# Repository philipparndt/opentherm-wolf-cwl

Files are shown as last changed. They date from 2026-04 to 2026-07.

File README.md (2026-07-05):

# Wolf CWL OpenTherm Decoder

Decoder tool for analyzing OpenTherm protocol communication between a BM remote control and a Wolf CWL ventilation/heat-recovery unit. Built to reverse-engineer the protocol for building a custom ESP32-based controller.

## Usage

```bash
# Default: human-readable deduplicated output
decode <file.sal|file.csv>

# Verbose: raw hex, parity, bit-timing analysis
decode <file> --verbose

# Diff: compare two captures side by side, highlights changes
decode diff <baseline.sal> <changed.sal>
```

Supports Saleae Logic 2 captures (`.sal`) and CSV exports (`.csv`). SAL files are significantly faster to process.

## Findings

### Control Summary

Everything needed to control the Wolf CWL via OpenTherm:

| Function | Method |
|---|---|
| **Ventilation level** | Write-Data to ID 71, value 0-3 |
| **Bypass open** | Set bit 1 in HI byte of ID 70 Read-Data request |
| **Bypass close** | Clear bit 1 in HI byte of ID 70 Read-Data request |
| **Filter reset** | Set bit 4 in HI byte of ID 70 Read-Data request (reset filter timer after replacement) |
| **Read temperatures** | Read-Data ID 80 (supply inlet), ID 82 (exhaust inlet) |
| **Read ventilation %** | Read-Data ID 77 |
| **Read bypass state** | Check `ventilation` bit (bit 1 HI byte) in ID 70 response |
| **Read fault status** | ID 72 (`Fault flags/code V/H`) — the HI-byte `fault` bit in ID 70 is *not* reliable on Wolf CWL, see notes below |
| **Read filter status** | Check **bit 5 of the LO byte** in ID 70 response (Wolf OEM use of a spec-reserved slave-status bit; the response HI byte is only an echo of the master flags) |

### Supported OpenTherm Data IDs

The Wolf CWL (tested with CWL Excellent, BM remote control as master) responds to the following data IDs:

| Data ID | Name | Type | Direction | Description |
|---|---|---|---|---|
| 2 | Master configuration | config/member-id | Write | Master flags=0x00, member-id=18 |
| 70 | Status V/H | flag8 | Read | Bidirectional: master sends control flags, slave returns status |
| 71 | Control setpoint V/H | u8 | Write | Ventilation level (0-3) |
| 72 | Fault flags/code V/H | flag8 | Read | Fault flags + OEM fault code |
| 74 | Config/member-ID V/H | config/member-id | Read | Slave flags=0x07, member-id=0 |
| 77 | Relative ventilation | u8 (%) | Read | Current ventilation percentage |
| 80 | Supply inlet temperature | f8.8 (°C) | Read | Fresh air intake temperature |
| 82 | Exhaust inlet temperature | f8.8 (°C) | Read | Room exhaust temperature |
| 89 | TSP index/value V/H | tsp | Read | Transparent Slave Parameters (see below) |
| 126 | Master product version | version | Write | type=18 version=2 |
| 127 | Slave product version | version | Read | type=0 version=0 (CWL does not respond) |

### Status V/H (ID 70) — Bidirectional Control

The Status V/H exchange carries control flags in **both directions**. This is the key mechanism for bypass control.

**Master → Slave (HI byte of Read-Data request):**

| Bit | Name | Description |
|-----|---|---|
| 0 | ch | Central heating / ventilation enable |
| 1 | **bypass** | **Bypass damper control: 1=open, 0=closed** |
| 2 | cooling | Cooling enable (if cooling register installed) |
| 3 | dhw | DHW enable |
| 4 | filter | Filter timer reset (set briefly after filter replacement) |
| 5 | diag | Diagnostics request |

**Slave → Master (Read-Ack response):**

The **HI byte of the Read-Ack is an echo of the master status flags** from the request — it carries no slave state. (Earlier revisions of this document interpreted it as a slave status byte and described a "permanently latched fault bit"; that was our own always-set ventilation-enable bit coming back.)

The actual slave status is the **LO byte**, laid out as in the OpenTherm V/H spec:

| Bit | Name | Description |
|-----|---|---|
| 0 | fault | Fault indication |
| 1 | ventilation | Ventilation mode active |
| 2 | bypass | Bypass status (1 = open) |
| 3 | bypass auto | Bypass automatic mode |
| 4 | free vent | Free ventilation status |
| 5 | **filter** | **Filter replacement required (1 = service due, 0 = OK).** Reserved in the spec; used by Wolf (Brink Renovent / Viessmann Vitovent OEM siblings) as the filter-check bit. |
| 6 | diag | Diagnostic indication |

Bit 5 was confirmed in `FIL_CLEAN.sal`, which captures the live transition during a filter-reset: LO went from `0x26` → `0x06` (bit 5 cleared) while HI stayed at `0x03` and ID 72 (Fault flags/code) stayed at `0x0000` throughout.

> **Do not derive filter status from ID 72.** An OEM fault code of 6 was once assumed to mean "filter dirty" (FIL2 hypothesis), but a live unit was observed reporting ID 72 = `0x0006` together with LO bit 6 (diagnostic indication) while the filter was clean and the CWL display showed no FIL — code 6 is a diagnostic status code, not the filter message. LO bit 5 is the only reliable filter signal.

The bypass is controlled by setting/clearing **bit 1 of the HI byte** in every Status V/H request; the actual damper state is reported in LO bit 2 (and TSP 54).

### Ventilation Level Control

Ventilation level is controlled via **Data ID 71** (Control setpoint V/H). The mapping is:

| Setpoint value | Mode | Relative ventilation (ID 77) |
|---|---|---|
| 0 | Off | 0% |
| 1 | Reduced | 51% |
| 2 | Normal | 67% |
| 3 | Party | 100% |

The `fault` bit in Status V/H (ID 70) may toggle briefly during mode transitions. This appears to be a transient state, not an actual fault indication.

### TSP Register Map

The BM remote cycles through TSP registers via Data ID 89, reading one index per polling cycle (~11 seconds per cycle). A full TSP scan takes approximately 5-6 minutes (31 indices).

TSP values did **not** change when switching ventilation levels or toggling bypass. Ventilation is controlled via ID 71, bypass via ID 70. TSPs hold configuration and live diagnostic data.

The Wolf CWL is OEM-identical to the **Brink Renovent HR** and **Viessmann Vitovent 300**. The TSP register map from the [Brink Renovent OpenTherm project](https://github.com/raf1000/brink_openhab) applies directly.

Many indices come in even/odd pairs for 16-bit values (even=LO, odd=HI byte).

#### Airflow Configuration (m³/h)

| TSP Index | Brink name | Value | Description |
|---|---|---|---|
| 0, 1 | U1 | 100, 0 | Airflow rate step 1 (Reduced): **100 m³/h** |
| 2, 3 | U2 | 130, 0 | Airflow rate step 2 (Normal): **130 m³/h** |
| 4, 5 | U3 | 195, 0 | Airflow rate step 3 (Party): **195 m³/h** |

#### Bypass & Temperature Settings

| TSP Index | Brink name | Value | Description |
|---|---|---|---|
| 6 | U4 | 20 | Bypass min. outdoor temp (value ÷ 2 = °C → **10 °C**). Bypass only opens when outdoor air ≥ this temperature. |
| 7 | U5 | 44 | Bypass min. indoor temp (value ÷ 2 = °C → **22 °C**). Bypass only opens when indoor air ≥ this temperature. |

#### Configuration Parameters

| TSP Index | Brink name | Value | Description |
|---|---|---|---|
| 11 | I1 | 100 | Fixed imbalance (value shifted by 100, so 100 = **0% imbalance**) |
| 17 | I7 | 1 | Pressure control / fan mode setting |
| 18 | I8 | 1 | Bypass configuration |
| 19 | I9 | 2 | Hysteresis / preheater setting |
| 20 | I10 | 0 | Additional config |
| 23 | I13 | 1 | Filter message setting |
| 24 | I14 | 0 | PCB configuration |
| 48, 49 | P18 | 193, 0 | Device/PCB config flags |

#### Live / Status Values (read-only, change during operation)

| TSP Index | Brink name | Value range | Description |
|---|---|---|---|
| 52, 53 | CurrentVol | 100-130, 0 | Current outlet volume **[m³/h]** |
| 54 | BypassStatus | 1 | Bypass valve position (0=shut, 1=auto, 2=open?) |
| 55 | TempAtmo | 114-118 | Atmospheric temperature (value − 100 = °C, so 114 → **14 °C**) |
| 56 | TempIndoors | 121 | Indoor temperature (value − 100 = °C, so 121 → **21 °C**) |
| 60, 61 | — | 0-130, 0 | Changes within captures — possibly supply/exhaust flow |
| 62, 63 | CurrentOutputVol | 100-113, 0 | Current output volume **[m³/h]** |
| 64, 65 | CPID | 20-215, 0-1 | Input duct pressure **[Pa]** |
| 66, 67 | CPOD | 196-255, 0 | Output duct pressure **[Pa]** |
| 68 | FrostStatus | 0 | Frost protection status (0 = no frost) |

### Data IDs to Probe

The BM remote only polls a subset of the available V/H data IDs. The following IDs are defined in the OpenTherm V/H spec and may be supported by the CWL, but have not been tested yet. Probe these with the ESP32 firmware to discover additional sensors:

| Data ID | Name | Type | Notes |
|---|---|---|---|
| 78 | Relative humidity exhaust | u8 (%) | Humidity sensor (if installed) |
| 79 | CO2 level exhaust | u16 (ppm) | CO2/VOC sensor (if installed) |
| 81 | Supply outlet temperature | f8.8 (°C) | Temperature after heat recovery |
| 83 | Exhaust outlet temperature | f8.8 (°C) | Temperature after heat recovery |
| 84 | Exhaust fan speed | u16 (rpm) | Fan speed diagnostics |
| 85 | Supply fan speed | u16 (rpm) | Fan speed diagnostics |
| 87 | Nominal ventilation value | u8 | Configured nominal airflow |
| 88 | TSP count V/H | u8 | Total number of TSP registers supported |

If the CWL supports a data ID, it will respond with Read-Ack. If not, it will either not respond or send Unknown-DataId.

### Polling Cycle

The BM remote polls the CWL in a fixed cycle of approximately 11 seconds containing:

1. Master configuration (ID 2) — Write-Data
2. Status V/H (ID 70) — Read-Data with master control flags
3. Control setpoint V/H (ID 71) — Write-Data
4. Config/member-ID V/H (ID 74) — Read-Data
5. Relative ventilation (ID 77) — Read-Data
6. Supply inlet temperature (ID 80) — Read-Data
7. Exhaust inlet temperature (ID 82) — Read-Data
8. Master product version (ID 126) — Write-Data
9. Slave product version (ID 127) — Read-Data (no response from CWL)
10. TSP index/value V/H (ID 89) — Read-Data, rotates through different index each cycle
11. Fault flags/code V/H (ID 72) — Read-Data (sometimes included)

## ESP32 Firmware Guide

The firmware serves a web UI with live status and a 24 h history view — supply/exhaust temperatures, indoor/outdoor humidity and enthalpy, bypass state, and ventilation level changes annotated with the reason for each switch:

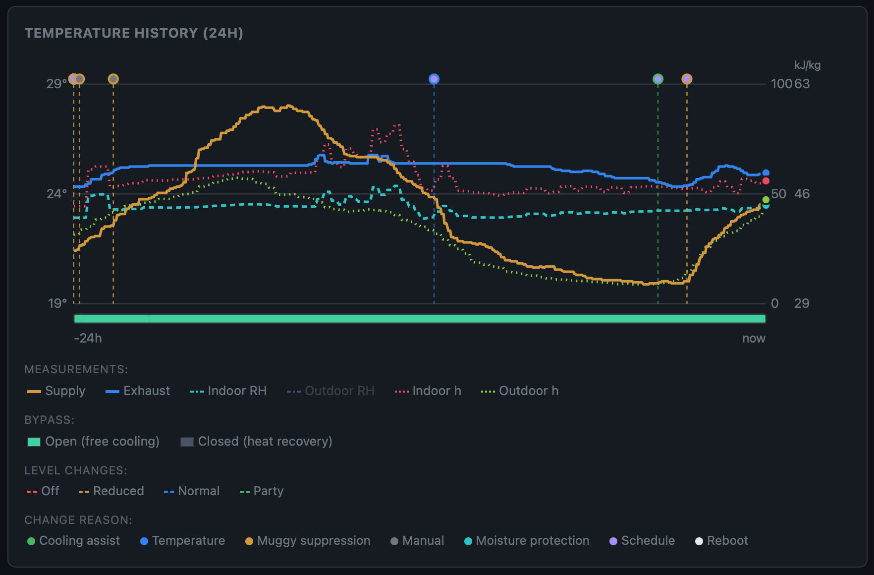
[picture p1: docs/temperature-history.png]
Temperature history (24 h) in the web UI


### Minimal Polling Loop

To replicate the BM's communication, the ESP32 firmware should send these requests in a loop (~1 second between each):

```
1. Write-Data  ID=2   value=0x0012        (master config: member-id=18)
2. Read-Data   ID=70  value=0x0N00        (status: HI byte = control flags, N = bypass bit)
3. Write-Data  ID=71  value=0x000L        (ventilation level: L = 0-3)
4. Read-Data   ID=74  value=0x0000        (read config/member-id)
5. Read-Data   ID=77  value=0x0000        (read relative ventilation %)
6. Read-Data   ID=80  value=0x0000        (read supply inlet temp)
7. Read-Data   ID=82  value=0x0000        (read exhaust inlet temp)
8. Read-Data   ID=89  value=0xII00        (read TSP index II)
```

### Bypass Control

In step 2, set the HI byte of the request value:
- `0x0100` — bypass closed, ventilation enabled (ch=on)
- `0x0300` — bypass open, ventilation enabled (ch=on, bypass=on)

The slave response HI byte confirms the state:
- Bit 0: fault
- Bit 1: ventilation/bypass active

### Ventilation Levels

In step 3, set the LO byte:
- `0x0000` — Off (0%)
- `0x0001` — Reduced (51%)
- `0x0002` — Normal (67%)
- `0x0003` — Party (100%)

## Hardware

### Capture Setup (passive analysis)

- **Saleae Logic 2** analyzer tapping the OpenTherm bus between BM remote and CWL unit
- Analog capture at 1.5625 MHz sample rate
- OpenTherm signal: Manchester encoded at ~1000 baud
- Request (master→slave): ~10.8V peak
- Response (slave→master): ~7.3V peak

### Controller Hardware

- **DIYLess Master OpenTherm Shield** — handles OpenTherm electrical signaling
- **ESP32** (e.g. WeMos D1 mini ESP32) — runs custom firmware
- **[ihormelnyk/opentherm_library](https://github.com/ihormelnyk/opentherm_library)** — Arduino library for OpenTherm master communication

The DIYLess shield acts as the OpenTherm master, replacing the BM remote control. The ESP32 can then:
- Read all sensor values (temperatures, ventilation %, status, faults)
- Set ventilation level by writing to Data ID 71 (values 0-3)
- Control bypass via Status V/H (ID 70) master flags
- Read TSP registers for diagnostics
- Publish data via MQTT to Home Assistant (see [docs/mqtt-topics.md](docs/mqtt-topics.md) for the full topic reference)

### ESPHome Compatibility

The official ESPHome OpenTherm component does **not** support V/H (ventilation/heat-recovery) data IDs 70-91. It only supports boiler/heating control. A custom firmware is required for the Wolf CWL.

## Building

```bash
cd decode
go build -o decode .
```

Requires Go 1.26+.

## Schedules

Weekday schedule:
```
0:00 - 8:00 reduced
8:00 - 13:00 normal
13:00 - 15:00 reduced
15:00 - 18:00 normal
18:00 - 0:00 reduced
```

Weekend schedule:
```
0:00 - 10:00 reduced
10:00 - 13:00 normal
13:00 - 15:00 reduced
15:00 - 18:30 normal
```

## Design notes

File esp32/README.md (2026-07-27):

# Wolf CWL — ESP32 Firmware

Rust firmware for the Olimex ESP32-POE board that drives a Wolf CWL ventilation unit over OpenTherm. Networking is selectable at build time (Ethernet on the Olimex POE port, or WiFi).

## Prerequisites

One-time, outside this Makefile:

1. **Rust + the Xtensa ESP toolchain via [espup](https://github.com/esp-rs/espup).**
   ```bash
   cargo install espup
   espup install
   ```
   `espup install` writes `~/export-esp.sh`, which sets `LIBCLANG_PATH` and prepends the Xtensa cross-compiler to `PATH`.

2. **Source the espup env from your shell rc** so `make` picks it up:
   ```bash
   echo 'source ~/export-esp.sh' >> ~/.zshrc && exec zsh
   ```

3. **Plug in the board** and confirm the OS sees it:
   ```bash
   ls /dev/cu.*
   ```
   Look for `cu.usbserial-*` (CP210x — native on macOS 11+, no extra driver) or `cu.wchusbserial-*` (CH340/CH341 — older boards may need the [WCH driver](https://www.wch.cn/downloads/CH341SER_MAC_ZIP.html)).

## First-time setup

```bash
cd esp32
make setup
cp .env.example .env
$EDITOR .env          # WIFI_SSID, WIFI_PASSWORD, optional PORT
```

`make setup` installs the two Rust binaries the build needs (`ldproxy`, `espflash`) and patches a Python venv quirk that otherwise breaks the ESP-IDF dependency check (see [Troubleshooting](#troubleshooting)).

## Build targets

| Target | Network | OpenTherm |
|---|---|---|
| `make dev` | Ethernet | Simulated |
| `make prod` | Ethernet | Real |
| `make dev-wifi`  | WiFi | Simulated |
| `make prod-wifi` | WiFi | Real |

All four build, flash, and open the serial monitor. WiFi targets require `WIFI_SSID` / `WIFI_PASSWORD` in `esp32/.env` — those credentials are forwarded by `build.rs` and compiled into the firmware as a fallback when NVS has no stored credentials (so a freshly-flashed board joins the network without going through the web setup wizard first).

`make help` lists every target.

## `.env`

Loaded by the Makefile as Makefile syntax (not shell), so:

- No quotes around values.
- Avoid `#` and `$` in passwords — both are Make-special. If you must use them, change the password.
- The file is git-ignored.

| Variable | Used by | Notes |
|---|---|---|
| `WIFI_SSID` | `build.rs` (env!) | Required for `dev-wifi` / `prod-wifi`. |
| `WIFI_PASSWORD` | `build.rs` (env!) | Required for `dev-wifi` / `prod-wifi`. |
| `PORT` | `espflash` flag | Optional. Defaults to `/dev/cu.wchusbserial8310`. Override per board. |

## Feature flags

Defined in `Cargo.toml`. The Makefile targets compose these; you rarely need to set them by hand:

- `wifi` / `ethernet` — pick one network stack.
- `simulate-ot` — fake OpenTherm slave for desk testing.
- `ot-uext` / `ot-ext` — which GPIO pair to use for OpenTherm (UEXT default).
- `display-rotate` — rotate the OLED 180° for upside-down mounting.
- `display-sh1106` / (default `ssd1306`) — pick OLED driver chip.

## Web UI login

The UI and the REST API are protected by a cookie login (default `admin` / `admin`, changeable under **Settings → Web UI**).

On a trusted LAN the prompt is mostly friction, so it can be switched off: **Settings → Web UI → Require login**. With it off, `is_authenticated()` short-circuits and every endpoint — including `/api/config`, `/api/restore` and both OTA uploads — is open to anyone who can reach port 80. The toggle is persisted in NVS (`web_auth`) and takes effect immediately, without a reboot; it defaults to **on**, so a firmware update never silently unlocks a device.

The `make ota*` targets log in first and then send the cookie. That still works with the login disabled — `/api/login` accepts any credentials in that mode — so `OTA_USER` / `OTA_PASS` can be left at their defaults.

## Troubleshooting

### `Error while connecting to device`

`espflash` can't talk to whatever's at `PORT`. Confirm the port name (`ls /dev/cu.*`) and set `PORT=...` in `.env`, or pass `make ... PORT=/dev/cu.foo`. If the port is correct, hold the BOOT button while espflash resets the chip.

### `Failed to open file: partitions.csv`

A 4MB layout with NVS + factory app + a 960KB SPIFFS partition labeled `spiffs` is committed at `esp32/partitions.csv`. The SPIFFS offset/size must stay in sync with `SPIFFS_OFFSET` / `SPIFFS_SIZE` in the Makefile and the `partition_label` passed to `esp_vfs_spiffs_register` in `main.rs`. Don't edit it without updating all three.

### `Failed to run Python dependency check ... Error: 255` during `esp-idf-sys` build

The ESP-IDF Python venv ships with a `ruamel.yaml` whose `.dist-info` directory uses underscores (`ruamel_yaml-*.dist-info`), but Python 3.9's `importlib.metadata.version('ruamel.yaml')` doesn't normalize dotted names → the dep check exits 255 → CMake aborts. `make fix-python-env` symlinks the dotted names; it runs automatically before every `build` target and is also re-runnable on its own. If you see this error after a fresh `.embuild`, run:

```bash
make fix-python-env
```

### `linker 'ldproxy' not found` or `espflash: command not found`

You haven't run `make setup` yet (or `~/.cargo/bin` isn't on `PATH`). Both binaries land in `~/.cargo/bin`, which espup adds automatically — but `make` runs in `/bin/sh` and only sees the inherited `PATH`. Make sure your shell rc sources `~/export-esp.sh` and exports `~/.cargo/bin`.

### Switching between `ethernet` and `wifi` triggers a long rebuild

Expected. Cargo rebuilds `esp-idf-sys` from scratch when feature flags change, which re-runs the CMake dep check (see above). Initial WiFi build is ~10 minutes; subsequent incremental builds are seconds.

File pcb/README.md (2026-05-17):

# Wolf CWL Controller — Shield PCB

Shield board that stacks on top of an [Olimex ESP32-POE](https://www.olimex.com/Products/IoT/ESP32/ESP32-POE/open-source-hardware) via the UEXT connector. Provides the OpenTherm interface, OLED display, and rotary encoder.

## UEXT Connector Pinout (ESP32-POE)

The [UEXT](https://www.olimex.com/Products/Modules/UEXT/) is a 10-pin 2x5 box header (2.54 mm pitch) providing I²C, SPI, and UART:

| UEXT Pin | Signal | ESP32 GPIO | Used For |
|---|---|---|---|
| 1  | 3.3V | — | Power |
| 2  | GND  | — | Ground |
| 3  | TXD  | GPIO 4  | OpenTherm TX (via SB3) |
| 4  | RXD  | GPIO 36 | OpenTherm RX (via SB4) |
| 5  | SCL  | GPIO 16 | OLED Display |
| 6  | SDA  | GPIO 13 | OLED Display |
| 7  | MISO | GPIO 15 | Encoder CLK |
| 8  | MOSI | GPIO 2  | Status LED |
| 9  | SCK  | GPIO 14 | Encoder DT |
| 10 | SS | GPIO 5  | Encoder SW |

## Variants

| Variant | Project | Notes |
|---|---|---|
| `cwl` (default) | `cwl/cwl.kicad_pro` | Main board. Melnyk-topology on-board OpenTherm front-end. Combined OLED footprint accepts either a 0.96″ or 1.3″ SH1106 module. |
| `cwl-diyless` | `cwl-diyless/cwl.kicad_pro` | Off-board OpenTherm interface via a DIYless D1-mini shield. Separate J3 / J3B footprints for the two OLED sizes. |

## Bill of Materials (`cwl`)

| Ref | Part | Value / Mfr P/N | Footprint | Symbol | Mouser # | Qty |
|-----|---|---|---|---|---|-----|
| J1 | UEXT 2×5 IDC socket | HIF3FB-10DA-2.54DSA(69) (Hirose) | `IDC:IDC-Stecker_2x05_P2.54mm_Vertical` | `Connector_Generic:Conn_02x05_Odd_Even` | 798-HIF3FB10DA254D69 | 1 |
| J2 | Screw terminal, 2-pos 5.08 mm | MKDS 1,5/2-5,08 (Phoenix Contact) | `TerminalBlock_Phoenix:TerminalBlock_Phoenix_MKDS-1,5-2-5.08_1x02_P5.08mm_Horizontal` | `Connector:Conn_01x02_Pin` | 651-1729018 | 1 |
| J3 | OLED header (0.96″ + 1.3″ combined) | 4-pin header (use module's own header) | `SSD1306:128x64OLED-MountingHoles-Combined` | `Connector:Conn_01x04_Pin` | — | 1 |
| U1, U2 | Optocoupler, SOIC-4 | LTV-817S-B (Lite-On) | `Package_SO:SOP-4_7.5x4.1mm_P2.54mm` | `Isolator:PC817` | 859-LTV-817S-B | 2 |
| Q1 | PNP BJT, SOT-23 | BC858A or BC858B (Nexperia) | `Package_TO_SOT_SMD:SOT-23` | `Transistor_BJT:BC858` | 771-BC858A,215 | 1 |
| D1–D4 | Switching diode, SOD-323 | 1N4148WS (Vishay) | `Diode_SMD:D_SOD-323` | `Device:D` | 78-1N4148WS-HG3_A-08 | 4 |
| D5 | 4.7 V zener, SOD-123, 500 mW | BZT52C4V7 (Vishay) | `Diode_SMD:D_SOD-123` | `Device:D_Zener` | 78-BZT52C4V7-E3-08 | 1 |
| D6 | 15 V zener, SOD-123, 500 mW | BZT52C15 (Vishay) | `Diode_SMD:D_SOD-123` | `Device:D_Zener` | 78-BZT52C15-E3-08 | 1 |
| D7 | 4.3 V zener, SOD-123, 500 mW | BZT52C4V3 (Vishay) | `Diode_SMD:D_SOD-123` | `Device:D_Zener` | 78-BZT52C4V3-E3-08 | 1 |
| R1, R4 | 330 Ω, 0603, 1 % | RC0603FR-07330RL (Yageo) | `Resistor_SMD:R_0603_1608Metric` | `Device:R` | 603-RC0603FR-07330RL | 2 |
| R2 | 220 Ω, 0603, 1 % | RC0603FR-07220RL (Yageo) | `Resistor_SMD:R_0603_1608Metric` | `Device:R` | 603-RC0603FR-07220RL | 1 |
| R3 | 100 Ω, 0603, 1 % | RC0603FR-07100RL (Yageo) | `Resistor_SMD:R_0603_1608Metric` | `Device:R` | 603-RC0603FR-07100RL | 1 |
| R5 | 1.5 kΩ, 0603, 1 % | RC0603FR-071K5L (Yageo) | `Resistor_SMD:R_0603_1608Metric` | `Device:R` | 603-RC0603FR-071K5L | 1 |
| R6, R7 | 10 kΩ, 0603, 1 % | RC0603FR-0710KL (Yageo) | `Resistor_SMD:R_0603_1608Metric` | `Device:R` | 603-RC0603FR-0710KL | 2 |
| R8 | 1 kΩ, 0603, 1 % | RC0603FR-071KL (Yageo) | `Resistor_SMD:R_0603_1608Metric` | `Device:R` | 603-RC0603FR-071KL | 1 |
| SW1 | Rotary encoder w/ switch | EC12E2424407 (Alps Alpine) | `Rotary_Encoder:RotaryEncoder_Alps_EC12E-Switch_Vertical_H20mm` | `Device:RotaryEncoder_Switch` | — | 1 |
| LED1 | Green LED, 0805 | SML-LXT0805GW-TR (Lumex) | `LED_SMD:LED_0805_2012Metric` | `Device:LED` | 696-SML-LXT0805GW | 1 |
| MH1–MH4 | M3 mounting hole, GND-tied | — | `MountingHole:MountingHole_3.2mm_M3_Pad_Via` | `Mechanical:MountingHole_Pad` | — | 4 |
| SB3, SB4 | UEXT TX/RX → OT routing bridges (etched into board, no part) | — | `Jumper:SolderJumper-2_P1.3mm_Bridged_RoundedPad1.0x1.5mm` | `Jumper:SolderJumper_2_Bridged` | — | — |
| — | 0.96″ SH1106 OLED module, I²C, 4-pin | — | — | — | (Amazon / AliExpress) | 1 (pick one) |
| — | 1.3″ SH1106 OLED module, I²C, 4-pin | — | — | — | (Amazon / AliExpress) | 1 (pick one) |

## Build targets

```
make generate-3d      # regenerate the local STEP models in 3dmodels/
make export-stl-full  # full PCB assembly STL (VARIANT=cwl by default)
make export-stl-print # version with floating IDC socket for 3D printing
make export-stl-board # bare PCB only
make export-stl-parts # components only (no board)
make gerber           # Gerbers + drills (zipped)
make plot-pdf         # front + back assembly PDFs
make ibom             # Interactive HTML BOM (needs InteractiveHtmlBom plugin)
make clean            # remove generated artifacts
```

Set `VARIANT=cwl-diyless` to target the diyless project instead.

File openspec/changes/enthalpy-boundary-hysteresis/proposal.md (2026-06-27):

## Why

The humidity-aware decision (`humidity::enthalpy_level`) splits "ventilate to cool" from "hold
down (muggy)" at **exactly Δh = 0** (`Δh = h_out − h_in`), with no deadband:

```rust
} else if dh > 0.0 {        // Reduced  (MuggySuppression)
} else if dh >= H_PARTY {   // Normal   (CoolingAssist)
```

Every other boundary in the system is guarded — the bypass damper (`EH_BYPASS_HYST`), moisture
protection (`RH_HYSTERESIS`), the Off edge (`H_OFF = +2`) and the Party edge (`H_PARTY = −4`) — but
the Reduced↔Normal crossing at zero is bare. Two consecutive live readings demonstrate the problem:

| | Indoor h | Outdoor h | Δh | Rule shown | Level |
|---|---|---|---|---|---|
| 1 | 63.2 | 63.5 | +0.3 | Muggy suppression | Reduced |
| 2 | 63.2 | 63.3 | ≈0 (rounded) | Cooling assist | Normal |

Between the two, the outdoor air actually got **0.1 °C warmer** (31.0 → 31.1 °C) and barely drier,
yet the decision flipped from "hold down" to "ventilate to cool". The true Δh merely crossed zero by
a hair. Two problems compound:

1. **The boundary is resolved finer than the inputs are accurate.** Δh is acted on at ~0.1 kJ/kg,
   while a typical DHT humidity sensor (±2–5 % RH) carries ~±1–2 kJ/kg of enthalpy uncertainty. The
   controller is reacting to noise. The 15-min dwell rate-limits the *fan*, but the displayed reason
   refreshes every 60 s (`extreme_heat.rs` keeps the level, refreshes the reason), so the user sees
   the rule flicker Muggy↔Cooling even while the fan is held; and if Δh sits on the boundary the fan
   can still hunt every dwell window.
2. **"Cooling assist" oversells near Δh = 0.** Equal enthalpy ≈ equal wet-bulb temperature, so
   pulling in 31 °C air to a 27 °C room does not actually cool — it trades humidity for sensible
   heat. Real cooling only exists once outdoor energy is clearly lower (which is exactly why the
   Party edge already keeps a −4 margin).

And when the mode is *deliberately* holding — because Δh is inside the neutral deadband, or because
the dwell timer hasn't elapsed — the UI gives no reason for the non-switch. The user cannot tell
"holding on purpose" from "stuck / broken".

## What Changes

- Add **state-dependent hysteresis around Δh = 0** to `enthalpy_level`: enter cooling
  (Normal/CoolingAssist) only when `Δh < H_COOL_ON`, release back to hold-down
  (Reduced/MuggySuppression) only when `Δh > H_COOL_OFF`, and **hold the current state** in the
  neutral band between them. `Party` (`Δh < H_PARTY`) and `Off` (`Δh > H_OFF`) bands are unchanged.
- Make `CoolingAssist` mean *actual* cooling: the "ventilate to cool" reason is only claimed once
  cooling has been entered past `H_COOL_ON`, never on a marginal sub-band crossing.
- **Surface the hold reason in the decision explainer:** when the level is not switched because the
  energy delta is inside the neutral deadband, or because the dwell timer has not elapsed, the panel
  states that explicitly (which guard is holding, and — for the dwell — how much longer).
- Clarify the explainer's outdoor/indoor figures so the displayed `T / RH / AH / h` no longer reads
  as one inconsistent air mass (RH is the max-RH sensor; AH/h come from the wettest sensor
  re-expressed at the aggregate temperature — they legitimately come from different sensors).
- **Boot robustness & honest level (from live-device findings):** don't derive an air state from an
  untrustworthy fallback temperature, and don't show the derived enthalpy in the explainer until the
  unit is connected — this removes the boot-transient "indoor h ≈ 37.9" glitch. The ventilation
  display shows the unit's **actual** running level (ID 77), not the commanded one (ID 71), since the
  two can differ. The explainer always shows a state (a "waiting for the unit" notice while
  disconnected) and every reason has a plain-language explanation.

## Capabilities

### Modified Capabilities
<!-- humidity-aware-ventilation and humidity-decision-visualization are defined in the still-active
     `extreme-heat-humidity` change, not yet archived to openspec/specs/. Following that change's
     own precedent (layering onto un-archived extreme-heat-mode), the boundary-stability behaviour
     is expressed as ADDED requirements that refine the existing enthalpy bands, rather than as a
     MODIFIED delta against a baseline spec that does not yet exist. -->

- `humidity-aware-ventilation`: add boundary hysteresis so the Reduced↔Normal (hold-down↔cooling)
  decision no longer toggles on noise around equal energy, and tie the `CoolingAssist` reason to
  having actually entered cooling.
- `humidity-decision-visualization`: explain *why a switch is being withheld* (neutral deadband or
  dwell), and present the aggregated air figures without implying a single consistent air mass.

## Impact

- Firmware: `esp32/src/humidity.rs` (`enthalpy_level` gains a `was_cooling` argument and the
  `H_COOL_ON` / `H_COOL_OFF` constants + the neutral-band hold), `esp32/src/extreme_heat.rs` (pass
  the current cooling state into `decide`/`enthalpy_level`, and expose a "hold reason" — deadband vs
  dwell-remaining — alongside the active reason), `esp32/src/app_state.rs` (carry the hold reason /
  dwell-remaining for the status payload).
- API/Web: `/api/status` gains the hold reason + dwell-remaining; `StatusTab.tsx` decision-explainer
  renders the "holding because …" line and the clarified air-figure labels; `translations.ts`.
- Behaviour: no change to the Off/Party bands, the 15-min dwell, manual stickiness, or the
  temperature-only fallback. Tuning constants only widen the neutral region around Δh = 0.

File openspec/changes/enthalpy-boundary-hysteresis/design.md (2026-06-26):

## Context

`humidity::enthalpy_level` (`esp32/src/humidity.rs`) maps the enthalpy delta `Δh = h_out − h_in`
onto a ventilation level + a cooling flag:

```rust
pub fn enthalpy_level(inp: &HumidityInputs) -> (VentLevel, bool) {
    let dh = inp.outdoor.h - inp.indoor.h;
    if dh > H_OFF { (Off, false) }          // H_OFF  =  2.0
    else if dh > 0.0 { (Reduced, false) }   // <-- bare boundary at exactly 0
    else if dh >= H_PARTY { (Normal, true) }// H_PARTY = -4.0
    else { (Party, true) }
}
```

`extreme_heat::decide` turns the cooling flag into the displayed `Reason` (`CoolingAssist` vs
`MuggySuppression`) and the caller floors the level at `Reduced` (a fully-off CWL leaves stale duct
air). So the *only* boundary that changes the actual fan level between hold-down and active cooling
is the `dh > 0.0` test — and it has no hysteresis and no state memory, unlike every other decision
edge in the codebase (`EH_BYPASS_HYST`, `RH_HYSTERESIS`, and the `±2 / −4` margins on the Off/Party
edges). The dwell (`EH_DWELL_SECS = 15 min`) rate-limits fan *changes* but the reason is refreshed
every eval (60 s), so the displayed rule flickers Muggy↔Cooling on noise, and a Δh parked near zero
still hunts once per dwell window.

Two real readings (indoor h = 63.2 both times; outdoor h 63.5 → 63.3; outdoor T 31.0 → **31.1 °C**)
flipped the decision from MuggySuppression/Reduced to CoolingAssist/Normal even though the outdoor
air got *warmer*. The displayed figures only carry one decimal (0.1 kJ/kg), finer than DHT-class
sensors are accurate (±2–5 % RH ≈ ±1–2 kJ/kg). The control is chasing noise.

## Goals / Non-Goals

**Goals**
- A neutral band around `Δh = 0` within which the Reduced↔Normal (hold-down↔cooling) state is
  *held*, so sensor noise no longer flips the level or the displayed reason.
- `CoolingAssist` is only claimed when cooling has genuinely been entered (Δh clearly negative), not
  on a marginal zero-crossing.
- The explainer states *why a switch is being withheld* — neutral deadband, or dwell not elapsed
  (with remaining time) — so a deliberate hold is distinguishable from a fault.
- The explainer's air figures no longer read as a single inconsistent air mass.

**Non-Goals**
- No change to the Off (`> +2`) or Party (`< −4`) bands, the 15-min dwell, manual stickiness, the
  bypass-damper logic, or the temperature-only fallback.
- No new persisted/NVS state — the cooling state is derived from the current reason, the
  dwell-remaining is computed from the existing `eh_last_change_epoch`.
- No sensor-fusion or accuracy improvements — this is purely about boundary stability and legibility.

## Decisions

### Hysteresis band around Δh = 0

Introduce two constants and a `was_cooling` input, mirroring `protection_level(&inp, was_active)`:

```rust
/// Enter cooling (favour ventilating) only once outdoor air is at least this much
/// lower-energy than indoor (kJ/kg). Above H_COOL_OFF, release back to hold-down.
pub const H_COOL_ON: f32 = -1.0;
pub const H_COOL_OFF: f32 = 0.0;

pub fn enthalpy_level(inp: &HumidityInputs, was_cooling: bool) -> (VentLevel, bool) {
    let dh = inp.outdoor.h - inp.indoor.h;
    if dh > H_OFF { return (VentLevel::Off, false); }
    if dh < H_PARTY { return (VentLevel::Party, true); }
    // Neutral band [H_COOL_ON, H_COOL_OFF]: hold whatever we were doing.
    let cooling = if was_cooling { dh < H_COOL_OFF } else { dh < H_COOL_ON };
    if cooling { (VentLevel::Normal, true) } else { (VentLevel::Reduced, false) }
}
```

- Not cooling → only switch to cooling when `Δh < −1.0`.
- Already cooling → only release when `Δh > 0.0`.
- Between the two it holds, so a Δh wandering across zero by noise changes nothing.

`H_COOL_ON = −1.0` is ~ one sensor-noise unit below zero — small enough that genuine cooling
opportunities are still taken, large enough to clear DHT jitter. Tunable; documented next to the
existing `H_OFF`/`H_PARTY`.

**Why this band and not just rounding Δh:** rounding still flips at the rounded boundary. State-
dependent hysteresis is what the rest of the codebase already uses; this makes the energy decision
consistent with it.

### Deriving `was_cooling` without new state

`extreme_heat::decide` already holds `st.eh_current_reason`. Treat `Reason::CoolingAssist` as the
"currently cooling" state; anything else (MuggySuppression, Dehumidify, TempDelta, Manual) is
not-cooling. No new field, survives the retained-snapshot restore for free (reason is already
restored).

### Hold reason for the explainer

`decide` currently returns `(level, reason)`. Extend the status path so the UI can show *why no
switch happened*. The level is withheld for exactly two reasons, both already computable in
`update()`:

- **Neutral deadband:** `enthalpy_level` returned the same level it’s holding because Δh is inside
  `[H_COOL_ON, H_COOL_OFF]`. Surface a flag like `hold = Deadband` with the current Δh and the band.
- **Dwell:** a *different* level was decided but `now_epoch − eh_last_change_epoch < EH_DWELL_SECS`.
  Surface `hold = Dwell` with `remaining = EH_DWELL_SECS − elapsed` seconds and the level it would
  switch to.

Expose these on `/api/status` (e.g. `holdReason`, `dwellRemainingSecs`, `pendingLevel`) so the
explainer can render "Holding Reduced — outdoor energy within the neutral band (Δh +0.1 kJ/kg)" or
"Holding Reduced — would switch to Normal in 7 min (dwell)". When nothing is held, the fields are
absent/null and the panel shows the active rule as today.

### Air-figure labelling (smaller)

The explainer prints `Outdoor (T / RH / AH / h)` as if one air mass, but `aggregate_side` sets `rh`
to the **max-RH** sensor while `ah`/`h` come from the **wettest** sensor re-expressed at the
aggregate (lowest) temperature — legitimately different sensors, so e.g. 31.1 °C / 24.6 % does not
reconcile with AH 13.5 g/m³ by hand. Relabel/group so this is clear (e.g. show RH as "max RH" and
AH/h as "from wettest sensor @ aggregate T"), or add a one-line note. No logic change.

## Risks / Trade-offs

- **Missed cooling in the −1…0 band.** When Δh is between −1 and 0 and we were not already cooling,
  we now hold Reduced instead of going Normal. That foregoes at most ~1 kJ/kg of marginal cooling
  that is within sensor noise anyway — an acceptable trade for stability. If field data shows it’s
  too conservative, lower `H_COOL_ON` toward −0.5.
- **`was_cooling` from the reason couples decision to display state.** Mitigated: the reason is
  already the single source of truth for the cooling flag and is persisted/restored; no divergence.
- **Tests that call `enthalpy_level(&inp)` must pass the new arg.** Mechanical; covered in tasks.

## Migration / Tuning

Pure firmware + web change; no config or NVS migration. New constants ship with defaults
`H_COOL_ON = −1.0`, `H_COOL_OFF = 0.0`. The boundary near the old `dh > 0.0` behaviour is recovered
by setting both to `0.0`.

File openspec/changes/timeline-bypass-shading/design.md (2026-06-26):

## Context

The temperature timeline already runs independently in the backend: `history.rs`
(`TempHistory`) folds supply/exhaust temperatures and indoor/outdoor humidity into rolling
ring buffers every second, persisted to MQTT under `persist/temp_history` separately from the
extreme-heat snapshot (`persist/extreme_heat`). The web chart (`ExtremeHeatChart.tsx`) is
rendered unconditionally in `StatusTab.tsx` and fetches `/api/history`, which embeds the
extreme-heat level-change events (`eh_events`) as its `events` array.

So the coupling is mostly *naming and framing*: the component, its events overlay, and the
mental model present the timeline as an extreme-heat artifact. Separately, there is **no
record of bypass state over time** — `requested_bypass_open` is a single live boolean set
from three places (extreme-heat in `extreme_heat.rs`, the calendar schedule in `scheduler.rs`,
and manual web/MQTT/encoder paths), with no history.

The bypass toggles only a handful of times per day, so a small transition log is sufficient to
reconstruct its state across the 24 h window — the same shape as the existing `eh_events`
ring buffer.

## Goals / Non-Goals

**Goals:**
- Reframe the chart as a standalone temperature timeline that does not depend on Extreme Heat
  mode; extreme-heat level changes remain an optional overlay.
- Record bypass open/closed transitions across the history window and persist them with the
  history snapshot.
- Render the chart background in two gray tones — base gray for bypass-closed spans, a
  slightly brighter gray for bypass-open spans — aligned to the time axis, behind the curves.

**Non-Goals:**
- No change to *how* the bypass is decided (that is the extreme-heat-bypass-coupling change).
- No new HTTP endpoint and no config/NVS schema change.
- No per-second bypass sampling into a min/max bucket — bypass is a sparse boolean state, so a
  transition log is the right model, not a `Channel`.
- No change to the extreme-heat level-change marker semantics.

## Decisions

### Model bypass history as a transition log, not a history Channel
Add a bounded ring buffer of `{epoch, open}` transitions to `AppStateInner` (e.g.
`bypass_events: VecDeque<BypassEvent>`, capped like `EH_EVENT_CAPACITY`). A transition is
appended only when `requested_bypass_open` actually changes. Rationale: bypass is a piecewise-
constant boolean that changes a few times a day; a transition log is far cheaper than a
1440-slot channel and reconstructs exact band edges, whereas per-bucket booleans would blur
edges and bloat the payload. Alternative considered: a boolean `Channel` per bucket — rejected
(memory + edge precision). Recording happens at a single chokepoint: a small helper that all
three writers (extreme-heat, scheduler, manual/MQTT) funnel `requested_bypass_open` through,
so no writer can change the damper without logging it.

### Reconstruct the left-edge state from the earliest known transition
To paint from the oldest visible column, the frontend needs the bypass state at the window's
left edge. The state in the span *before* the earliest transition in the buffer is the inverse
of that transition's `open` value (a transition flips the state). With the cap sized to cover
24 h of realistic toggling this is exact; if the buffer ever overflows, the worst case is one
mislabeled leading span, which is acceptable for a background tint.

### Expose via the existing `/api/history` payload
`TempHistory::full_json` already takes a pre-serialized `events` string; add a parallel
`bypass` array of `{epoch, open}` built in `webserver.rs` from `bypass_events` (same way
`events` is built from `eh_events`). Keeps one fetch and one render pass. Persist the
transitions inside the retained `persist/temp_history` snapshot (not the extreme-heat one), so
the shading survives reboots together with the curves it annotates.

### Render as background `<rect>` bands behind everything
In the chart, before drawing gridlines/series, emit one `<rect>` per bypass span spanning
`PAD_T..PAD_T+PLOT_H`, x-mapped with the existing `eventX` epoch→x helper, filled with a base
gray (closed) or a slightly brighter gray (open). Two CSS custom properties
(e.g. `--chart-bg`, `--chart-bg-bypass`) keep the tones theme-aware and the difference subtle.
Add a legend swatch + EN/DE strings explaining "bypass open / closed".

### Rename the component, keep extreme-heat markers as an overlay
Rename `ExtremeHeatChart.tsx` → `TimelineChart.tsx` (and the export) and update the import in
`StatusTab.tsx`. The level-change markers and their legend stay, but are now clearly an
overlay on a general-purpose timeline. No behavioural change to the markers.

## Risks / Trade-offs

- **Buffer overflow on a pathological day (many toggles)** → the cap covers far more than the
  realistic few-per-day; on overflow only the oldest leading span tint may be wrong, never the
  curves. Mitigation: size the cap generously and drop oldest first.
- **Subtle two-gray difference may be invisible in some themes** → expose both tones as CSS
  variables per theme and pair the shading with a legend entry so it is discoverable; keep the
  brighter tone clearly distinguishable but not loud (it is context, not a series).
- **Pre-existing retained snapshots lack the bypass list** → treat a missing `bypass` field as
  "no shading data yet"; the chart renders exactly as today until new transitions accrue.

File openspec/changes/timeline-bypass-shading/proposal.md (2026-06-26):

## Why

The temperature-history timeline is framed as part of Extreme Heat mode — the chart
component is `ExtremeHeatChart`, and the only context it overlays is extreme-heat
level-change events — even though the underlying history is sampled continuously and is
useful on its own. At the same time, the **bypass damper** is now a first-class cooling
control (it follows the supply/exhaust signal in Extreme Heat mode), but the timeline gives
no indication of *when the bypass was open*, which is exactly the context needed to read the
temperature curves ("did opening the bypass actually pull the supply temperature down?").

## What Changes

- **Decouple the timeline from Extreme Heat mode** so it is a standalone "temperature
  timeline" feature: rename the `ExtremeHeatChart` component to a neutral name
  (`TimelineChart`), and treat the chart as the home of temperature/humidity history that
  renders regardless of whether Extreme Heat is enabled. Extreme-heat level-change markers
  become one *optional overlay* on the timeline rather than the timeline's reason for being.
- **Shade the chart background by bypass state over time.** The timeline background is drawn
  in two slightly different gray tones: the normal/base gray when the bypass is **closed**
  (heat recovery), and a **slightly brighter** gray for spans where the bypass was **open**
  (free cooling). The shading aligns to the same time axis as the curves.
- Record bypass state across the 24 h history window on-device (a small ring buffer of
  bypass open/closed transitions, mirroring the existing level-change event log) and expose
  it to the web UI via the existing `/api/history` payload so the frontend can paint the
  background bands. Persist it across reboots alongside the history snapshot.

## Capabilities

### New Capabilities
- `temperature-timeline`: the standalone temperature/humidity history chart, independent of
  Extreme Heat mode — always available, with extreme-heat level changes as an optional
  overlay rather than a dependency.
- `bypass-timeline-shading`: a record of bypass open/closed state over the history window and
  its rendering as a two-tone gray chart background aligned to the time axis.

### Modified Capabilities
<!-- No firmware specs live in openspec/specs/ today; behaviour is added, not changed there.
     The existing extreme-heat-visualization spec (in the extreme-heat-mode change) keeps its
     level-change-marker requirements; this change only reframes ownership of the chart. -->

## Impact

- Web frontend (`esp32/web/src/`): rename `ExtremeHeatChart.tsx` → `TimelineChart.tsx` and
  update its import in `StatusTab.tsx`; add background-band rendering keyed on bypass state;
  add a legend entry and translations (EN/DE) for the bypass shading.
- Firmware (`esp32/src/`): a bypass-state transition log in `app_state.rs` (epoch + open
  flag, bounded ring buffer), recorded where `requested_bypass_open` is set (extreme-heat,
  scheduler, manual/MQTT paths); serialized into the `/api/history` JSON in `history.rs` /
  `webserver.rs`; included in the retained `persist/temp_history` MQTT snapshot for reboot
  recovery.
- API: `/api/history` JSON gains a `bypass` field (list of `{epoch, open}` transitions). No
  new endpoint. No config/NVS schema change.

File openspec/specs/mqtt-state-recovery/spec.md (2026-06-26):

## ADDED Requirements

### Requirement: Enthalpy history is persisted in the snapshot

The retained MQTT history snapshot SHALL include a downsampled, epoch-stamped list of the indoor
and outdoor enthalpy history, emitted alongside the existing temperature and humidity point
lists. Points SHALL be emitted only where at least one enthalpy channel has data, and the
snapshot builder SHALL reserve enough buffer capacity for the added list.

#### Scenario: Snapshot includes enthalpy

- **WHEN** the snapshot is built and enthalpy history exists
- **THEN** the snapshot contains an enthalpy point list with epoch-stamped `[min,max]`/`null`
  pairs for the indoor and outdoor channels

#### Scenario: No enthalpy data

- **WHEN** no enthalpy history exists at snapshot time
- **THEN** the enthalpy list is empty and the rest of the snapshot is unchanged

### Requirement: Enthalpy history is restored from the snapshot

Recovery SHALL re-bin the enthalpy points onto the live 5-minute grid by their epochs (as it
does for humidity), forward-fill gaps into continuous curves, and bound each section's parse so
enthalpy points are not mistaken for humidity, temperature, or bypass entries. A snapshot
produced by firmware that predates enthalpy (no enthalpy list) SHALL restore successfully with
the temperature and humidity history intact and no enthalpy data.

#### Scenario: Enthalpy round-trips through a snapshot

- **WHEN** a snapshot containing enthalpy points is restored against a valid clock
- **THEN** the indoor and outdoor enthalpy history is reconstructed on the 5-minute grid and
  forward-filled into continuous curves

#### Scenario: Backward-compatible restore

- **WHEN** a snapshot without an enthalpy list is restored
- **THEN** temperature and humidity history restore as before and no enthalpy data is added,
  with no parse error

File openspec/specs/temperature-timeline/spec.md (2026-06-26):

## ADDED Requirements

### Requirement: Enthalpy history is recorded

The system SHALL record indoor and outdoor specific enthalpy (kJ/kg) into the history at
5-minute resolution, reusing the already-computed enthalpy value from the humidity decision
inputs. Enthalpy SHALL be folded only when a fresh value is available for that side, and SHALL
share the humidity bucket cadence so its columns align with the humidity history.

#### Scenario: Enthalpy folded when fresh inputs exist

- **WHEN** at least one fresh sensor exists on a side so an enthalpy value is computed
- **THEN** that side's enthalpy is folded into the current 5-minute history bucket

#### Scenario: No fresh inputs on a side

- **WHEN** a side has no fresh sensor and no enthalpy value can be computed
- **THEN** nothing is folded for that side and its enthalpy history simply has no data for that
  bucket

#### Scenario: Buckets advance on the humidity cadence

- **WHEN** a 5-minute humidity bucket boundary is crossed
- **THEN** the indoor and outdoor enthalpy buckets advance together with the humidity buckets

### Requirement: Enthalpy is exposed to the web timeline

The `/api/history` payload SHALL include the indoor and outdoor enthalpy series alongside the
existing temperature and humidity series, using the same compact `[min,max]` / `null` bucket
encoding and the humidity slot count and bucket interval.

#### Scenario: Enthalpy present in history payload

- **WHEN** the web client fetches the history endpoint and enthalpy data exists
- **THEN** the payload contains the indoor and outdoor enthalpy arrays in `[min,max]`/`null` form

#### Scenario: Enthalpy absent

- **WHEN** no enthalpy data has been recorded yet
- **THEN** the enthalpy arrays are present but contain only `null` buckets, and the rest of the
  payload is unchanged

### Requirement: Timeline renders enthalpy curves

The timeline SHALL render the indoor and outdoor enthalpy history as curves on their own
auto-scaled value axis (kJ/kg), visually distinct from the temperature and humidity curves, with
a current-point marker at the most recent populated bucket of each enthalpy curve as with the
other series.

#### Scenario: Enthalpy curves drawn when data exists

- **WHEN** the timeline has indoor or outdoor enthalpy history
- **THEN** the enthalpy curves are drawn on their own kJ/kg axis, distinct from temperature and
  humidity, each with a current-point marker at its latest bucket

#### Scenario: No enthalpy data

- **WHEN** there is no enthalpy history
- **THEN** no enthalpy curve, axis, or marker is drawn and the rest of the timeline renders
  unchanged

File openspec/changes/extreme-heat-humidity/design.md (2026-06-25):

## Context

Extreme-heat mode (`extreme_heat.rs`) decides a ventilation level once a minute from the
supply-vs-exhaust **temperature** delta (ID 80 vs ID 82), with a 15-minute dwell and a
change-event log (`eh_events`) that the web graph renders as markers. The CWL unit has no usable
humidity sensor, but the home already has MQTT humidity sensors (zigbee2mqtt, DHT) that publish
JSON like `{"humidity":54.88,"temperature":27.01,…}`. `mqtt.rs` already runs the MQTT client,
subscribes to topics, and dispatches received messages; `history.rs` keeps RAM-only 1440-bucket
(1-min) channels now persisted via retained MQTT. We want the decision to use **energy
(enthalpy)** and **moisture**, not just temperature, and we want the resulting (more complex)
behaviour to be **clearly visualized**.

## Goals / Non-Goals

**Goals:**
- Ingest 1–n indoor + 1 outdoor humidity/temperature sensors over MQTT, with freshness.
- Judge ventilation by enthalpy when humidity is known; add a moisture-protection override.
- Gracefully fall back to today's temperature-only rule when data is missing/stale.
- Make the decision legible: combined temp/humidity chart, reason-annotated markers, a live
  "why now" explainer, and per-sensor status.

**Non-Goals:**
- No year-round standalone dehumidification mode (this lives inside extreme-heat mode for now).
- No new physical sensors on the CWL; humidity comes only from MQTT.
- No control of anything but the existing ventilation level (no separate damper logic).
- Sensor JSON field names are fixed to `humidity` / `temperature` (both example sensors use them).

## Decisions

### Psychrometrics (`psychro.rs`)
Compute from temperature `T` (°C), relative humidity `RH` (%), and ambient pressure `p_atm` (kPa):
- Saturation vapour pressure (Magnus): `p_sat = 0.61094·exp(17.625·T/(T+243.04))` kPa.
- Vapour pressure `p_v = RH/100 · p_sat`.
- **Absolute humidity** `AH = 2.1674 · p_v·1000 / (T+273.15)` g/m³ — the moisture metric for
  protection (does ventilating actually remove water?). Independent of `p_atm`.
- Humidity ratio `W = 0.622·p_v/(p_atm − p_v)`; **specific enthalpy** `h = 1.006·T + W·(2501 +
  1.86·T)` kJ/kg — the energy metric for cooling (humid air = higher `h`). `W` (and thus `h`)
  **depend on `p_atm`**, which matters at altitude: the example indoor sensor reports 960.9 hPa, not
  sea-level 1013 — ignoring it would bias the humidity ratio by ~5 %.
- `enthalpy(t, rh, p_atm)` takes pressure explicitly; `p_atm` comes from the tracked ambient
  pressure (below). Pure functions, unit-tested against known points.

### Sensor ingestion & storage
- Config gains `humidity_inside_topics: Vec<String>` and `humidity_outside_topic: String`,
  persisted to NVS as JSON (same pattern as schedules — low churn).
- `mqtt.rs` subscribes to each configured topic; on a matching `Received`, parse `humidity`
  (required) and `temperature` / `pressure` (optional) and store a `HumiditySample { humidity,
  temperature, pressure, updated_ms }` in `app_state` (a small map keyed by topic for indoor, one
  slot for outdoor).
- **Ambient pressure:** a single `ambient_pressure_kpa` is updated from any sensor that reports
  `pressure` (most recent wins; indoor and outdoor barometric pressure are locally near-identical),
  falling back to 101.3 kPa if none ever has. `enthalpy()` is always called with it.
- Topic changes take effect by re-subscribing on the next MQTT tick (idempotent subscribe to any
  newly-configured topic); no reboot required.
- **Freshness:** `SENSOR_STALE_SECS = 1800` (30 min). A sample older than that is ignored as live
  data (battery sensors report slowly; 30 min tolerates a missed cycle).

### Aggregation
- Indoor moisture/energy use the **worst-case** sensor: indoor `AH` = max over fresh indoor
  sensors, indoor `h` = the enthalpy of the sensor giving that max (conservative — drives
  protection when *any* room is humid). Each sensor's own `T`+`RH` pair is used (coherent); if a
  sensor lacks temperature, the exhaust-inlet temp (ID 82) is substituted for its `T`.
- Outdoor uses the single outdoor sensor's `T`+`RH`; its `T` may be cross-checked against the
  supply-inlet temp (ID 80) but the sensor pair is used for `AH`/`h`.

### Two independent toggles
Config gains `humidity_protection_enabled` alongside the existing `extreme_heat_enabled`; both are
NVS-persisted booleans with web toggles. **Moisture protection is independent** — it runs year-round
whenever `humidity_protection_enabled`, even with extreme-heat mode off. The enthalpy cooling logic
runs only under `extreme_heat_enabled`. Either feature evaluating uses the same per-minute tick,
15-min dwell, sensor freshness, and `eh_events` log.

### Decision precedence (humidity fresh) — evaluated each minute, 15-min dwell unchanged
1. **Moisture protection** (highest priority, gated by `humidity_protection_enabled`): if
   `RH_in_max ≥ RH_PROTECT (65%)` **and** `AH_out < AH_in − AH_MARGIN (0.5 g/m³)` → ventilate.
   Level = Party if also lower-energy (`h_out < h_in`) **or** `RH_in_max ≥ RH_PROTECT_HIGH (75%)`,
   else Normal (avoid importing a lot of hot air just to dehumidify). Reason = `Dehumidify`.
   `RH_in` is the **maximum** humidity across fresh indoor sensors (worst-case room).
2. **Energy (enthalpy) bands** (gated by `extreme_heat_enabled`) on `Δh = h_out − h_in`,
   generalizing the temperature bands: `Δh > +2 → Off`, `0 < Δh ≤ +2 → Reduced`,
   `−4 ≤ Δh < 0 → Normal`, `Δh < −4 → Party` (kJ/kg). Reason = `CoolingAssist` when this raises the
   level vs. what temperature alone would, `MuggySuppression` when high outdoor energy holds it down,
   else `CoolingAssist`.
3. **Temperature fallback** (extreme-heat only): humidity stale/missing → existing
   supply-vs-exhaust temperature bands. Reason = `TempDelta`.
Manual user changes keep their existing sticky behaviour (reason = `Manual`). Thresholds ship as
named constants (tunable later), consistent with the temperature-mode constants.

### Standalone moisture protection is a surgical override
When protection acts on its own (extreme-heat off), it must NOT take over the level the way
extreme-heat does. It only **raises** ventilation: while a protection condition holds it forces
`requested_vent_level ≥ protection level` and prevents the scheduler from lowering below it (an
upward analogue of timed-off). When the condition clears — with a small RH hysteresis (on at
`RH_PROTECT`, off below `RH_PROTECT − 5%`) plus the dwell — it releases, and the normal schedule /
manual level resumes. When both features are on, extreme-heat owns the level and protection is just
its top-priority rule (step 1 above), so there is no conflict.

### Reason model
A `Reason` enum (`TempDelta | CoolingAssist | Dehumidify | MuggySuppression | Manual`) is stored
as the current decision reason and attached to each `EhEvent` (the event log gains a `reason`
field). Exposed via `/api/status` and the history events so the UI can annotate and explain.

### History channels for humidity (RAM budget)
Humidity changes slowly, so it does **not** need 1-minute resolution. To visualize humidity over
time cheaply, add **two coarser channels** (indoor, outdoor) at ~5-min resolution. This requires
making `Channel` length-agnostic (it already uses a boxed slice; methods switch from the global
`HISTORY_SLOTS` to `self.slots.len()`), so temperature channels stay at 1440 while humidity
channels use ~288 slots.
- Cost: 2 × 288 × 12 B ≈ **7 KB** (vs ~35 KB if we matched 1-min). Current free heap ≈ 96 KB →
  comfortable. Humidity is added to the retained MQTT snapshot and `/api/history` (timestamped
  points already make this resolution-independent).

### Visualization (web)
- **Combined chart:** existing supply/exhaust temperature lines on the left axis; indoor/outdoor
  humidity lines on a **right axis** (0–100%), drawn from the coarser humidity series. Distinct
  colours + a legend naming each series and its axis.
- **Reason-annotated markers:** each change marker is coloured/iconed by reason (temp / cooling /
  dehumidify / muggy) and labelled with the level, with a hover/legend mapping.
- **Decision-explainer panel** (the key piece for legibility): shows current `T_in/T_out`,
  `RH_in/RH_out`, derived `AH_in/AH_out`, `h_in/h_out`, the active rule, and a plain-language
  sentence ("Outdoor air is drier and lower-energy → ventilating to cool and dehumidify → Party").
  In fallback it states "using temperature only (humidity stale/missing)".
- **Sensor status:** list each configured sensor with last value + fresh/stale badge.

## Risks / Trade-offs

- **Bad/again-humid outdoor air** → protection only fires when `AH_out < AH_in`, so we never import
  moisture; muggy outdoor air suppresses cooling via enthalpy. Mitigated by design.
- **Sensor offline (dead battery)** → freshness window + fallback to temperature-only; explainer
  shows the fallback so it's visible, not silent.
- **Conflicting goals (dry vs. heat)** → protection caps at Normal when outdoor is higher-energy,
  only going Party when it also cools; avoids importing lots of hot air just to dehumidify.
- **RAM** → humidity history kept coarse (~7 KB); if heap ever tightens, fall back to even fewer
  humidity slots. Temperature resolution unchanged.
- **Psychrometric accuracy** → Magnus/standard-pressure approximations are well within sensor
  accuracy; pressure used if the sensor provides it.
- **Chart clutter** → dual axis with up to 4 series; mitigated by clear colours, a legend, and
  keeping humidity series coarse/smooth.

## Migration Plan

Additive and config-gated: with no sensors configured, extreme-heat mode is byte-for-byte today's
temperature behaviour. Ships in a normal firmware + web OTA. Sensor config is entered in the web UI
afterwards; humidity logic activates once a fresh outdoor + at least one indoor reading exist.

## Resolved Decisions

- **Moisture protection is independent** of extreme-heat mode (own toggle, year-round). ✓
- **Indoor aggregation is max-humidity** (worst-case room). ✓
- **Sensor JSON field names are fixed** (`humidity` / `temperature` / `pressure`) — not configurable
  for now. ✓
- **Thresholds ship as named constants** (not web-configurable in v1). The live explainer panel
  surfaces the actual AH/enthalpy/RH values against the thresholds, so they can be observed and a
  constant re-flashed if needed. If one is later promoted to the web UI, it is the **indoor RH
  protection %** (the only human-intuitive knob).

## Open Questions

- None blocking. Future: optionally expose the indoor RH protection % in the web UI once real-world
  use indicates a need.

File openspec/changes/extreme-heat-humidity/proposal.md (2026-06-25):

## Why

Extreme-heat mode currently decides purely on the supply-vs-exhaust **temperature**
difference. But air carries energy as *enthalpy*, not just temperature: humid air holds far
more energy than dry air at the same temperature, so on a muggy day pulling in "cooler" but
wet outside air can actually add energy and make the house feel worse. Two real goals aren't
served today: (1) **don't import latent heat** — judge ventilation by total energy, not just
temperature; and (2) **protect the house from getting too humid** — ventilate to expel indoor
moisture when the outside air is genuinely drier. Both require humidity data, which the CWL
unit doesn't measure but which cheap MQTT sensors (zigbee2mqtt, DHT, etc.) already publish.

And because the decision rules are becoming complex (temperature delta, enthalpy, moisture
protection, sensor freshness), the behaviour must be **clearly visualized** so it's obvious
why the mode chose a given level at any moment.

## What Changes

- Ingest **humidity + temperature (+ optional pressure) from MQTT sensors**: 1–n **indoor**
  sensors and 1 **outdoor** sensor, configured by topic. Parse the `humidity` / `temperature` /
  `pressure` fields from each sensor's JSON payload, store the latest reading per sensor with a
  freshness timestamp. Pressure (when any sensor reports it) is used for accurate enthalpy at the
  local altitude; sensors without it still work.
- Make extreme-heat mode **humidity-aware**: when fresh humidity data is available, judge
  ventilation by **enthalpy** (total air energy) instead of bare temperature, so ventilating assists
  cooling on an energy basis.
- Add **moisture protection** as its **own independently-enableable feature** (separate toggle,
  works year-round regardless of extreme-heat mode): when indoor air is too humid *and* outdoor air
  is drier in absolute terms, turn the CWL on to dehumidify — regardless of the temperature delta —
  and release control once humidity is back in range. Indoor humidity is aggregated as the
  **maximum** across indoor sensors (worst-case room). When both features are on, protection takes
  precedence within the decision.
- Fall back to the existing **temperature-only** behaviour when humidity data is missing or stale,
  so the mode never gets worse than today.
- Add a **decision visualization** to the web UI: a combined temperature + humidity chart over
  the 24 h window, change markers annotated with the **reason** each level change happened
  (temperature / cooling-assist / dehumidify / muggy-suppression), and a live "why" panel showing
  the current inputs (temps, humidities, absolute humidity, enthalpy) and which rule is driving
  the current level. Plus per-sensor online/stale status.
- Configure all of the above from the web UI (sensor topics) and expose current values + the
  active decision reason over `/api/status`.

## Capabilities

### New Capabilities
- `humidity-sensors`: subscribe to configurable MQTT humidity/temperature sensor topics (indoor
  list + outdoor), parse and store the latest per-sensor reading with freshness, and persist the
  topic configuration.
- `humidity-aware-ventilation`: extend extreme-heat mode to decide on enthalpy + absolute humidity
  — enthalpy-based cooling, a moisture-protection override, and graceful fallback to the
  temperature-only rule when sensor data is unavailable or stale. Each decision records a reason.
- `humidity-decision-visualization`: web visualization that makes the (now multi-factor) decision
  legible — combined temperature/humidity history chart, reason-annotated change markers, a live
  decision-explainer panel, and per-sensor status.

### Modified Capabilities
<!-- extreme-heat-mode's spec is not yet archived in openspec/specs/, so the humidity behaviour
     is expressed as new capabilities layered on it rather than as a delta spec. -->

## Impact

- Firmware: `mqtt.rs` (subscribe to sensor topics, parse readings), `app_state.rs` (sensor store
  + freshness, current decision reason), `extreme_heat.rs` (humidity-aware decision + reasons),
  new `psychro.rs` (absolute humidity / enthalpy from T + RH), `config.rs` / `config_manager.rs`
  (sensor topic config, NVS-persisted), `history.rs` (humidity history channels), `webserver.rs`
  (status fields, sensor config endpoints), and `main.rs` wiring.
- Web (`esp32/web/src/`): config UI for sensor topics, the combined chart, the decision-explainer
  panel, and sensor status.
- RAM: adding humidity history channels increases the in-RAM history footprint (see design for the
  budget and mitigation).

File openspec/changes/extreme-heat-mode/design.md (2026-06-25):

## Context

The firmware controls a Wolf CWL heat-recovery ventilation unit over OpenTherm and exposes
a Preact web UI plus an OLED display. Relevant existing pieces:

- `cwl_data.rs`: `VentLevel { Off=0, Reduced=1, Normal=2, Party=3 }`; temperature fields
  `supply_inlet_temp` (ID 80) and `exhaust_inlet_temp` (ID 82), decoded as f8.8.
- `app_state.rs`: `AppStateInner` behind `Arc<Mutex<…>>`; `requested_vent_level: u8` is the
  single setpoint that `ot_master.rs` writes to the unit (ID 71). Also holds `config`,
  `temp_history`, and the timed-off / schedule-override flags.
- `scheduler.rs`: evaluates time-based rules once every 60 s and writes `requested_vent_level`.
  Uses NTP epoch seconds (`esp_idf_svc::sys::time()`), guarded by `epoch > 1_700_000_000`.
- `history.rs` (`TempHistory`): 128 rolling buckets (~11.25 min each ≈ 24 h), channels
  `outdoor` (= supply inlet), `indoor` (= exhaust inlet), `delta`. Sampled ~1 Hz from main loop.
- `webserver.rs`: HTTP server with `/api/status` (JSON) and config/schedule endpoints. There is
  **no** history endpoint today; history is only drawn on the OLED.
- Web frontend (`esp32/web/src/`): Preact + TypeScript, built by Vite into `esp32/data/`,
  served from SPIFFS. No charting library is currently used; `/api/status` is polled every 5 s.

The feature adds an automatic control mode on top of this and surfaces it in the web UI.

## Goals / Non-Goals

**Goals:**
- Automatically pick the ventilation level from `delta = supply_inlet − exhaust_inlet` using the
  thresholds in the spec, with a 15-minute minimum dwell between mode-driven changes.
- Make the mode opt-in and persistent, and keep it fully inert when disabled.
- Visualize supply vs exhaust temperatures in the web UI with markers at each mode-driven change.

**Non-Goals:**
- No new humidity/CO₂/forecast inputs — decisions use only the two inlet temperatures.
- No change to how levels are physically written to the unit (`ot_master.rs` / ID 71 unchanged).
- No hysteresis band beyond the explicit thresholds; toggling is controlled by the dwell timer.
- No persistence of the temperature history or event log across reboots (in-RAM, like today's history).

## Decisions

### Where the control loop lives
New module `extreme_heat.rs` exposing a small state machine, evaluated from the main loop (or
the scheduler tick) once per minute — the same cadence as `scheduler.rs`, which is far finer
than a 15-minute dwell. Rationale: keeps the policy isolated and unit-testable, mirrors the
existing `scheduler.rs` pattern, and avoids bloating `ot_master.rs` (which owns transport).
Alternative considered: folding the logic into `scheduler.rs` — rejected to keep the
temperature policy separate from the time-of-day policy.

### Level mapping (banding)
Compute `delta = supply − exhaust` and map to a `VentLevel`:
`delta > 0.5 → Off`, `0 < delta ≤ 0.5 → Reduced`, `−1.0 ≤ delta < 0 → Normal`, `delta < −1.0 → Party`.
The boundary at `delta = 0` resolves to Normal (supply not strictly greater than exhaust).
Keeping the thresholds as named constants makes future tuning trivial.

### Dwell timer
Store `last_change_epoch: i64` and `current_level: u8` in app state. A new selection is applied
only when `now_epoch − last_change_epoch ≥ 900` **and** the selected level differs from the
current one; applying a change resets `last_change_epoch`. Use NTP epoch seconds (same source and
`> 1_700_000_000` validity guard as `scheduler.rs`) so the timer is robust across the ~49-day
millisecond counter wrap. If epoch is not yet valid, make no change.

### Precedence with manual / timed-off
- Timed-off wins: while `timed_off_active`, the mode does not raise the level.
- Manual change: when the user sets a level (UI/encoder/MQTT) while the mode is enabled, treat it
  as the current decision — adopt that level as `current_level` and reset `last_change_epoch`, so
  the mode waits a full 15 minutes before overriding. This makes manual nudges sticky and avoids
  a fight. Alternative considered: manual change disables the mode — rejected as surprising.
- Extreme Heat mode and time-of-day schedules are mutually exclusive in effect: while the mode is
  enabled it owns `requested_vent_level`; schedule evaluation is suppressed for this period.

### Config
Add `extreme_heat_enabled: bool` to `AppConfig` (NVS-persisted alongside existing settings).
Thresholds and the 15-minute dwell ship as constants (not user-configurable in v1) to keep the
UI simple; they are easy to promote to config later.

### Visualization data path
- New endpoint `GET /api/history` returns the `TempHistory` supply and exhaust channels as JSON:
  per-bucket `{min,max}` arrays ordered oldest→newest, plus `bucketMs` and `newestBucketEpoch`
  (or an age offset) so the frontend can place buckets on a time axis.
- New endpoint `GET /api/heat-events` (or an `events` array folded into `/api/history`) returns a
  bounded ring buffer of `{ epoch, level }` records appended whenever the mode changes the level.
  Capacity sized to cover the ~24 h window (e.g. 32–64 events); oldest dropped when full.
- Reuse the existing `temp_history` sampling — no new sampling path. The event ring buffer lives in
  `app_state.rs` and is appended from `extreme_heat.rs` at the moment a change is applied.

### Web rendering
A new Preact component renders an inline **SVG** line chart (supply and exhaust series, distinct
colours via the existing CSS accent variables, labelled temperature axis), with vertical marker
lines/dots at each event time annotated with the selected level name. SVG over canvas: crisp on
HiDPI, trivially styleable with existing CSS vars, no extra dependency, and the dataset is small
(≤128 buckets). The component fetches `/api/history` (+ events) on the existing poll cadence and
re-renders on new data. A toggle for the mode is added to the status UI and posts to `/api/config`.

## Risks / Trade-offs

- **Sensor noise near a threshold** → the 15-minute dwell already damps this; thresholds are
  named constants so they can be widened if real-world data shows flapping at boundaries.
- **NTP not yet synced after boot** → epoch invalid; the mode makes no change until time is valid
  (same guard the scheduler already relies on). Acceptable: the unit holds its current level.
- **Manual-change precedence may surprise users** ("I set Party but 15 min later it dropped") →
  documented behaviour; the dwell makes it predictable, and disabling the mode restores full manual
  control.
- **History/events are RAM-only** → lost on reboot, so the graph starts empty after a restart. Matches
  today's OLED history behaviour; persisting is out of scope for v1.
- **Bundle size** → SVG chart is hand-rolled (no charting lib) to keep `app.js` small.

## Open Questions

- Should the schedule still be allowed to *lower* the level (e.g. night quiet) while Extreme Heat
  mode is enabled, or is the mode strictly exclusive? (Design assumes exclusive while enabled.)
- Are the thresholds (0.5 °C / 1.0 °C) and the 15-minute dwell final, or should they be exposed as
  config tunables in this change rather than a follow-up?
- Should change events also be emitted to MQTT for external logging/automation?

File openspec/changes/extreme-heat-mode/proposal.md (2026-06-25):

## Why

During extreme heat the heat-recovery ventilation can make a home *hotter*: when the
incoming fresh (supply) air is warmer than the indoor (exhaust) air, running the fans
pumps heat into the house. Today the user has to manually drop the level on hot
afternoons and raise it again when the outside air cools below the inside, which is
tedious and easy to forget. An automatic "extreme heat" mode that follows the
supply-vs-exhaust temperature difference removes this manual babysitting and keeps the
house as cool as the ventilation physically allows.

## What Changes

- Add an opt-in **Extreme Heat mode** that automatically chooses the ventilation level
  from the difference between supply inlet air (OpenTherm ID 80) and exhaust inlet air
  (OpenTherm ID 82):
  - supply > exhaust + 0.5 °C → **Off**
  - supply > exhaust          → **Reduced** (low)
  - supply < exhaust          → **Normal**
  - supply < exhaust − 1.0 °C → **Party**
- A chosen level is held for a **minimum dwell of 15 minutes** before a new decision can
  change it, so readings near a threshold do not cause rapid toggling.
- The mode is enabled/disabled from the web UI (and persisted in config). While enabled
  it drives `requested_vent_level`; while disabled behaviour is unchanged. It coexists
  with timed-off and manual override per the rules in design.
- **Visualize the mode in the web UI**: a graph showing supply and exhaust air
  temperatures over the rolling history window, with **markers at the points where the
  mode changed the ventilation level** (annotated with the new level).
- Expose the temperature history (already sampled for the OLED) over a new HTTP endpoint
  so the web graph can render it, plus a short log of extreme-heat level-change events.

## Capabilities

### New Capabilities
- `extreme-heat-mode`: automatic ventilation-level control driven by the supply-vs-exhaust
  air temperature difference, including the 15-minute decision dwell, enable/disable +
  persistence, and interaction with manual override / timed-off.
- `extreme-heat-visualization`: web-UI graph of supply and exhaust temperatures with
  change markers, plus the HTTP endpoint(s) that expose temperature history and
  level-change events to the frontend.

### Modified Capabilities
<!-- No existing OpenSpec specs in openspec/specs/; behaviour is added, not changed. -->

## Impact

- Firmware (`esp32/src/`): new control logic (new module, e.g. `extreme_heat.rs`),
  additional fields in `app_state.rs` (enable flag, last decision + timestamp, change-event
  ring buffer), wiring in `main.rs`, and new routes in `webserver.rs`.
- Config (`AppConfig`, NVS-persisted): new `extreme_heat_enabled` setting and any tunables.
- Web frontend (`esp32/web/src/`): new graph component (Preact, client-side rendered),
  API client additions in `api.ts`, and a status/section to toggle the mode.
- `/api/status` JSON gains extreme-heat state; new history/events endpoint(s) added.

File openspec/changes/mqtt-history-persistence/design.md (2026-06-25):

## Context

Two datasets live only in RAM and reset on every reboot/OTA:

- **Temperature history** (`history.rs` `TempHistory`): 3 channels (`outdoor`=supply inlet,
  `indoor`=exhaust inlet, `delta`), each 128 buckets of `{min,max}`, rolling ~11.25 min/bucket.
- **Extreme-heat activation** (`app_state.rs`): `config.extreme_heat_enabled`, `eh_current_level`,
  `eh_last_change_epoch`, and `eh_events: VecDeque<EhEvent{epoch,level}>` (the graph markers).

`mqtt.rs` already runs on its own thread, publishes most state as **retained** (`pub_retained`,
QoS AtMostOnce, retain=true), subscribes to `{base}/set/*` command topics, and dispatches
received messages through `handle_event` → `handle_command`. The broker's retained store is a
durable, flash-free place to keep the RAM-only data and read it back on boot.

NVS already persists the low-churn bits (`extreme_heat_enabled`, timed-off, schedule override,
level, bypass); those are out of scope here — we only need MQTT for the high-churn RAM-only data.

## Goals / Non-Goals

**Goals:**
- Publish temperature history and extreme-heat activation as retained MQTT messages.
- On boot (MQTT enabled), restore both into RAM from the retained snapshots.
- Zero new flash/NVS writes; unchanged behaviour when MQTT is disabled.

**Non-Goals:**
- No change to what is sampled or how the graph renders.
- No MQTT authority over the `extreme_heat_enabled` flag — NVS stays authoritative for it.
- No attempt to back-fill the exact wall-clock gap between the last publish and reboot; recovered
  buckets are restored in order with "newest = now" (an approximation, same as the live model).
- No persistence of timed-off / schedule state via MQTT (already NVS-backed, low churn).

## Decisions

### Topics and payloads
Two dedicated retained topics under a `persist/` prefix so they're clearly separate from the
live/observability topics and the command topics:

- `{base}/persist/temp_history` — JSON: `{ "bucketMs", "nowEpoch", "supply":[[min,max]|null,…128],
  "exhaust":[…], "delta":[…] }`, oldest→newest. This mirrors the existing `/api/history` shape, so
  the serializer can be shared.
- `{base}/persist/extreme_heat` — JSON: `{ "enabled", "currentLevel", "lastChangeEpoch",
  "events":[{"epoch","level"},…] }`.

Both published with retain=true. Payloads are a few KB; well within MQTT limits.

### Publish cadence
- History: publish on **bucket rollover** (the moment `TempHistory::sample` returns `true`, ~every
  11 min). The snapshot includes the in-progress head bucket, so at most the current partial bucket
  is at risk between a rollover and a reboot — acceptable. Also publish once shortly after a
  successful recovery/first connect so a fresh broker gets an initial snapshot.
- Extreme-heat: publish whenever the mode applies a level change (a new `EhEvent`) or the enabled
  flag changes. These are rare, so cost is negligible.

This is event-driven off existing signals; no new timers churning the broker.

### Recovery path — defer parsing to the main loop
The MQTT receive callback runs on EspMqttClient's event thread with a limited stack; parsing a
multi-KB JSON there is risky. So the callback does **no parsing**: on a message to a `persist/`
topic it copies the raw bytes into a new `app_state` buffer and returns. The main loop drains the
buffer, parses with `serde_json`, and applies:

- `pending_history_json: Option<Vec<u8>>` → parsed into `TempHistory` via a new
  `TempHistory::restore_from_snapshot(...)` that rebuilds each `Channel`'s `slots`/`head`
  (oldest→newest, head at newest).
- `pending_extreme_heat_json: Option<Vec<u8>>` → restores `eh_events`, `eh_current_level`,
  `eh_last_change_epoch` (NOT `enabled` — see below).

### One-shot recovery / no feedback loop
The device subscribes to both `persist/` topics at `setup_subscriptions`. Because it also publishes
to them, the broker echoes its own messages back. Guard with per-topic flags
(`history_recovered`, `extreme_heat_recovered`): the **first** retained payload received per topic
after boot is queued for apply; once applied, later messages on that topic are dropped in the
callback. This prevents re-applying echoes and prevents a stale snapshot from clobbering fresher
live RAM data. If no retained message exists, the flag simply never trips and the data builds from
live samples — no error.

### Source of truth for the enabled flag
`extreme_heat_enabled` is recovered from **NVS** as today. The retained snapshot carries `enabled`
for observability only; recovery restores just the RAM-only decision history and dwell state. This
avoids an NVS-vs-MQTT conflict and keeps a single authority for the toggle.

### Restore vs. live-sample ordering
Recovery is applied in the main loop as soon as the pending buffer appears (typically within a
second or two of MQTT connecting). The history sampler tolerates being pre-populated: restored
buckets sit in the channel and the next `sample()` continues into the head bucket. If a live sample
lands before recovery, the one-shot guard still lets the snapshot restore the older buckets; the
newest (head) may merge — acceptable, no corruption.

## Risks / Trade-offs

- **Echo storm / re-apply** → mitigated by the one-shot per-topic recovery flags.
- **Callback-thread stack exhaustion parsing JSON** → mitigated by deferring parse to the main loop.
- **Snapshot/now misalignment after a long downtime** → recovered buckets are placed newest=now, so
  a long outage shows the old curve shifted to "now". Acceptable for a 24 h trend view; documented.
- **Broker without retained support / wiped retained store** → recovery silently no-ops; history
  rebuilds from live samples (same as today).
- **Partial head bucket lost on reboot** → at most ~11 min of the in-progress bucket; acceptable.
- **MQTT payload size** → full history JSON is a few KB; fine, but keep it compact (arrays of
  `[min,max]`, `null` for empty) rather than verbose objects.

## Migration Plan

Additive: new topics and code paths only. No NVS/partition changes, no breaking changes. Rolls out
with a normal firmware OTA. On first boot after the update the broker has no `persist/` retained
messages yet, so the device starts as before and begins publishing; subsequent reboots recover.

## Open Questions

- Should history also be published on a slow periodic timer (e.g. every few minutes) to capture the
  in-progress bucket, or is rollover-only sufficient? (Design assumes rollover-only.)
- Should the `persist/` topics be cleared (empty retained publish) on factory reset so a reused
  broker doesn't restore stale data onto a fresh device?
- Is a single combined `persist/state` topic preferable to two topics, to make recovery atomic?

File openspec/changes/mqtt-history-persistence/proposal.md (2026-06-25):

## Why

The 24 h temperature history and the extreme-heat mode's decision timeline live only in
RAM, so every reboot or OTA wipes them — the graph comes back blank for ~11 minutes and the
change markers are lost. Writing this churning data to flash would wear the NVS partition,
which we explicitly want to avoid. When MQTT is enabled we already have a durable store: the
broker holds **retained** messages. By publishing this state retained and reading it back on
boot, the device can recover everything into RAM with zero extra flash writes.

## What Changes

- When MQTT is enabled, publish the **temperature history** (supply / exhaust / delta buckets)
  as a **retained** message, refreshed whenever a bucket rolls over.
- When MQTT is enabled, publish the **extreme-heat mode activation state** — enabled flag,
  current decided level, dwell timestamp, and the level-change event log (the graph markers) —
  as a **retained** message, refreshed whenever the mode changes the level or its enabled state.
- On boot (MQTT enabled), **subscribe to these retained topics and restore the data into RAM**
  before/while normal sampling resumes, so the graph and markers survive reboots.
- Recovery is **one-shot per topic**: the device applies the first retained snapshot it receives
  after boot and ignores its own later echoes, so there is no feedback loop and live data is
  never clobbered by a stale snapshot.
- **No new flash/NVS writes** are introduced for this data — persistence is MQTT-only. When MQTT
  is disabled the behaviour is unchanged (history/markers remain RAM-only and reset on reboot).

## Capabilities

### New Capabilities
- `mqtt-state-recovery`: publishing the RAM-only temperature history and extreme-heat
  mode-activation state as retained MQTT messages, and recovering them into RAM on boot,
  without writing to flash.

### Modified Capabilities
<!-- The extreme-heat history/markers gain MQTT-backed durability, but their existing
     spec-level behaviour (what is sampled, how the graph renders) does not change, so no
     delta spec is required. -->

## Impact

- Firmware `mqtt.rs`: new retained publishes (history snapshot, extreme-heat snapshot), new
  subscriptions to the persist topics, and receive-side handling that hands raw payloads to the
  main loop for parsing.
- `app_state.rs`: small "pending recovery" buffers + recovery-done flags so the MQTT callback
  thread does no heavy parsing.
- `history.rs`: a serialize/restore path for the bucket channels.
- `main.rs`: apply pending recovery buffers into `temp_history` / extreme-heat state once at boot.
- No changes to `config_manager.rs` / NVS; no new flash writes.

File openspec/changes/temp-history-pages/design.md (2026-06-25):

## Context

`AppStateInner.cwl_data` already holds live temperatures, refreshed once per second by `OtMaster` on its own thread (see `src/ot_master.rs`). The OLED renderer in `src/display.rs` is dirty-flag driven: any thread that mutates display-visible state flips `DisplayDirty`, and `Display::update()` re-renders only when the flag is set. The render path runs `match page { … }` against a `Page` enum and an indexed dots strip.

There is no existing time-series store anywhere in the firmware — MQTT publishing is fire-and-forget. NVS is reserved for config + schedules; using it for sensor history would burn the flash for no panel benefit.

The display is 128×64 px, 1 bpp, with a fixed ~12 px header and a 5-px-tall dots row at y=59, leaving roughly y=14..56 (~42 px) for content per page.

## Goals / Non-Goals

**Goals:**
- Show the last 24 h of three temperature signals (outdoor / indoor / delta) on three new pages.
- Surface the 24 h min and max for each signal.
- Render a chart that fits the existing page layout without scrolling or controls.
- Zero flash wear: history is in RAM and reset on reboot.

**Non-Goals:**
- Persisting history across reboots (NVS wear, NTP/timezone complications — not worth it for a glance feature).
- Scrolling / zooming the chart, or selecting time ranges.
- Publishing the history over MQTT / HTTP (subscribers can already build this externally).
- Backfilling history from MQTT or anywhere else after reboot.
- Changing the live `TempIn` (Intake) page — it stays as-is.

## Data Model

```rust
// src/history.rs
pub const HISTORY_SLOTS: usize = 128;            // chart-width-aligned
pub const BUCKET_MS: u32      = 24 * 60 * 60 * 1000 / HISTORY_SLOTS as u32; // 675_000 ms (~11.25 min)
pub const SAMPLE_INTERVAL_MS: u32 = 1_000;       // main-loop folds once per second

#[derive(Debug, Clone, Copy)]
pub struct Bucket {
    pub min: f32,
    pub max: f32,
}

#[derive(Debug)]
pub struct Channel {
    pub slots: [Option<Bucket>; HISTORY_SLOTS], // None until first sample lands
    pub head: usize,                            // next slot to write
}

#[derive(Debug)]
pub struct TempHistory {
    pub outdoor: Channel,
    pub indoor:  Channel,
    pub delta:   Channel,                       // None whenever supports_id81 = false
    bucket_start_ms: u32,                       // when slot `head` started
    last_sample_ms:  u32,
}
```

`Channel::slots` is a fixed array (not a `Vec`) so the structure has a known footprint: 128 × 2 × 4 B per channel = 1 KB; three channels = 3 KB; plus `Option` discriminants ≈ 3.5 KB total. This fits the existing firmware budget comfortably.

`head` is the index of the *current* slot being aggregated. After `BUCKET_MS` of wall-clock time it advances (modulo `HISTORY_SLOTS`) and the new slot starts as `None`. The chart treats `None` as "no data drawn", which gives the cold-start ramp and rolling-window discard for free.

## Decisions

### 1. RAM-only, no NVS persistence

**Choice:** History lives in `AppStateInner` and dies with the process.

**Rationale:** The user signed off on this in the proposal questions. The flash wear of writing 3 channels × 128 slots multiple times per hour is unjustified for a feature that is "look at the panel". A fresh boot showing an empty chart that fills in over the next 24 h is acceptable.

### 2. Bucketing happens on the main loop, not on the OT thread

**Choice:** `state.temp_history.sample(now_ms, &state.cwl_data)` is called once per main-loop iteration from `src/main.rs`, throttled to once per second.

**Rationale:** Keeps `ot_master.rs` focused on protocol. The main loop already locks `state` for the encoder / network / persist checks, so adding one more borrow there is free. Sampling at 1 Hz oversamples relative to the OT polling rate (also ~1 Hz) — duplicates inside a bucket are folded into min/max, so there is no bias.

**Alternative considered:** Sample from the OT thread right after temperatures update. Rejected — would couple the new module to the OT path and require a separate dirty flag to wake the display.

### 3. Bucket aggregation: min/max only, no average

**Choice:** Each `Bucket` stores `(min, max)` over its window. No mean / count / sum.

**Rationale:** The chart draws a vertical bar per column from `min` to `max`, which doubles as the visual mean for narrow ranges. Adding mean would inflate per-bucket size by 50% and the renderer has no use for it (a single-pixel "mean line" on top of the bar is illegible on 1-bpp). Page-level "24 h min" and "24 h max" are scans over `slots[*].min` and `slots[*].max` respectively — O(128) on each redraw, negligible.

### 4. Delta channel definition: `supply_outlet − supply_inlet`

**Choice:** "Heat-recovery gain" = `cwl_data.supply_outlet_temp - cwl_data.supply_inlet_temp`, sampled only when `cwl_data.supports_id81` is true.

**Rationale:** This is the temperature the heat exchanger adds to the incoming fresh air — the most useful single number for "is the HRV doing its job". Indoor / outdoor delta would be informative but is dominated by the home's thermostat behaviour, not the unit's. While ID 81 is unsupported the page shows the empty-history hint, falling back gracefully on Wolf controllers that don't expose the outlet sensor.

**Alternative considered:** `exhaust_inlet − supply_inlet` (room-vs-outside Δ). Cleaner data (always available) but it's a property of the building, not the ventilation system. The proposal mentions "temperature gain", which the user phrased in heat-recovery terms.

### 5. Page placement

**Choice:** Insert the three new pages after `Page::TempIn` and before `Page::Status`. New `Page` enum:

```
Home, Bypass, TempIn, OutdoorHistory, IndoorHistory, DeltaHistory, Status, System, Settings
```

`PAGE_COUNT = 9`. The dots indicator already renders `PAGE_COUNT` dots evenly spaced — increasing the constant is the only change needed there. With 9 dots at 7 px pitch the row spans 56 px and remains centred (`(128 - 8·7)/2 = 36`).

**Rationale:** Group temperature-related pages together; the existing live `Intake` page acts as a natural "0 h" prelude to the history views.

### 6. Chart rendering

**Choice:** One vertical line per slot. Layout:

```
y=0..11   Header band (page title, drawn by draw_header)
y=12..23  Min / Max numeric strip ("Min 14.2 C   Max 21.7 C")
y=24..56  Chart area (33 px tall)
y=59..63  Dots indicator (existing)
```

For each slot `i` (0..127) that holds `Some(Bucket{min, max})`:
- Compute `y_top    = scale_y(max)` and `y_bottom = scale_y(min)`.
- Draw `Line::new(Point::new(i, y_top), Point::new(i, y_bottom))` with `BinaryColor::On`.
- If `min == max` (single sample bucket) draw a single pixel at `(i, y_top)`.

`scale_y` maps the channel-wide [min, max] into `y=24..56` inclusive, with a guard: if the range is < 0.5 °C wide, expand to ±0.25 °C around the midpoint to avoid a flat-line column collapsing to one row.

The newest slot (head − 1) renders at column 127 (rightmost) and older slots step left, wrapping at column 0 to (head modulo 128). I.e. the chart reads left-to-right as "24 h ago → now".

**Empty-state:** If every slot is `None` (just booted), draw the i18n `history_empty` string centred in the chart area instead of an empty box. The numeric Min / Max strip then renders `--` placeholders.

### 7. Dev-mode preload (added during implementation)

**Choice:** Under `feature = "simulate-ot"`, `TempHistory::new()` pre-fills all 128 slots of each channel with a synthetic 24 h summer-day cycle so the chart pages have something interesting on boot in dev mode.

**Pattern:**
- Outdoor: `20 + 8·cos(2π·(hour − 14)/24)` — peaks 28 °C at 14:00, dips to 12 °C at 02:00.
- Indoor: `22 + 0.5·sin(2π·(hour − 14)/24 + π/4)` — mild evening peak around 22.5 °C.
- Delta: `(indoor − outdoor) · 0.85` — models heat-exchanger gain (high at night when outdoor is cold, mildly negative mid-afternoon).
- Each slot is stored with `min = value − 0.3` and `max = value + 0.3` so the chart shows a visible band rather than a single pixel line.

Anchored at "now" = 14:00 so column 127 sits at the temperature peak; the chart reads left-to-right as "yesterday peak → night → today peak". The first real simulated sample (from `ot_master::simulate`) lands on the head slot and folds into the existing min/max, broadening it slightly — acceptable.

**Rationale:** Without this, the dev-mode chart shows `Collecting...` for the first 11 minutes of every boot — useless for visually iterating on the page layout. Compiled out entirely in release builds.

### 8. Dirty-flag integration

**Choice:** `TempHistory::sample()` returns a `bool` indicating "slot rolled" — i.e. the bucket index just advanced. Main loop ORs that into `display_dirty`.

**Rationale:** The chart only visibly changes when a slot rolls (~once every 11 min) or when the user navigates to a history page. Marking dirty every second would defeat the existing render-throttling. The min/max numeric strip lags by up to one bucket boundary, which is acceptable for a 24 h view.

When the user navigates to a history page, `next_page()` / `prev_page()` already calls `mark_dirty()`, so the first render after navigation happens immediately.

## Risks / Trade-offs

- **Cold-start blank chart:** For the first ~11 min after boot the chart shows only one column (current bucket). The empty-state hint covers the pre-first-sample window; partial fills are simply sparse. Acceptable — the alternative (synthesising fake history) is misleading.
- **No NTP dependency in bucketing:** `bucket_start_ms` uses `esp_timer_get_time()` (monotonic). That means buckets don't line up with wall-clock hours — "the last bucket is the most-recent ~11 min", not "10:00–10:11". The chart is a relative-time view; no time axis labels are drawn. Acceptable.
- **Delta page on unsupported hardware:** Wolf controllers that don't expose ID 81 leave the delta channel permanently empty. The page renders the empty-history hint, the same as during cold start. Documented in the proposal.
- **Memory:** ~3.5 KB on the heap (inside `AppStateInner`). Current main-loop stack already accommodates several KB of `AppStateInner`; adding 3.5 KB stays well under the ESP32 default task stack of 16 KB.
- **Float storage on a no-FPU temp range:** Temperatures are already `f32` in `cwl_data`. Storing as `f32` here keeps types consistent; an i16 fixed-point (0.1 °C resolution) would halve memory but adds conversion noise at every draw. Not worth optimising until profiling shows it.

## Open Questions

_None._ Sensor selection, persistence model, and sample resolution were confirmed during proposal Q&A.

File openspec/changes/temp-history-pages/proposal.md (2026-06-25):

## Why

The OLED display currently shows only instantaneous temperatures (the `Intake` page reports the live supply- and exhaust-inlet readings). There is no way to see how outdoor / indoor air or heat-recovery gain has trended over time — a typical question after a cold night ("did the bypass open too early?", "how cold did it get?") cannot be answered from the panel. MQTT subscribers can graph this externally, but the device itself goes blind the moment you walk up to it.

A small in-RAM ring buffer is enough to give a 24 h glance directly on the panel without any flash wear, NTP dependency, or schema migration.

## What Changes

- New in-memory temperature history module (`src/history.rs`) — three ring buffers, 128 buckets of ~11.25 min each (24 h total), for outdoor / indoor / delta. Each bucket stores aggregated min and max. RAM-only; reset on reboot.
- Sampler integrated into the main loop: once per second the latest `cwl_data` temperatures are folded into the current bucket; when the bucket window elapses, head advances.
- Three new display pages:
  - `OutdoorHistory` — `supply_inlet_temp` 24 h trend.
  - `IndoorHistory` — `exhaust_inlet_temp` 24 h trend.
  - `DeltaHistory` — `supply_outlet_temp − supply_inlet_temp` (heat-recovery gain) 24 h trend; falls back to a "—" placeholder until ID 81 is observed as supported.
- Each page shows the header (page title + units), the 24 h min and max in the top band, and a 128-px-wide auto-scaled chart showing the per-bucket [min, max] range as a vertical bar per column.
- `PAGE_COUNT` grows from 6 to 9. New pages sit after `TempIn` and before `Status` so they are grouped with the live temperature view.
- i18n strings added in `i18n.rs` (EN + DE) for the three new headers, "Min", "Max", and the empty-history hint.

## Capabilities

### New Capabilities

- 24 h on-device temperature history with min/max + chart for outdoor air, indoor air, and heat-recovery gain.

### Modified Capabilities

- Display page navigation now cycles through 9 pages instead of 6.

## Impact

- **`src/history.rs`** (new): ring buffer, bucket aggregation, sampler API.
- **`src/cwl_data.rs`**: no changes (history is a separate concern; it reads from `CwlData` via the sampler).
- **`src/app_state.rs`**: add `temp_history: history::TempHistory` field; constructor wires it up.
- **`src/main.rs`**: declare `mod history;` and call `state.temp_history.sample(...)` once per second in the main loop; mark display dirty when a new bucket boundary is crossed so the chart redraws.
- **`src/display.rs`**: extend `Page` enum with `OutdoorHistory`, `IndoorHistory`, `DeltaHistory`; raise `PAGE_COUNT` to 9; add `draw_outdoor_history`, `draw_indoor_history`, `draw_delta_history` and a shared `draw_temp_chart` helper; route in `render_content`.
- **`src/i18n.rs`**: new fields `outdoor_24h`, `indoor_24h`, `delta_24h`, `min_label`, `max_label`, `history_empty` on `Strings`, populated for `EN` and `DE`.
- **No flash, NVS, MQTT, or web-API changes.**

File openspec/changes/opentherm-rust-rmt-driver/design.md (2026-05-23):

## Context

Current driver call chain:
```
ot_master.rs
  → opentherm_ffi.rs  (Rust safe wrapper)
    → opentherm_ffi.cpp  (C linkage glue)
      → OpenTherm.cpp  (protocol + noInterrupts() TX)
        → Arduino.h shim  (ESP-IDF ↔ Arduino ABI)
```

`OpenTherm.cpp::sendRequestAync()` calls `noInterrupts()` before the first bit and `interrupts()` after the last bit — a critical section that spans the full 34-bit frame (~34 ms). The WiFi driver depends on level-2 hardware interrupts during this window; losing them for 34 ms causes TCP retransmits that manifest as lag during OTA upload.

The new module collapses this to a single Rust file with no C dependency:
```
ot_master.rs
  → opentherm.rs  (RMT driver, pure Rust)
    → esp-idf-sys / esp-idf-hal  (already a dependency)
```

## Goals / Non-Goals

**Goals:**
- Eliminate the 34 ms interrupt-disable window during TX.
- Keep `ot_master.rs` API-compatible (same types, same method signatures).
- Remove all C++ build machinery.
- Retain `simulate-ot` for local development.

**Non-Goals:**
- Slave mode (the device is always master).
- Changing any polling logic in `ot_master.rs`.
- Supporting ESP32-S2/S3/C3 — the existing firmware targets ESP32 only.

## OpenTherm Protocol Recap

**Frame format** (34 bits, MSB first):
```
[31] parity (odd over bits 30-0)
[30:28] message type (3 bits)
[27:24] spare (4 bits, always 0)
[23:16] data ID (8 bits)
[15:0]  data value (16 bits)
```

**Bit encoding** (Manchester-like, 1 ms per bit, 500 µs per half-bit):
```
bit 1: wire LOW 500 µs → HIGH 500 µs
bit 0: wire HIGH 500 µs → LOW 500 µs
idle:  wire HIGH
```

**Frame structure:** start bit (always 1) + 32 data bits MSB-first + stop bit (always 1).  
**Round-trip timing:** TX ~34 ms, slave response within ~20–100 ms, master timeout 1 s.

## RMT Peripheral Overview

The ESP32 RMT (Remote Control) peripheral encodes/decodes arbitrary pulse sequences using a dedicated hardware FIFO. It runs from the APB clock (80 MHz), programmable divider → arbitrary tick duration. TX sends a pre-loaded buffer of `(duration, level)` pairs; RX captures edges with hardware-timestamped `(duration, level)` pairs. Neither TX nor RX requires interrupt disabling.

**Clock configuration:**  
`RMT_CLK_SRC_APB` (80 MHz) ÷ 80 = 1 µs/tick. Duration values are therefore directly in µs.

**RMT symbol** (`rmt_symbol_word_t`): two half-symbols packed into one u32:
```
[31:16] second half: duration1 (15 bits) + level1 (1 bit)
[15:0]  first half:  duration0 (15 bits) + level0 (1 bit)
```

## Decisions

### 1. Use `esp-idf-sys` raw bindings for RMT, not `esp-idf-hal`

**Choice:** Call `rmt_new_tx_channel`, `rmt_new_rx_channel`, `rmt_transmit`, `rmt_receive` etc. via `esp_idf_sys::*` bindings directly.

**Rationale:** `esp-idf-hal`'s RMT wrapper is still evolving and its safe API surface changes between minor versions. The raw C API is stable, well-documented, and already available through `esp-idf-sys` which is pulled in by `esp-idf-svc`. Using it keeps the dependency footprint unchanged and makes the implementation straightforward to follow against the ESP-IDF docs.

### 2. Blocking `send_request` using a FreeRTOS event group (or semaphore)

**Choice:** `send_request` is synchronous (matches current behaviour). Internally:
1. Load TX buffer and call `rmt_transmit()` (non-blocking in RMT driver, completes via DMA).
2. Call `rmt_receive()` to arm RX capture with 1100 ms timeout.
3. Block on `rmt_rx_done_callback` via a FreeRTOS semaphore/event group.
4. Decode captured symbols in place.

**Rationale:** `ot_master.rs` already runs on its own thread; blocking there is fine and keeps the interface identical to the current C++ driver. A FreeRTOS semaphore gives the thread back to the scheduler while waiting instead of busy-spinning.

**Alternative considered:** Non-blocking with a completion callback. Rejected — would require `ot_master.rs` restructuring.

### 3. RMT TX encoding

Each bit is encoded as one `rmt_symbol_word_t`:
```
bit 1: { duration0: 500, level0: 0, duration1: 500, level1: 1 }  // LOW 500µs → HIGH 500µs
bit 0: { duration0: 500, level0: 1, duration1: 500, level1: 0 }  // HIGH 500µs → LOW 500µs
```
Frame = 34 symbols (start + 32 data + stop), followed by the RMT end-of-transmission marker `{ 0, 0, 0, 0 }`.

TX idle level configured to HIGH (passive bus state).

### 4. RMT RX decoding via half-bit expansion

**Choice:** Expand captured RMT symbols into a flat half-bit list, then decode pairs.

**Algorithm:**
1. For each captured symbol `(d0, l0, d1, l1)` (filtering zero-duration end markers):
   - Push `l0` once if `d0 ≤ 750 µs`, twice if `d0 > 750 µs`.
   - Push `l1` once if `d1 ≤ 750 µs`, twice if `d1 > 750 µs`.
2. Require exactly 68 half-bits (34 bits × 2).
3. Decode pairs:
   - `(LOW, HIGH)` → bit 1
   - `(HIGH, LOW)` → bit 0
   - any other pair → `ResponseStatus::Invalid`
4. Skip pair 0 (start) and pair 33 (stop). Reconstruct 32-bit frame from pairs 1–32.
5. Verify odd parity over all 32 bits. Fail → `ResponseStatus::Invalid`.

**Why this works:** When two consecutive same-level half-bits merge into a ~1000 µs pulse, expanding it as two copies of the same level naturally feeds one into the tail of the current bit-pair and one into the head of the next, without needing explicit boundary tracking. The correctness proof holds for all 34 valid OpenTherm bit combinations.

### 5. RMT RX filter and minimum pulse width

Configure `rmt_receive_config_t`:
- `signal_range_min_ns`: 1000 ns (1 µs) — filters sub-µs glitches.
- `signal_range_max_ns`: 1_500_000 ns (1500 µs) — caps merge window; pulses longer than 1500 µs indicate bus fault.

### 6. Recovery delay

After each exchange (success, invalid, or timeout), `send_request` blocks for 100 ms before returning. This matches the C++ `DELAY` state and prevents back-to-back requests from violating the OpenTherm inter-message gap.

### 7. Module structure

```
src/opentherm.rs
  pub enum MessageType        // ReadData, WriteData, ReadAck, WriteAck, ...
  pub enum ResponseStatus     // None, Success, Invalid, Timeout
  pub struct OpenTherm        // the driver
    pub fn new(in_pin, out_pin) -> Result<Self, EspError>
    pub fn send_request(&self, request: u32) -> u32
    pub fn last_status(&self) -> ResponseStatus
    pub fn build_request(msg_type, data_id, data) -> u32   // pure
    pub fn get_message_type(frame: u32) -> MessageType     // pure
  // private:
  fn encode_frame(frame: u32) -> [rmt_symbol_word_t; 35]  // 34 + end marker
  fn decode_symbols(items: &[rmt_symbol_word_t]) -> Result<u32, ()>
  fn odd_parity(frame: u32) -> bool
```

Under `#[cfg(feature = "simulate-ot")]` the struct body is replaced with mock counters (mirrors the current `opentherm_ffi.rs` simulate path in `ot_master.rs`).

## Risks / Trade-offs

- **RMT RX jitter:** The hardware timestamping is accurate to ~1 µs. With a 750 µs threshold and ±50 µs real-world tolerance the half-bit expansion is reliable. A noisy bus could produce pulses near the threshold; the `signal_range_min_ns` filter mitigates transient spikes.
- **RMT channel availability:** ESP32 has 8 RMT channels (4 TX, 4 RX in v5 driver). One TX and one RX channel are consumed. Other peripherals (IR, LED strip) on the same board compete for these; this project uses no other RMT consumers.
- **`esp-idf-sys` raw binding breakage:** If ESP-IDF is upgraded past a major version the raw RMT API may change (it did between v4 and v5). The risk is accepted — the firmware is pinned to a specific ESP-IDF version via `.embuild`.

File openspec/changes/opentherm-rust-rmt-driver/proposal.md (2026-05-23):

## Why

The current OpenTherm driver is a C++ component (`components/opentherm/`) bridged to Rust via an FFI layer. It disables interrupts for the entire 34-bit frame transmission — at 500 µs per half-bit that is ~34 ms of global interrupt disable per request. During OTA firmware flashing the ESP32 WiFi/TCP stack relies on frequent interrupt service; the 34 ms blackout causes packet drops, retransmits, and perceived UI lag. Additionally, the C++ component adds build complexity: a hand-rolled cross-compiler invocation in `build.rs`, an Arduino.h shim, and ~30 ESP-IDF include paths wired up manually.

## What Changes

- New pure-Rust OpenTherm driver in `src/opentherm.rs` using the ESP32 RMT peripheral for both TX and RX. RMT handles precise µs-level timing in hardware; no interrupt disabling is required.
- `src/opentherm_ffi.rs` deleted. `ot_master.rs` updated to import from `src/opentherm.rs`; the public API is kept identical so no logic changes are needed.
- `components/opentherm/` directory deleted (C++ source, Arduino.h shim, FFI wrappers).
- `build.rs` simplified: `compile_opentherm()` and all its cross-compiler discovery logic removed. `cc` build-dependency removed from `Cargo.toml`.
- `simulate-ot` feature retained and still works via `#[cfg(feature = "simulate-ot")]` gating inside the new module.

## Capabilities

### New Capabilities

_None_ — protocol behaviour is identical to the current driver.

### Modified Capabilities

_None_ — the same OpenTherm master role, same data IDs, same 1 s timeout, same 100 ms recovery delay.

## Impact

- **`src/opentherm.rs`** (new): RMT-based driver — frame encode/decode, TX, RX, parity, status.
- **`src/opentherm_ffi.rs`** (deleted): replaced by the new module.
- **`src/ot_master.rs`**: one-line import change (`opentherm_ffi` → `opentherm`).
- **`src/main.rs`**: same one-line import change if it re-exports the type.
- **`components/opentherm/`** (deleted): entire C++ component tree.
- **`build.rs`**: `compile_opentherm()` function and its dependencies removed; WiFi credential forwarding untouched.
- **`Cargo.toml`**: `cc = "1"` build-dependency removed.

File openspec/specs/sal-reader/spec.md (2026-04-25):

## ADDED Requirements

### Requirement: Read Saleae .sal capture files
The system SHALL accept `.sal` files as input and extract analog voltage samples from them. A `.sal` file is a ZIP archive containing `analog-0.bin` (packed `float32` little-endian samples) and `meta.json` (capture metadata).

#### Scenario: Decode from .sal file
- **WHEN** user provides a valid `.sal` file path
- **THEN** the system SHALL extract `analog-0.bin` and `meta.json` from the ZIP, parse the binary float32 samples, reconstruct timestamps using the sample rate from `meta.json`, and produce voltage samples identical in structure to CSV-loaded samples

#### Scenario: Missing analog data in .sal
- **WHEN** user provides a `.sal` file that does not contain `analog-0.bin`
- **THEN** the system SHALL exit with an error message indicating no analog data was found

#### Scenario: Invalid or corrupt .sal file
- **WHEN** user provides a file with `.sal` extension that is not a valid ZIP archive
- **THEN** the system SHALL exit with an error message indicating the file could not be read

### Requirement: Extract sample rate from meta.json
The system SHALL read the analog sample rate from `meta.json` at the path `data.legacySettings.sampleRate.analog` and use it to compute sample timestamps as `index / sampleRate`.

#### Scenario: Sample rate extraction
- **WHEN** a `.sal` file is opened
- **THEN** the system SHALL read the sample rate from `meta.json` and use it to generate accurate time values for each sample

#### Scenario: Missing sample rate in meta.json
- **WHEN** `meta.json` does not contain a valid sample rate at the expected path
- **THEN** the system SHALL exit with an error message indicating the sample rate could not be determined

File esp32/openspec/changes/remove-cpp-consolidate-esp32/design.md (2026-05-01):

## Context

Current repo structure:
```
opentherm-wolf-cwl/
├── esp32/          ← C++ PlatformIO project (legacy, unused)
│   ├── src/        ← C++ source
│   ├── web/        ← Preact SPA (actively used by Rust build)
│   ├── data/       ← web build output (SPIFFS content)
│   └── ...
├── esp32-rust/     ← Rust firmware (active project)
│   ├── src/
│   ├── Makefile    ← references ../esp32/web for web build
│   └── ...
├── openspec/       ← root openspec (references esp32-rust/)
└── ...
```

The Rust Makefile currently uses `WEB_SRC := ../esp32/web` and `WEB_OUT := ../esp32/data` to build the web UI and create the SPIFFS image.

## Goals / Non-Goals

**Goals:**
- Remove the legacy C++ project entirely
- Move web source into the Rust project directory
- Rename `esp32-rust` → `esp32` for a clean structure
- Preserve git history via `git mv` where possible
- Update all internal path references

**Non-Goals:**
- Changing any Rust source code or web UI code
- Modifying build logic beyond path adjustments
- Restructuring the web project internally

## Decisions

### 1. Operation order: move web first, delete C++, then rename

**Choice**: 
1. `git mv esp32/web esp32-rust/web` — move web into Rust project
2. `git rm -r esp32/` — remove the C++ project  
3. `git mv esp32-rust esp32` — rename to final location

**Rationale**: Moving web first preserves its git history cleanly. Deleting C++ after extraction ensures nothing is lost. The final rename gives us the clean `esp32/` directory.

### 2. Web build output stays at `./data` relative to the project

**Choice**: Update Makefile to `WEB_SRC := web` and `WEB_OUT := data`. The SPIFFS image is built from `data/` which will be at `esp32/data/`.

**Rationale**: Keeps the web build self-contained within the project. No more cross-directory references.

### 3. Root openspec directory handling

**Choice**: The root `openspec/` directory stays at the repo root (it's repo-level configuration). The `esp32-rust/openspec/` directory moves with the rename to `esp32/openspec/`.

### 4. Handle .gitignore updates

**Choice**: Check root `.gitignore` for any `esp32-rust/` or `esp32/data` paths and update them to reflect the new `esp32/` structure.

## Risks / Trade-offs

- **[Breaking external references]** → Anyone with scripts or CI referencing `esp32-rust/` will need updates. Mitigated by this being a personal project.
- **[Git blame on renamed files]** → `git mv` preserves history, `git log --follow` will track the renames.

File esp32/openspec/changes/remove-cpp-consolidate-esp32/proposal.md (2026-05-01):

## Why

The C++ ESP32 application (`esp32/`) is legacy — all functionality has been reimplemented in the Rust firmware (`esp32-rust/`). The web UI source (`esp32/web/`) is already used exclusively by the Rust build. Keeping the old C++ project causes confusion about which is the active codebase. Consolidating to a single `esp32/` directory simplifies the repo structure.

## What Changes

- Move `esp32/web/` into `esp32-rust/web/` (co-locate web source with the Rust project)
- Delete the entire `esp32/` directory (C++ source, PlatformIO config, scripts, data output)
- Rename `esp32-rust/` to `esp32/`
- Update the Makefile paths (`WEB_SRC`, `WEB_OUT`) to reference `./web` and `./data` (now local)
- Update any other cross-references (gitignore, README, etc.)

## Capabilities

### New Capabilities

### Modified Capabilities

## Impact

- **BREAKING**: The `esp32/` path changes meaning (was C++, becomes Rust)
- `esp32-rust/Makefile` — path updates for web build
- Root `.gitignore` — may reference `esp32/data/` or `esp32-rust/` paths
- `README.md` — references to project structure
- `openspec/` at root — references to `esp32-rust/` if any
- Git history preserved via `git mv`

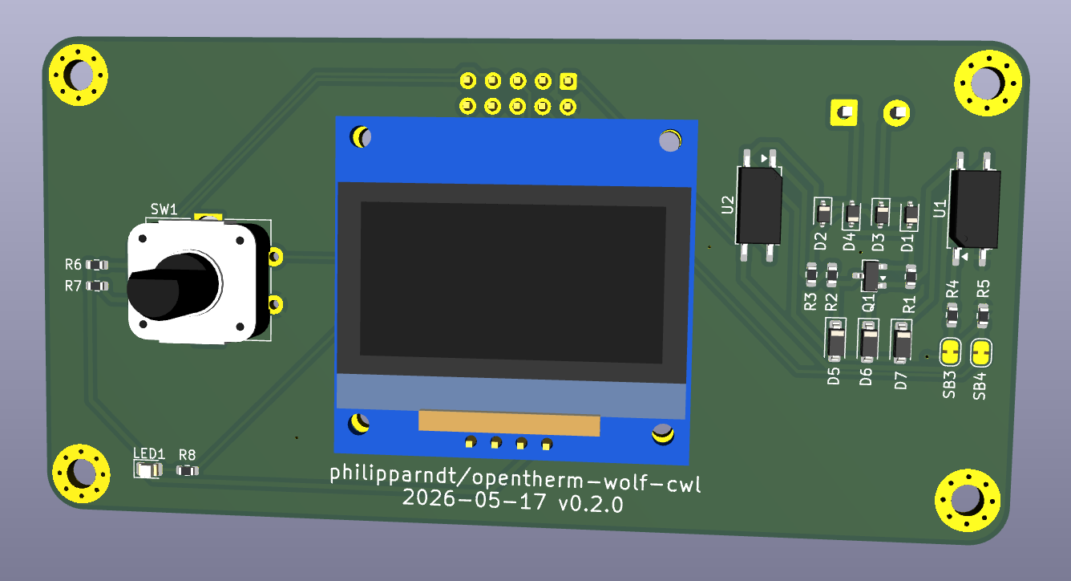
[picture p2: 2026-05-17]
pcb/pcb-front.png

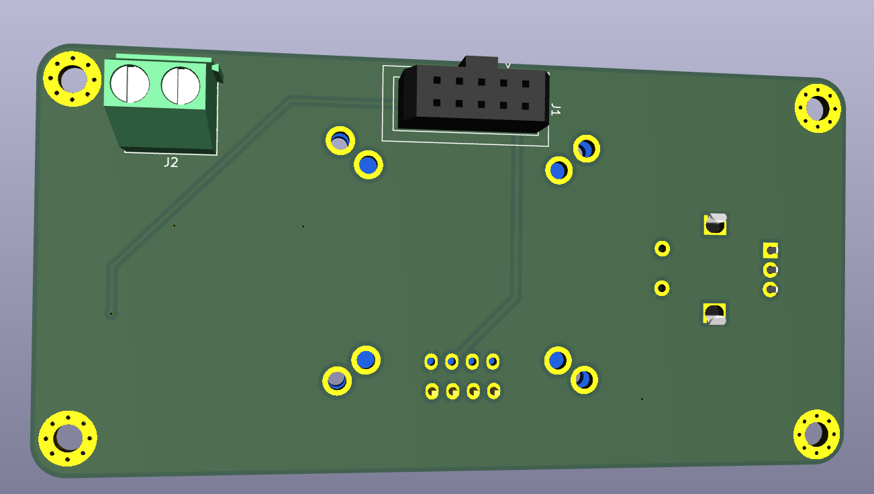
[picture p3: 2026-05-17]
pcb/pcb-back.png

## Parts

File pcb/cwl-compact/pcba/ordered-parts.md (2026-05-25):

# JLCPCB PCBA — Ordered Parts (cwl-compact)

Parts matched via JLCPCB's BOM tool. Copy the LCSC numbers into the schematic's
`LCSC` field on each symbol to pre-populate the BOM for future orders.

| Ref | Value | Footprint | LCSC | Library  | Notes |
|---|---|---|---|---|---|
| R1, R4  | 330Ω  | Resistor_SMD:R_0603_1608Metric | C23138 | Basic | 0603WAF3300T5E, ±1%, ±100ppm/℃ |
| R2 | 220Ω  | Resistor_SMD:R_0603_1608Metric | C22962 | Basic | 0603WAF2200T5E, ±1%, ±100ppm/℃ |
| R3 | 100Ω  | Resistor_SMD:R_0603_1608Metric | C22775 | Basic | 0603WAF1000T5E, ±1%, ±100ppm/℃ |
| R5 | 1.5k  | Resistor_SMD:R_0603_1608Metric | C22843 | Basic | 0603WAF1501T5E, ±1%, ±100ppm/℃ |
| R6, R7  | 10k | Resistor_SMD:R_0603_1608Metric | C25804 | Basic | 0603WAF1002T5E, ±1%, ±100ppm/℃ |
| R8 | 1k | Resistor_SMD:R_0603_1608Metric | C21190 | Basic | 0603WAF1001T5E, ±1%, ±100ppm/℃ |
| LED1 | Green | LED_SMD:LED_0805_2012Metric | C2297  | — | KT-0805G, 2.6–3.1 V, 430 mcd |

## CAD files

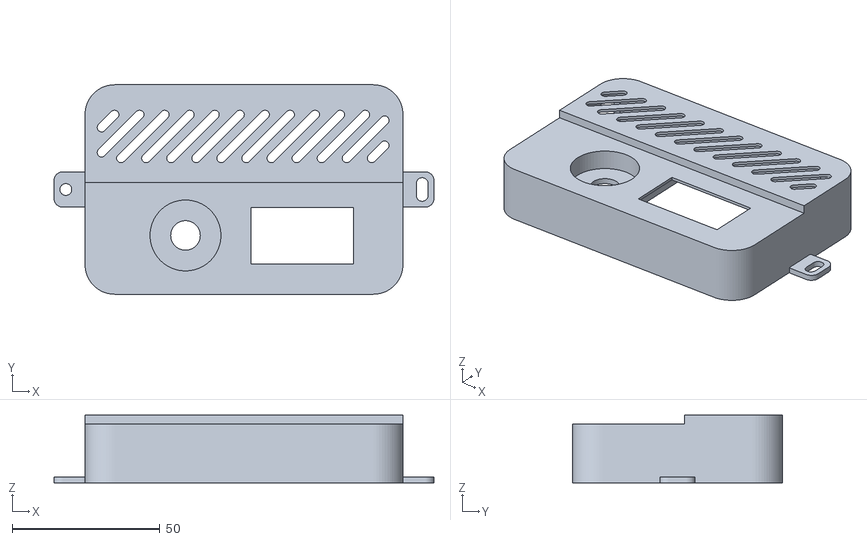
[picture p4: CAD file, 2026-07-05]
case/front.stl
128.6 x 70.9 x 23.0

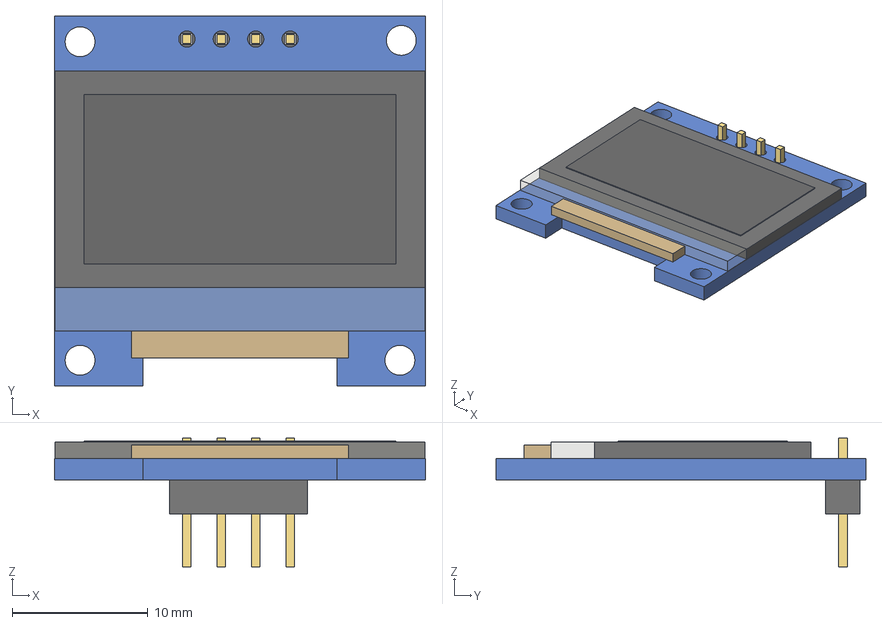
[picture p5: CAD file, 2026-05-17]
pcb/3dmodels/OLED_SH1106_0.96inch.step
27.4 x 27.3 x 9.50 mm
pcb
glass_dark
glass_trans
display
fpc
oled_pins
spacer

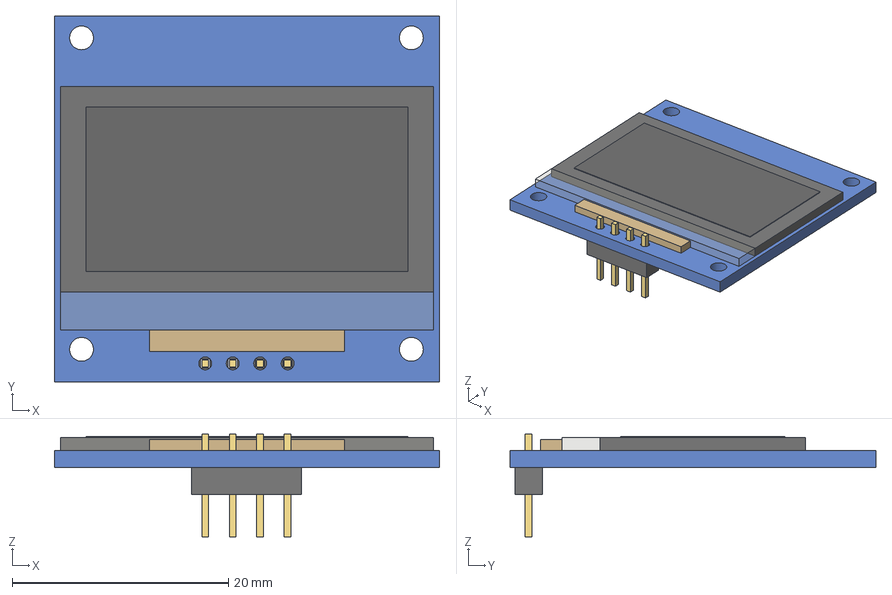
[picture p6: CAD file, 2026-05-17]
pcb/3dmodels/OLED_SH1106_1.3inch.step
35.6 x 33.8 x 9.50 mm
pcb
glass_dark
glass_trans
display
fpc
oled_pins
spacer

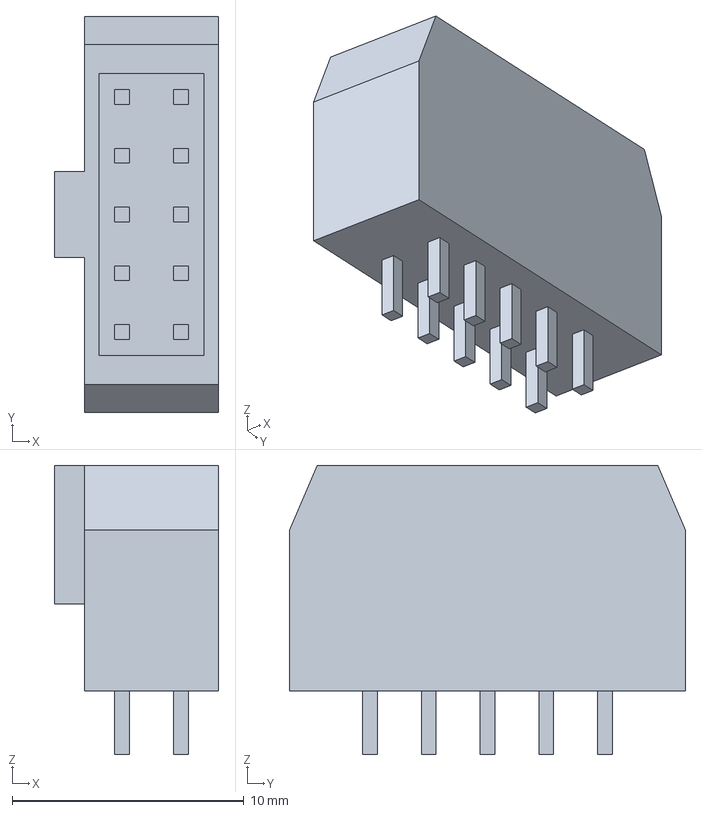
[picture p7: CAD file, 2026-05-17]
pcb/3dmodels/IDC-Socket_2x05_P2.54mm_Vertical_printable.step
7.10 x 17.1 x 12.5 mm

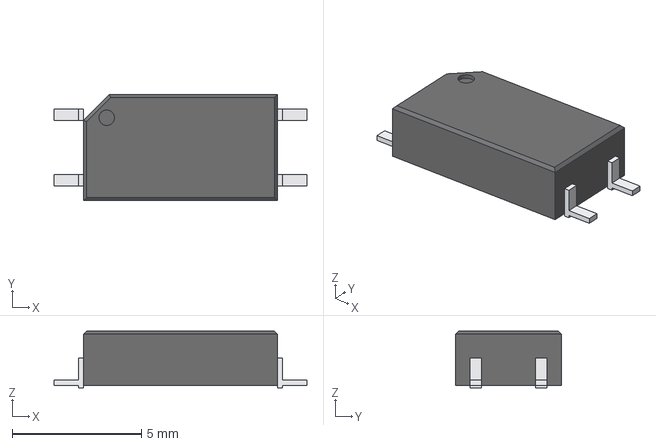
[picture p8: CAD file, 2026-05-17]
pcb/3dmodels/SOP-4_7.5x4.1mm_P2.54mm.step
9.78 x 4.10 x 2.20 mm
leads

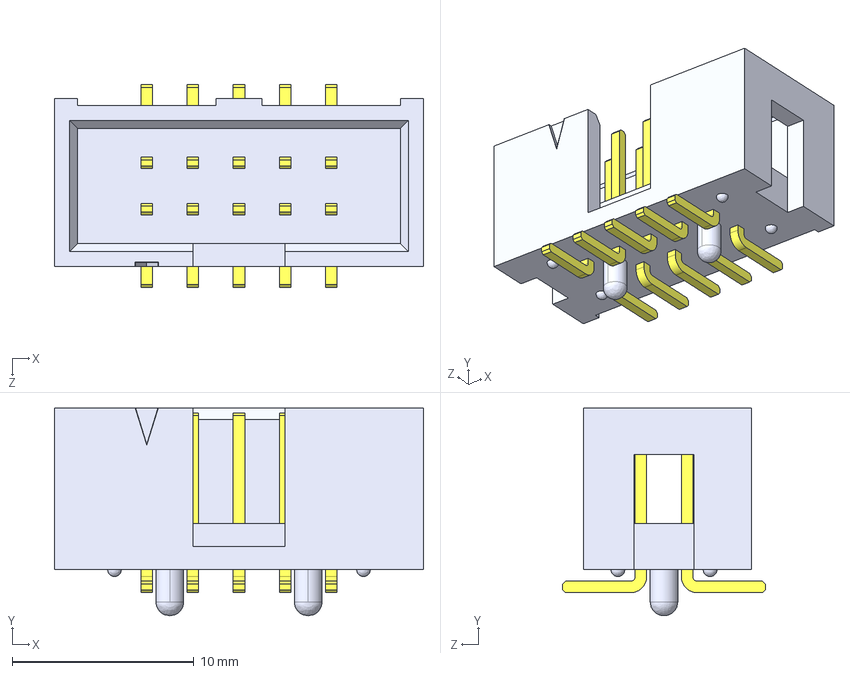
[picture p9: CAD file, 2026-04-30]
pcb/3dmodels/UEXT-SMD.STEP
20.3 x 11.4 x 11.2 mm
User Library-HTST-105-01-F-DV-A__HTST-105-01-DV-A_header
User Library-HTST-105-01-F-DV-A__HTST-First_Position_Indicator
User Library-HTST-105-01-F-DV-A__T-1S6-05-01-DV_

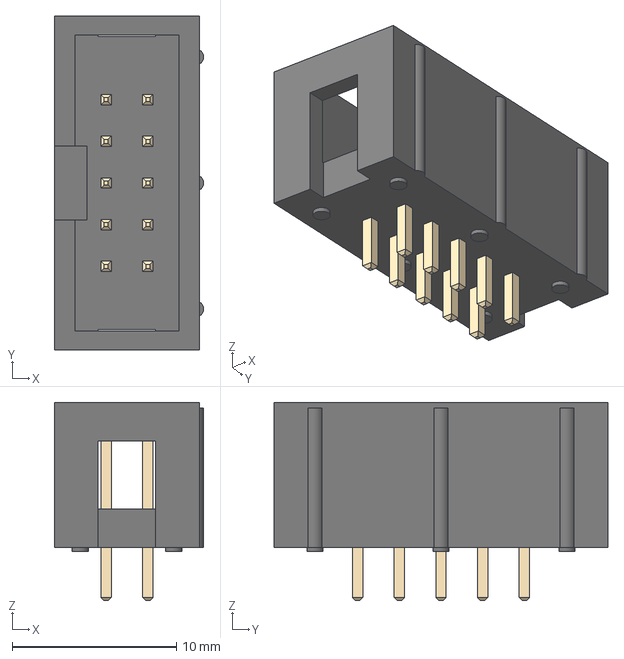
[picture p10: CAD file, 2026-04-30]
pcb/3dmodels/IDC-Header_2x05_P2.54mm_Vertical.step
9.10 x 20.4 x 12.1 mm

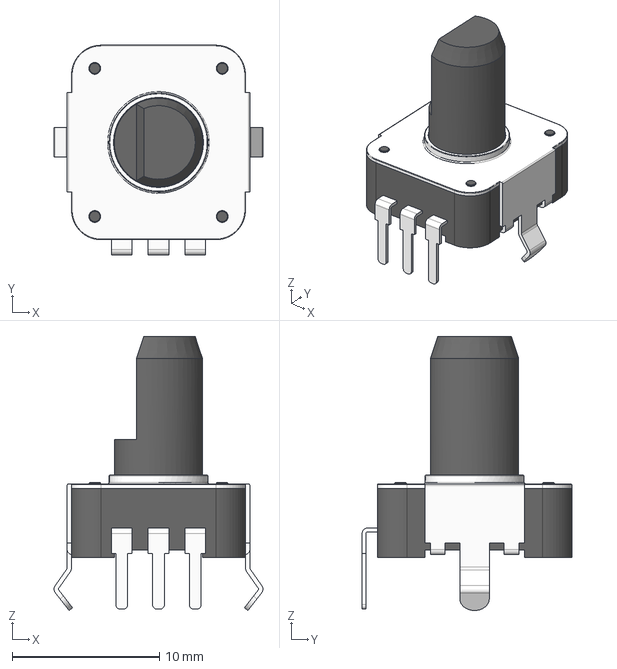
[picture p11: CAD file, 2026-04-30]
pcb/3dmodels/EC12 Encoder 10mm 3pin.step
14.2 x 14.2 x 18.6 mm

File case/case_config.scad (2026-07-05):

// Shared case configuration. Included by front.scad and back.scad so both
// parts stay dimensionally in sync.

offset      = 3;
border      = 2;
case_width  = 110;
case_length = 72;
case_radius = 10;
h           = 20;

standoff_chamfers = true;   // lead-in chamfers on the standoff screw holes
slim              = true;   // pull bottom + left + right walls in to the round standoffs
slim_inset        = 0.9;    // clearance between each round standoff edge and the inner wall

// Mounting-ear thickness (z) per part.
latch_h_front = 2;          // front shell ears
latch_h_back  = 1;          // back plate ears

back_lip_w    = 1.2;        // back plate locating-lip wall thickness

// Round standoff centres (PCB-fixed), as placed by stands().
rstand_o  = 10;
rstand_xL = case_width/2 - 45.6;   // 9.4
rstand_xR = case_width/2 + 46.2;   // 101.2
rstand_y  = 9;

// Case outer boundary. slim brings bottom/left/right in to the standoffs; top fixed.
x0 = slim ? rstand_xL - rstand_o/2 - slim_inset - border : 0;
x1 = slim ? rstand_xR + rstand_o/2 + slim_inset + border : case_width;
y0 = slim ? rstand_y  - rstand_o/2 - slim_inset - border : 0;
y1 = case_length;
cw = x1 - x0;        // outer width
cl = y1 - y0;        // outer length

bottom_z   = -10;    // z of the case floor / wall bottom
stand_sink = 5.5;    // how far a standoff body drops below z = 0

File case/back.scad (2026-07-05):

use <./utils.scad>
use <./front.scad>          // mounting_latch
include <./case_config.scad>

// ============================ Back plate ============================
// Flat plate closing the open back of the case. A small step nests inside the
// front's cavity to locate it, and it carries the same mounting ears as the
// front. Modelled flat-face-down (z=0) for printing.

plate_t       = 1;     // flat plate thickness
step_h        = 3;   // locating lip height (sits inside the front cavity)
fit_clearance = 0.5;   // gap between the lip and the inner cavity wall

module back_plate() {
    inset = border + fit_clearance;   // lip distance from the outer edge
    lip_w = back_lip_w;               // lip wall thickness (a thin locating line)

    // closed flat plate on the case outer footprint
    linear_extrude(height=plate_t)
        rounded_rectangle(width=cw, length=cl, r=case_radius, fn=64);

    difference() {
        // thin locating lip stepping up into the cavity
        translate([0, 0, plate_t])
            linear_extrude(height=step_h)
                difference() {
                    translate([inset, inset])
                        rounded_rectangle(width=cw-2*inset, length=cl-2*inset,
                        r=case_radius-inset, fn=64);
                    translate([inset+lip_w, inset+lip_w])
                        rounded_rectangle(width=cw-2*(inset+lip_w), length=cl-2*(inset+lip_w),
                        r=case_radius-inset-lip_w, fn=64);
                }

        translate([0, 0, plate_t])
            cube([20,20,10]);

        translate([cw-20, 0, plate_t])
            cube([20,20,10]);

        translate([0, cl-20, 0]) {
            translate([0, 0, plate_t])
                cube([20,20,10]);

            translate([cw-20, 0, plate_t])
                cube([20,20,10]);
        }
    }
}

back_plate();

// Mounting ears (same as the front): left round hole, right adjustment slot,
// flush with the flat outer face.
translate([0,  cl/2 - 6, 0])
    mirror([1,0,0])
        mounting_latch(long=false, t=latch_h_back);

translate([cw, cl/2 - 6, 0])
    mounting_latch(long=true, t=latch_h_back);

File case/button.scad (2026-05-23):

// Handle opener for Linea Mini R knobs

// Parameters
diameter = 22;          // Main body diameter
height = 15;            // Extrusion height
grip_count = 12;        // Number of grip cutouts
grip_depth = 1;         // How deep the grip cutouts go
grip_cylinder_d = 8;    // Diameter of the cylinders for rounded cutouts

fillet_radius = 4;      // Top edge fillet radius

engrave_depth = 0.6;    // Depth of engraved text and arrow
arrow_radius = 10;      // Radius of the curved arrow
arrow_width = 2;        // Width of arrow line

inner_radius = 3.05;      // Inner radius for the knob tab cutout
outer_radius = 3.5;       // Outer radius for the knob tab cutout

$fn = 128;

difference() {
    // Main cylinder body
    cylinder(d = diameter, h = height);

    // Grip cutouts around the perimeter
    for (i = [0:grip_count-1]) {
        angle = i * 360 / grip_count;
        rotate([0, 0, angle])
            translate([diameter/2 + grip_cylinder_d/2 - grip_depth, 0, -1])
                cylinder(d = grip_cylinder_d, h = height + 2);
    }

    translate([0,0,height/2-1])
        cylinder(r=inner_radius, h=height-2, center=true);

    translate([0,0,2/2])
        cylinder(r=outer_radius , h=2, center=true);


    // Top edge fillet
    translate([0, 0, height])
        rotate_extrude()
            translate([diameter/2 - fillet_radius, -fillet_radius])
                difference() {
                    square([fillet_radius + 1, fillet_radius]);
                    circle(r = fillet_radius);
                }
}

translate([1.4/2-inner_radius,0,height-8])
cube([1.4, 10, 10], center=true);

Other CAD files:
pcb/3dmodels/IDC-Socket_2x05_P2.54mm_Vertical.step
case/display_front.scad
case/front.scad
case/utils.scad
pcb/oled_1_3.scad

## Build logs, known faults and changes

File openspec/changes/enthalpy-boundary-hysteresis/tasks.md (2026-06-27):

## 1. Decision hysteresis (`esp32/src/humidity.rs`)

- [x] 1.1 Add constants `H_COOL_ON = -1.0` and `H_COOL_OFF = 0.0` next to `H_OFF`/`H_PARTY`, with a doc comment explaining the neutral band around `Δh = 0`
- [x] 1.2 Change `enthalpy_level(inp)` to `enthalpy_level(inp, was_cooling)`: keep Off (`> H_OFF`) and Party (`< H_PARTY`); in between, `cooling = if was_cooling { dh < H_COOL_OFF } else { dh < H_COOL_ON }`; map `cooling` → `(Normal, true)` else `(Reduced, false)`
- [x] 1.3 Unit tests: not-cooling holds Reduced for `Δh ∈ (H_COOL_ON, H_COOL_OFF]`; not-cooling enters Normal below `H_COOL_ON`; cooling holds Normal for `Δh ∈ [H_COOL_ON, H_COOL_OFF)`; cooling releases to Reduced above `H_COOL_OFF`; `< H_PARTY` still Party; `> H_OFF` still Off
- [x] 1.4 Regression test reproducing the live event: indoor h≈63.2, outdoor h 63.5→63.3 while `was_cooling=false` stays Reduced/not-cooling (no flip to cooling)

## 2. Wire cooling state + hold reason (`esp32/src/extreme_heat.rs`)

- [x] 2.1 In `decide`, derive `was_cooling = st.eh_current_reason == Reason::CoolingAssist` and pass it to `enthalpy_level`; `decide` now also returns `Option<dh>`
- [x] 2.2 Compute the hold cause in `update()`: decided level == held level and `deadband_holding(dh, level)` → `HoldReason::Deadband`; a *different* level decided but `now_epoch - eh_last_change_epoch < EH_DWELL_SECS` → `HoldReason::Dwell` (+ `eh_pending_level`); else `None`
- [x] 2.3 Store the hold cause (`eh_hold`) and `eh_pending_level` in `app_state`; clear on `record_change`, manual override, and when extreme-heat doesn't own the level
- [x] 2.4 Update the existing tests/call sites that invoke `enthalpy_level` with one argument

## 3. API (`esp32/src/webserver.rs`, `esp32/src/app_state.rs`)

- [x] 3.1 Add `HoldReason` enum + `eh_hold`/`eh_pending_level` to `app_state`; expose `holdReason` (`"none"|"deadband"|"dwell"`), `pendingLevel`, `dwellRemainingSecs` on `/api/status`. (Δh is derivable in the UI from the existing `indoor/outdoorEnthalpy`, so no separate field.)
- [x] 3.2 `dwellRemainingSecs` is computed live in the status handler from `eh_last_change_epoch`; the hold fields are set at the same per-minute evaluation as the reason

## 4. Web explainer (`esp32/web/src/StatusTab.tsx`, `translations.ts`)

- [x] 4.1 Render a "holding because …" line: deadband → "outdoor & indoor energy within the neutral band (Δh …)"; dwell → "would switch to {level} in {mm:ss} (dwell)"
- [x] 4.2 Hold notice is rendered distinctly from the active-rule line so a held decision doesn't read as an imminent switch
- [x] 4.3 Relabel the outdoor/indoor figures (via `aggregateHint`) so RH (max-RH sensor) and AH/h (wettest sensor @ aggregate T) are not presented as one consistent air mass
- [x] 4.4 Add translation keys (`holdDeadband`, `holdDwell`) in EN + DE
- [x] 4.5 Update `StatusTab.test.tsx` for the hold-reason rendering (deadband Δh, dwell countdown, none)

## 5. Boot robustness & actual-level display (from live-device findings)

- [x] 5.1 `humidity.rs`: `aggregate_side` returns `None` when no fresh sensor temperature exists and the inlet fallback is implausible, instead of fabricating an air state (+ unit test)
- [x] 5.2 `webserver.rs`: gate the derived humidity/enthalpy block on `cwl_data.connected`, so the explainer never shows a boot-transient air state (e.g. the observed indoor h ≈ 37.9)
- [x] 5.3 `cwl_data.rs`: add `VentLevel::from_relative_pct` (ID 77 % → level); reuse it in `ot_master.rs` (initial-level inference) and expose `ventilation.actualLevel` on `/api/status`
- [x] 5.4 `StatusTab.tsx`: highlight the unit's **actual** level (`actualLevel`) at the top, not the commanded one; clear the pending spinner on `actualLevel`
- [x] 5.5 `StatusTab.tsx` + `translations.ts`: show a "waiting for the unit" state when disconnected (instead of "data stale"); add `reasonText` for `schedule`/`reboot` so the explanation is never blank
- [x] 5.6 `StatusTab.test.tsx`: actual-vs-commanded highlight, and the waiting-for-unit note

## 6. Verification

- [ ] 6.1 `cargo +esp build --release` builds clean _(NOT RUN: this environment has no ESP-IDF / Xtensa toolchain — `IDF_PATH` empty, `esp-idf-sys` rejects the host target. Must be built on a device-capable machine.)_
- [x] 6.2 Web `tsc --noEmit` + `vite build` clean; `vitest` 26/26 pass (hold-notice, actual-level, waiting-for-unit). _Rust unit tests are written but cannot run here (same toolchain gap as 6.1); run `cargo test` on the ESP-capable host._
- [ ] 6.3 Manual: drive a Δh slowly across zero and confirm the level/reason hold through the neutral band with the deadband notice; force a pending switch and confirm the dwell countdown; reboot and confirm the explainer shows "waiting for the unit" (no h≈38 transient) and the top shows the actual level _(requires device + broker)_

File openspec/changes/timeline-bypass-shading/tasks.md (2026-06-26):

## 1. Bypass transition log (firmware state)

- [x] 1.1 Add a `BypassEvent { epoch: i64, open: bool }` type and a bounded `bypass_events: VecDeque<BypassEvent>` to `AppStateInner` (cap as a named const, e.g. `BYPASS_EVENT_CAPACITY`, generous for 24 h of toggling)
- [x] 1.2 Add a single chokepoint helper (e.g. `AppStateInner::set_bypass_open(open, epoch)`) that updates `requested_bypass_open` and, only on an actual change, appends a transition (oldest dropped when full); make all writers go through it
- [x] 1.3 Route the three writers through the helper: extreme-heat (`extreme_heat.rs`), the calendar bypass schedule (`scheduler.rs`), and the manual web/MQTT/encoder paths (`webserver.rs` / `mqtt.rs` / `display.rs`)

## 2. Expose & persist the bypass log

- [x] 2.1 Build a `bypass` JSON array of `{epoch, open}` in the `/api/history` handler (`webserver.rs`), mirroring how `events` is built from `eh_events`
- [x] 2.2 Extend `TempHistory::full_json` (or the handler) to include the `bypass` field in the `/api/history` payload
- [x] 2.3 Include the bypass transitions in the retained `persist/temp_history` MQTT snapshot (`snapshot_json`) and restore them in `restore_from_snapshot`; treat a missing field as "no shading data"

## 3. Decouple the chart component (frontend)

- [x] 3.1 Rename `web/src/ExtremeHeatChart.tsx` → `web/src/TimelineChart.tsx` and rename the exported component to `TimelineChart`
- [x] 3.2 Update the import/usage in `StatusTab.tsx`; confirm the chart renders independent of `status.extremeHeat.enabled` and that level-change markers/legend only appear when events exist

## 4. Bypass background shading (frontend)

- [x] 4.1 Add `bypass: { epoch: number; open: boolean }[]` to the `History` type in `api.ts`
- [x] 4.2 Build bypass spans from the transitions over the window: order by epoch, derive the left-edge state as the inverse of the earliest transition's `open`, and clamp span x-coords with the existing `eventX` epoch→x mapping
- [x] 4.3 Render one background `<rect>` per span (y `PAD_T..PAD_T+PLOT_H`), drawn first so it sits behind gridlines/series/markers; fill closed spans with a base gray and open spans with a slightly brighter gray
- [x] 4.4 Add two theme-aware CSS custom properties for the tones (e.g. `--chart-bg`, `--chart-bg-bypass`) in `style.css`
- [x] 4.5 Add a legend entry for the bypass shading and EN/DE strings in `translations.ts`

## 5. Verification

- [x] 5.1 `cargo check` against the esp32 target compiles cleanly; unit-test the transition-log helper (records only on change, drops oldest when full)
- [x] 5.2 `npm run build` (tsc + vite) succeeds and writes the bundle to `esp32/data/`
- [ ] 5.3 Manually verify in simulate-ot mode: toggling the bypass paints a brighter band for open spans aligned to the time axis, the leading span before the first transition is tinted correctly, and the timeline renders with Extreme Heat off _(requires flashing the esp32 / simulator — no xtensa+esp-idf toolchain in this environment)_
- [ ] 5.4 Verify the shading survives a reboot via the retained history snapshot _(requires a device — same toolchain limitation)_

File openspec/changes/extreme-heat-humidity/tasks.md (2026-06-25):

## 1. Psychrometrics

- [x] 1.1 Create `esp32/src/psychro.rs` with pure functions: `saturation_kpa(t)`, `vapor_kpa(t,rh)`, `absolute_humidity(t,rh) -> g/m³`, `enthalpy(t,rh,p_atm_kpa) -> kJ/kg` (pressure-aware)
- [x] 1.2 Unit-test against known psychrometric points (e.g. 27 °C/55 %, 38.7 °C/30.5 %)

## 2. Config & persistence

- [x] 2.1 Add `humidity_inside_topics: Vec<String>`, `humidity_outside_topic: String`, and `humidity_protection_enabled: bool` to `AppConfig` (defaults empty / false)
- [x] 2.2 Persist/load them in `config_manager.rs` as JSON keys (pattern of `save_schedules`); include in backup/restore
- [x] 2.3 Define tunable constants: `SENSOR_STALE_SECS=1800`, `RH_PROTECT=65`, `RH_PROTECT_HIGH=75`, `AH_MARGIN=0.5`, enthalpy bands `H_OFF=2.0`, `H_PARTY=-4.0`

## 3. Sensor ingestion (`mqtt.rs` + `app_state.rs`)

- [x] 3.1 Add a sensor store to `app_state`: indoor map `topic -> HumiditySample{humidity, temperature: Option<f32>, pressure: Option<f32>, updated_ms}`, an outdoor `Option<(String, HumiditySample)>`, and an `ambient_pressure_kpa` (default 101.3)
- [x] 3.2 In `setup_subscriptions` (and a re-subscribe check each tick), subscribe to every configured sensor topic; idempotent so topic edits apply without reboot
- [x] 3.3 In the MQTT receive handler, match configured sensor topics and parse `humidity` (required) + `temperature`/`pressure` (optional), storing the latest sample with a timestamp; update `ambient_pressure_kpa` from any reported pressure; ignore malformed payloads
- [x] 3.4 Add a freshness helper (sample age vs `SENSOR_STALE_SECS`)

## 4. Humidity-aware decision (`extreme_heat.rs`)

- [x] 4.1 Add a `Reason` enum (`TempDelta|CoolingAssist|Dehumidify|MuggySuppression|Manual`) and store current reason in `app_state`; add `reason` to `EhEvent`
- [x] 4.2 Compute fresh indoor aggregate (max `AH`, matching `h`, max `RH`) and outdoor `AH`/`h` from `psychro`, passing `ambient_pressure_kpa` to `enthalpy`; substitute exhaust-inlet temp when a sensor lacks temperature
- [x] 4.3 Implement decision precedence: (1) moisture protection (gated by `humidity_protection_enabled`), (2) enthalpy bands and (3) temperature fallback (both gated by `extreme_heat_enabled`) — preserving the 15-min dwell and manual stickiness
- [x] 4.5 Implement standalone protection as a surgical override: when extreme-heat is off, only raise `requested_vent_level` while a protection condition holds (with RH hysteresis on at `RH_PROTECT`, off below `RH_PROTECT-5`), prevent the scheduler from lowering below it, and release control when it clears; never lower below the schedule/manual level
- [x] 4.4 Tag each applied change with its reason and record it in `eh_events`; set the publish flag so the retained snapshot updates

## 5. History + persistence for humidity

- [x] 5.1 Make `Channel` length-agnostic (use `self.slots.len()` instead of the global `HISTORY_SLOTS`); keep temperature channels at 1440
- [x] 5.2 Add indoor/outdoor humidity channels at ~288 slots (5-min); sample them from the aggregated readings
- [x] 5.3 `/api/history` includes the humidity series + per-event reason; the retained extreme-heat snapshot carries the per-event reason. _(Humidity history is NOT in the retained MQTT snapshot — deferred to keep it within one MQTT buffer / avoid OOM; humidity history rebuilds live after reboot.)_

## 6. API + web visualization

- [x] 6.1 Extend `/api/status` with per-sensor readings (humidity/temperature/pressure) + fresh/stale, the current ambient pressure, the current decision reason, and the derived `AH`/`h` values
- [x] 6.2 Add web config UI (Settings) to edit the indoor topic list + outdoor topic and a separate **Moisture Protection** enable toggle (independent of the extreme-heat toggle), posting to `/api/config`
- [x] 6.3 Combined chart: add indoor/outdoor humidity lines on a right-hand 0–100 % axis alongside the temperature lines, with a legend; degrade gracefully when humidity absent
- [x] 6.4 Annotate change markers with their reason (colour/icon + label)
- [x] 6.5 Add the live decision-explainer panel (current inputs incl. ambient pressure, derived AH/enthalpy, active rule, plain-language sentence, fallback notice)
- [x] 6.6 Add per-sensor status display (last humidity/temperature/pressure + fresh/stale badge)

## 7. Verification

- [x] 7.1 Unit-test the decision precedence: muggy-cooler → no ventilate; warm-drier → ventilate; humid-indoor+drier-outdoor → protect; humid-indoor+humid-outdoor → no protect; stale → temperature fallback; standalone protection (extreme-heat off) raises then releases with hysteresis and never lowers below schedule
- [x] 7.2 Build firmware (`cargo +esp build --release`) and web (`tsc` + `vite`)
- [ ] 7.3 Manual: publish the example sensor payloads (`zigbee2mqtt/og_temp_bad`, `garden/weather/indoor_dht`), confirm readings ingest, the explainer shows the right rule, markers carry reasons, and the chart overlays humidity _(requires a device + broker — flash to verify)_
- [ ] 7.4 Manual: take the outdoor sensor stale and confirm fallback to temperature-only with the explainer noting it _(requires a device)_

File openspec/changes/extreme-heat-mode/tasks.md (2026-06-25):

## 1. Config & state

- [x] 1.1 Add `extreme_heat_enabled: bool` to `AppConfig` with a default of `false`, and load/save it through the existing NVS config path (`/api/config` GET/POST + backup/restore)
- [x] 1.2 Add Extreme Heat fields to `AppStateInner`: `eh_current_level: u8`, `eh_last_change_epoch: i64`, and a bounded change-event ring buffer (e.g. `eh_events: VecDeque<(i64 /*epoch*/, u8 /*level*/)>` capped at ~64)
- [x] 1.3 Define named threshold/dwell constants (`EH_OFF_DELTA = 0.5`, `EH_PARTY_DELTA = -1.0`, `EH_DWELL_SECS = 900`)

## 2. Control logic (`extreme_heat.rs`)

- [x] 2.1 Create `esp32/src/extreme_heat.rs` and register it in `main.rs`
- [x] 2.2 Implement `select_level(supply: f32, exhaust: f32) -> VentLevel` mapping `delta = supply − exhaust` to the bands from the spec (Off / Reduced / Normal / Party)
- [x] 2.3 Implement the update step: skip when disabled, when epoch is invalid (`<= 1_700_000_000`), or when supply/exhaust temps are missing/invalid
- [x] 2.4 Apply the 15-minute dwell: only change `requested_vent_level` when the selected level differs AND `now_epoch − eh_last_change_epoch >= EH_DWELL_SECS`; on change, update `eh_current_level`, reset `eh_last_change_epoch`, and append an event
- [x] 2.5 Respect timed-off (do not raise level while `timed_off_active`)
- [x] 2.6 Handle manual override: when the user changes the level while the mode is enabled, adopt it as `eh_current_level` and reset the dwell timer
- [x] 2.7 Suppress time-of-day schedule effects while the mode is enabled (mutually exclusive ownership of `requested_vent_level`)
- [x] 2.8 Call the update step from the main loop / scheduler tick (~once per minute)

## 3. Backend API

- [x] 3.1 Add `GET /api/history` in `webserver.rs` returning supply & exhaust channels as JSON (per-bucket `{min,max}` oldest→newest, plus `bucketMs` and `newestBucketEpoch`/age)
- [x] 3.2 Add change-event data (`{epoch, level}[]`) — either `GET /api/heat-events` or an `events` array on `/api/history`
- [x] 3.3 Extend `/api/status` with Extreme Heat state (`enabled`, `currentLevel`, `lastChangeEpoch`)

## 4. Web UI

- [x] 4.1 Add API client functions in `web/src/api.ts` for the history + events endpoints and the new status fields
- [x] 4.2 Create a Preact SVG chart component plotting supply and exhaust series over time with a labelled temperature axis and distinct colours (existing CSS accent vars)
- [x] 4.3 Draw vertical markers at each change event, annotated with the selected level name (Off/Reduced/Normal/Party)
- [x] 4.4 Wire the chart into the status view and refresh it on the existing poll cadence (no full reload)
- [x] 4.5 Add an enable/disable toggle for Extreme Heat mode that posts to `/api/config`, reflecting current state

## 5. Verification

- [x] 5.1 Unit-test `select_level` band boundaries (including `delta = 0`, `+0.5`, `−1.0`) and the dwell gating logic
- [ ] 5.2 Manually verify in simulate-ot mode: temps crossing thresholds change the level only after the dwell, and markers appear on the web graph at each change _(requires flashing the esp32 / simulator — no xtensa+esp-idf toolchain in this environment)_
- [ ] 5.3 Verify disabled mode is fully inert (schedules/manual/timed-off unchanged) and that enabled state + config survive reboot _(requires a device — same toolchain limitation)_
- [x] 5.4 Rebuild the web bundle (Vite → `esp32/data/`); the SPIFFS image is packed from `data/` by `make build-fs`/`make flash` at flash time

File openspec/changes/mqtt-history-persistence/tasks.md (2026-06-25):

## 1. State plumbing

- [x] 1.1 Add to `AppStateInner`: `pending_history_json: Option<Vec<u8>>`, `pending_extreme_heat_json: Option<Vec<u8>>` (raw payloads handed from the MQTT callback to the main loop), initialised to `None`
- [x] 1.2 Add a signal the MQTT thread can act on for publishing: e.g. `mqtt_publish_history: bool` set true when a history bucket rolls over, and `mqtt_publish_extreme_heat: bool` set true when extreme-heat changes level / enabled state

## 2. Serialize / restore temperature history (`history.rs`)

- [x] 2.1 Add `TempHistory::snapshot_json(&self, now_epoch: i64) -> String` producing `{bucketMs, nowEpoch, supply, exhaust, delta}` with per-bucket `[min,max]`/`null`, oldest→newest (reuse the `/api/history` shape)
- [x] 2.2 Add `TempHistory::restore_from_snapshot(&mut self, json: &[u8])` that rebuilds each `Channel`'s `slots` + `head` (oldest→newest, head = newest) from a snapshot; ignore malformed input gracefully

## 3. Publish from MQTT (`mqtt.rs`)

- [x] 3.1 In `setup_subscriptions`, subscribe to `{base}/persist/temp_history` and `{base}/persist/extreme_heat`
- [x] 3.2 Add `publish_history_snapshot()` — serialize via `TempHistory::snapshot_json` and `pub_retained` to `persist/temp_history`
- [x] 3.3 Add `publish_extreme_heat_snapshot()` — build `{enabled,currentLevel,lastChangeEpoch,events[]}` JSON and `pub_retained` to `persist/extreme_heat`
- [x] 3.4 In `MqttManager::update`, consume the `mqtt_publish_history` / `mqtt_publish_extreme_heat` flags and call the matching publisher; also publish both once shortly after first connect / recovery

## 4. Trigger publishing from the producers

- [x] 4.1 In `main.rs`, set `mqtt_publish_history = true` when `temp_history.sample()` returns `true` (bucket rollover)
- [x] 4.2 In `extreme_heat.rs`, set `mqtt_publish_extreme_heat = true` when a level change is applied or the enabled state transitions

## 5. Recovery on boot

- [x] 5.1 In `handle_event`/a receive handler, detect messages on the two `persist/` topics; on the FIRST per topic after boot, copy the raw bytes into the matching `pending_*_json` buffer and set a per-topic `*_recovered` guard; drop later messages on those topics
- [x] 5.2 In the main loop, when `pending_history_json` is `Some`, take it and call `TempHistory::restore_from_snapshot`; mark the display dirty so the graph repaints
- [x] 5.3 In the main loop, when `pending_extreme_heat_json` is `Some`, take it and restore `eh_events`, `eh_current_level`, `eh_last_change_epoch` (do NOT override `config.extreme_heat_enabled` — NVS stays authoritative)
- [x] 5.4 Ensure parsing happens only in the main loop (callback does no `serde_json` work)

## 6. Guarantees & guards

- [x] 6.1 Confirm no flash/NVS writes are added on these paths (publishing/recovery touch only RAM + MQTT)
- [x] 6.2 When MQTT is disabled/not connected, ensure none of the new publishing runs and behaviour is unchanged
- [x] 6.3 Handle malformed / empty retained payloads without panicking (graceful no-op, keep current RAM data)

## 7. Verification

- [x] 7.1 Unit-test `snapshot_json` → `restore_from_snapshot` round-trips bucket min/max and ordering (incl. partial/empty channels)
- [x] 7.2 Build firmware (`cargo +esp build --release --features "wifi,simulate-ot,ot-ext"`)
- [ ] 7.3 Manual: with a broker, let history build, reboot, confirm the graph + extreme-heat markers repopulate from retained MQTT and that the broker shows the `persist/*` retained topics _(requires a device + broker — not runnable in this environment)_
- [ ] 7.4 Manual: with MQTT disabled, confirm history still resets on reboot and no `persist/*` topics are published _(requires a device — same limitation)_

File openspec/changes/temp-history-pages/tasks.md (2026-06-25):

## 1. History module — types and storage

- [x] 1.1 Create `src/history.rs` with the constants `HISTORY_SLOTS = 128`, `BUCKET_MS = 675_000`, `SAMPLE_INTERVAL_MS = 1_000`
- [x] 1.2 Define `Bucket { min: f32, max: f32 }` (`Debug, Clone, Copy`)
- [x] 1.3 Define `Channel { slots: [Option<Bucket>; HISTORY_SLOTS], head: usize }` with `Channel::new()` returning all-`None` and `head = 0`
- [x] 1.4 Define `TempHistory { outdoor: Channel, indoor: Channel, delta: Channel, bucket_start_ms: u32, last_sample_ms: u32 }` and `TempHistory::new()`

## 2. History module — sampling

- [x] 2.1 Add `fn fold(channel: &mut Channel, value: f32)` — initialise `slots[head]` to `Some(Bucket { min: value, max: value })` if `None`, otherwise update min/max in place
- [x] 2.2 Add `fn advance(channel: &mut Channel)` — set `slots[head] = None` (clear stale bucket about to be reused) **then** `head = (head + 1) % HISTORY_SLOTS`
- [x] 2.3 Implement `TempHistory::sample(&mut self, now_ms: u32, data: &CwlData) -> bool`:
  - Return `false` early if `now_ms.wrapping_sub(self.last_sample_ms) < SAMPLE_INTERVAL_MS`
  - Set `self.last_sample_ms = now_ms`
  - If `now_ms.wrapping_sub(self.bucket_start_ms) >= BUCKET_MS`: call `advance` on all three channels, set `bucket_start_ms = now_ms`, mark `rolled = true`
  - Always call `fold(outdoor, data.supply_inlet_temp)` and `fold(indoor, data.exhaust_inlet_temp)`
  - Call `fold(delta, data.supply_outlet_temp - data.supply_inlet_temp)` **only if** `data.supports_id81`
  - Return `rolled`
- [x] 2.4 Add `Channel::min_max(&self) -> Option<(f32, f32)>` — fold across populated slots, returning `None` if all `None`

## 3. App-state wiring

- [x] 3.1 In `src/app_state.rs`: import the new module, add `pub temp_history: history::TempHistory` to `AppStateInner`, initialise in `AppStateInner::new` via `TempHistory::new()`
- [x] 3.2 In `src/main.rs`: add `mod history;` next to the other module declarations

## 4. Main-loop integration

- [x] 4.1 In `src/main.rs` main loop body, after the existing `Watchdog` block and before the "Virtual encoder from web UI" block: lock `state`, call `state.temp_history.sample(now_ms, &state.cwl_data)`, capture the returned `rolled` bool, drop the lock
- [x] 4.2 If `rolled` is true, set `display_dirty.store(true, Ordering::Relaxed)` so the chart redraws on slot rollover

## 5. Display — Page enum and routing

- [x] 5.1 In `src/display.rs`: change `pub const PAGE_COUNT: usize = 6;` to `9`
- [x] 5.2 Extend `enum Page` with `OutdoorHistory`, `IndoorHistory`, `DeltaHistory` inserted between `TempIn` and `Status` (preserving discriminant order: Home=0, Bypass=1, TempIn=2, OutdoorHistory=3, IndoorHistory=4, DeltaHistory=5, Status=6, System=7, Settings=8)
- [x] 5.3 Update `Page::from_index` match arms to cover the 9 variants
- [x] 5.4 Add new arms to `render_content`'s `match page` for the three new pages, calling `draw_outdoor_history`, `draw_indoor_history`, `draw_delta_history`

## 6. Display — i18n strings

- [x] 6.1 In `src/i18n.rs` add fields to `Strings`: `outdoor_24h`, `indoor_24h`, `delta_24h`, `min_label`, `max_label`, `history_empty`, `celsius_unit`
- [x] 6.2 Populate `EN`: `"Outdoor 24h"`, `"Indoor 24h"`, `"Gain 24h"`, `"Min"`, `"Max"`, `"Collecting..."`, `"C"`
- [x] 6.3 Populate `DE`: `"Außen 24h"` (escaped), `"Innen 24h"`, `"Gewinn 24h"`, `"Min"`, `"Max"`, `"Sammle..."`, `"C"`

## 7. Display — chart rendering helper

- [x] 7.1 Add a private `fn draw_temp_chart(d, channel: &history::Channel, lang: Strings, empty_hint: &str)` in `src/display.rs`
- [x] 7.2 Inside the helper: call `channel.min_max()`; if `None`, render `empty_hint` centred in the chart area (y=24..56) and `--   --` for the min/max strip at y=12
- [x] 7.3 If `Some((lo, hi))`: render the numeric strip `"Min {lo:.1} C   Max {hi:.1} C"` at y=12 (small font, centred), then compute a stable y-scale:
  - `range = (hi - lo).max(0.5)`
  - `pad = (range - (hi - lo)) / 2.0`
  - effective `[lo - pad, hi + pad]` maps to `y = 56..24`
- [x] 7.4 For each `i in 0..128` of the channel's slots: read `Channel::slot_at_column(i)` (helper that returns `slots[(head + i) % HISTORY_SLOTS]`, so column 0 is oldest and column 127 is newest). If `Some(b)`, draw `Line::new(Point::new(i as i32, scale(b.max)), Point::new(i as i32, scale(b.min))).into_styled(PrimitiveStyle::with_stroke(BinaryColor::On, 1)).draw(d).ok();`
- [x] 7.5 Add `Channel::slot_at_column(&self, col: usize) -> Option<Bucket>` to history module

## 8. Display — per-page draw functions

- [x] 8.1 Add `fn draw_outdoor_history(d, st, lang)`: `draw_header(d, tr(lang).outdoor_24h)`, then `draw_temp_chart(d, &st.temp_history.outdoor, tr(lang), tr(lang).history_empty)`
- [x] 8.2 Add `fn draw_indoor_history` analogously, reading from `st.temp_history.indoor` with header `tr(lang).indoor_24h`
- [x] 8.3 Add `fn draw_delta_history` analogously, reading from `st.temp_history.delta` with header `tr(lang).delta_24h`. No special-case for "ID 81 unsupported" — the channel will simply be empty, so the empty-history hint already covers it

## 9. Verify

- [x] 9.1 `cargo check` passes (no feature flags) — verified with default `wifi,ot-ext,display-sh1106`
- [x] 9.2 `cargo check --features simulate-ot` passes — verified, the dev-mode preload path compiles
- [x] 9.3 Unit tests added in `history.rs` (fold, advance, min_max empty, min_max aggregate, slot_at_column ordering). Tests are compile-checked; they cannot be executed via `cargo test` on host because `esp-idf-sys` rejects non-ESP targets — same limitation as the existing `esp32/src/cwl_data.rs` tests
- [ ] 9.4 Build firmware (`cargo build --release`) and flash to a device; confirm: navigating past the existing `Intake` page reaches three new pages with the expected headers; chart starts empty with `Collecting...`; after running for >12 min the chart begins to populate columns; min/max strip updates on slot rollover *(requires hardware)*
- [ ] 9.5 Confirm no regressions on the existing 6 pages — dots indicator now shows 9 dots, navigation wraps correctly at boundaries, edit-mode pages (Home, Bypass, Settings) still work *(requires hardware)*

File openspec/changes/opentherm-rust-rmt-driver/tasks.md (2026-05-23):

## 1. New Rust driver — pure types and frame helpers

- [x] 1.1 Create `src/opentherm.rs` with `MessageType` and `ResponseStatus` enums (copy from `opentherm_ffi.rs`, keep identical variants and `#[repr(u8)]`)
- [x] 1.2 Add `build_request(msg_type: MessageType, data_id: u8, data: u16) -> u32` — pure function: place data at bits 15-0, data_id at bits 23-16, set bit 28 if WriteData, compute odd parity and set bit 31
- [x] 1.3 Add `get_message_type(frame: u32) -> MessageType` — extract bits 30-28
- [x] 1.4 Add `odd_parity(frame: u32) -> bool` helper (count 1-bits, return true if odd)

## 2. RMT TX — frame encoding

- [x] 2.1 Add `encode_frame(frame: u32) -> [rmt_symbol_word_t; 35]` — 34 symbols (start + 32 data MSB-first + stop) plus one zero end-marker; bit 1 = `{500, LOW, 500, HIGH}`, bit 0 = `{500, HIGH, 500, LOW}`
- [x] 2.2 Initialize RMT TX channel in `OpenTherm::new`: `rmt_new_tx_channel` with `gpio_num = out_pin`, `clk_src = RMT_CLK_SRC_APB`, `resolution_hz = 1_000_000` (1 µs/tick), idle level HIGH, mem_block_symbols ≥ 35
- [x] 2.3 Create `rmt_copy_encoder` for TX (no modulation needed — raw symbols only)
- [x] 2.4 Enable the TX channel with `rmt_enable`

## 3. RMT RX — frame capture

- [x] 3.1 Initialize RMT RX channel in `OpenTherm::new`: `rmt_new_rx_channel` with `gpio_num = in_pin`, `clk_src = RMT_CLK_SRC_APB`, `resolution_hz = 1_000_000`, `signal_range_min_ns = 1_000`, `signal_range_max_ns = 1_500_000`, mem_block_symbols ≥ 128
- [x] 3.2 Register `rmt_rx_event_callbacks` with an `on_recv_done` callback that gives a FreeRTOS semaphore (allocated in `OpenTherm::new`)
- [x] 3.3 Enable the RX channel with `rmt_enable`
- [x] 3.4 Allocate a receive buffer `[rmt_symbol_word_t; 128]` owned by the `OpenTherm` struct

## 4. Half-bit decoder

- [x] 4.1 Add `decode_symbols(items: &[rmt_symbol_word_t]) -> Result<u32, ()>` following the half-bit expansion algorithm from the design:
  - Expand each symbol's two half-slots into the `half_bits` vec, doubling a slot if its duration > 750
  - Return `Err(())` if `half_bits.len() != 68`
  - Decode 34 pairs: `(LOW, HIGH)` → 1, `(HIGH, LOW)` → 0, else `Err(())`
  - Skip pair 0 (start bit) and pair 33 (stop bit)
  - Reconstruct u32 from pairs 1–32
  - Return `Err(())` if `odd_parity(result)` is false (parity bit included)

## 5. Blocking send_request

- [x] 5.1 Implement `send_request(&self, request: u32) -> u32`:
  1. Call `encode_frame(request)` to get TX symbols
  2. Call `rmt_receive` to arm RX (do this BEFORE transmitting so no leading edge is missed)
  3. Call `rmt_transmit` with the encoded symbols
  4. Block on the FreeRTOS semaphore with `xSemaphoreTake(sem, 1100 ms ticks)`
  5. If semaphore times out: set `last_status = ResponseStatus::Timeout`, sleep 100 ms, return 0
  6. Call `decode_symbols` on the receive buffer
  7. On `Err`: set `last_status = ResponseStatus::Invalid`, sleep 100 ms, return 0
  8. On `Ok(frame)`: set `last_status = ResponseStatus::Success`, sleep 100 ms, return frame
- [x] 5.2 Store `last_status` in the struct (use `Cell<ResponseStatus>` or a Mutex since the struct is used from a single thread)
- [x] 5.3 Implement `last_status(&self) -> ResponseStatus` to return the stored value

## 6. Simulate-OT feature

- [x] 6.1 Gate the entire `OpenTherm` struct body (RMT fields) behind `#[cfg(not(feature = "simulate-ot"))]`
- [x] 6.2 Add a `#[cfg(feature = "simulate-ot")]` `OpenTherm` stub that keeps `cargo check --features simulate-ot` clean. (Scope note: moving the full simulation logic into `opentherm.rs` would be a larger refactor — kept the existing `ot_master::simulate()` path as-is; the stub exists only so the import resolves.)

## 7. Wire up the new module

- [x] 7.1 In `src/main.rs` (or wherever `opentherm_ffi` is declared as a module): replace `mod opentherm_ffi;` with `mod opentherm;`
- [x] 7.2 In `src/ot_master.rs`: change `use crate::opentherm_ffi::` imports to `use crate::opentherm::`
- [x] 7.3 Verify that `OpenTherm::new`, `send_request`, `last_status`, `build_request`, `get_message_type` all resolve correctly

## 8. Remove C++ component and build machinery

- [x] 8.1 Delete `src/opentherm_ffi.rs`
- [x] 8.2 Delete `components/opentherm/` directory (OpenTherm.cpp, OpenTherm.h, opentherm_ffi.cpp, opentherm_ffi.h, Arduino.h, FunctionalInterrupt.h, CMakeLists.txt if present)
- [x] 8.3 In `build.rs`: delete the `compile_opentherm()` function and its call site; keep the WiFi credential forwarding section unchanged
- [x] 8.4 In `Cargo.toml`: remove `cc = "1"` from `[build-dependencies]`
- [x] 8.5 In `Cargo.toml` `[package.metadata.esp-idf-sys]`: confirm `extra_components = []` (the C++ component was not listed there anyway, but verify)

## 9. Verify

- [x] 9.1 `cargo check` passes (no feature flags) — confirms the new module compiles and types align
- [x] 9.2 `cargo check --features simulate-ot` passes — confirms simulate path still works
- [ ] 9.3 `cargo build --release` produces a firmware binary without linker errors *(not run — slow xtensa link; verify on real device)*
- [ ] 9.4 Flash firmware and confirm: OTA upload completes without visible lag, OpenTherm polling resumes normally after reboot, sensor data appears on MQTT within 30 s of boot *(requires hardware)*

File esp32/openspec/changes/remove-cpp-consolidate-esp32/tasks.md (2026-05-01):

## 1. Move web source into Rust project

- [x] 1.1 Run `git mv esp32/web esp32-rust/web` to move the web UI source into the Rust project
- [x] 1.2 Move `esp32/data` into `esp32-rust/data` if it contains build output that should be preserved (or create the dir)

## 2. Remove C++ project

- [x] 2.1 Run `git rm -r esp32/` to remove the legacy C++ PlatformIO project entirely

## 3. Rename esp32-rust to esp32

- [x] 3.1 Run `git mv esp32-rust esp32` to rename the Rust project to its final location

## 4. Update internal paths

- [x] 4.1 Update `Makefile` — change `WEB_SRC := ../esp32/web` to `WEB_SRC := web` and `WEB_OUT := ../esp32/data` to `WEB_OUT := data`
- [x] 4.2 Check and update root `.gitignore` for any `esp32-rust/` or `esp32/` path references
- [x] 4.3 Check and update root `README.md` if it references the old directory structure (no changes needed)
- [x] 4.4 Update `vite.config.ts` in web/ if it has output path references (already correct — `../data` relative to `web/`)

## 5. Verify

- [x] 5.1 Confirm the directory structure is correct: `esp32/` contains Cargo.toml, src/, web/, Makefile
- [x] 5.2 Run `cargo check` from the new `esp32/` directory
- [x] 5.3 Run `npm run build` from `esp32/web/` and confirm output goes to `esp32/data/`

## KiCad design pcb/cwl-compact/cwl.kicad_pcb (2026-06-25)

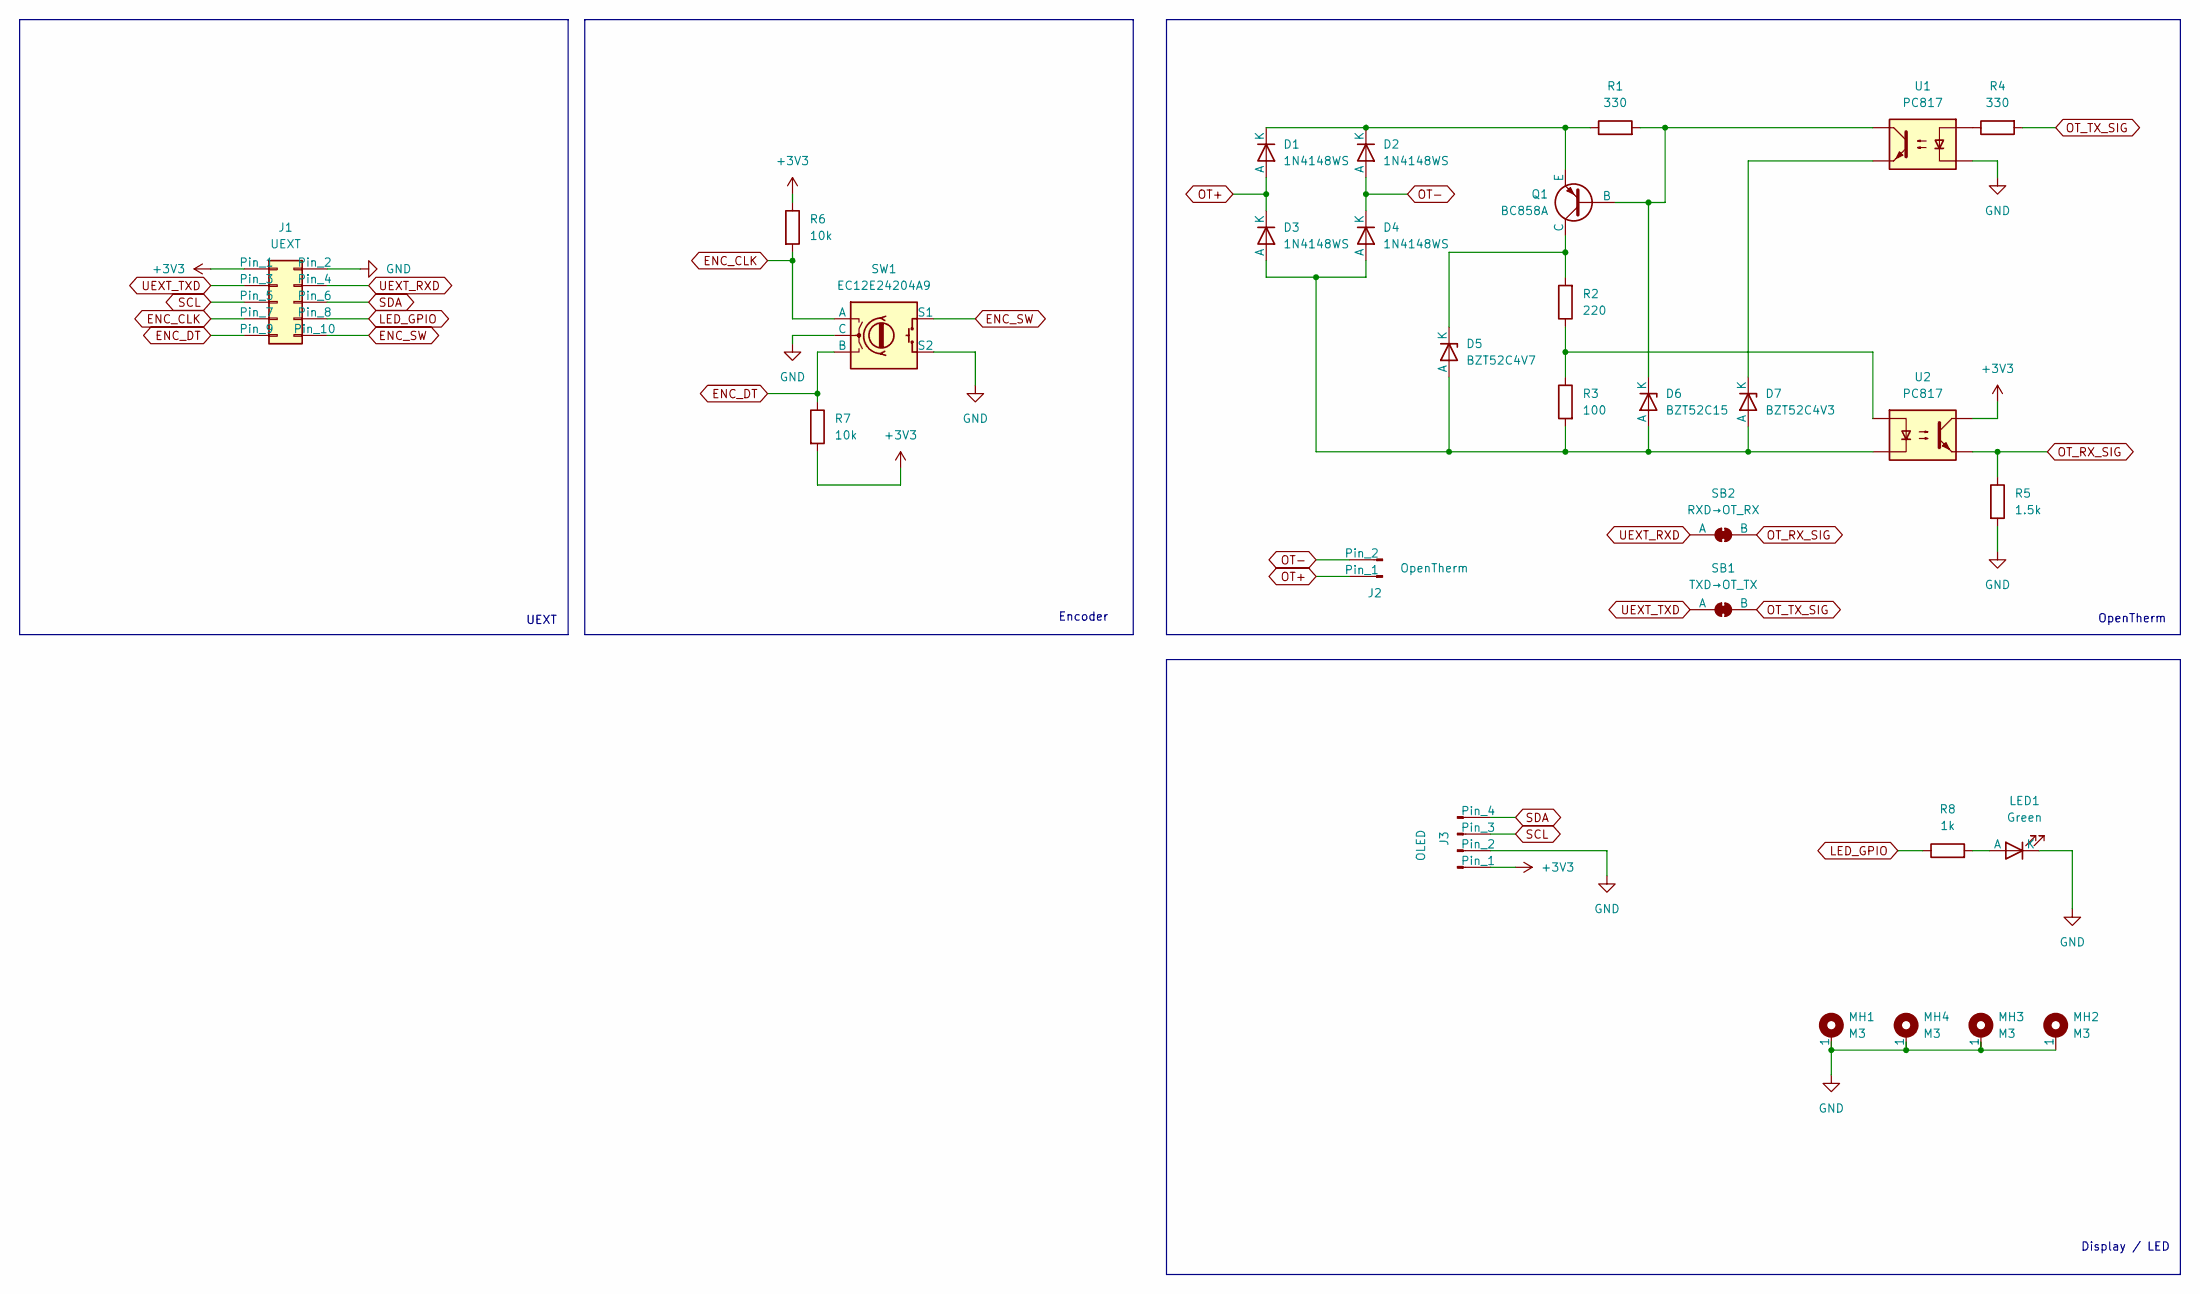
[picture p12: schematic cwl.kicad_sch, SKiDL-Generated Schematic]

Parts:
D1, D2, D3, D4: 1N4148WS; D_SOD-323
D5: BZT52C4V7; D_SOD-123
D6: BZT52C15; D_SOD-123
D7: BZT52C4V3; D_SOD-123
J1: UEXT; IDC-Stecker_2x05_P2.54mm_Vertical; LCSC C358738
J2: OpenTherm; TerminalBlock_Phoenix_MKDS-1,5-2-5.08_1x02_P5.08mm_Horizont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
J3: OLED; 128x64OLED-MountingHoles-Combined
LED1: Green; LED_0805_2012Metric; LCSC C2297
MH1, MH2, MH3, MH4: M3; MountingHole_3.2mm_M3_Pad_Via
Q1: BC858A; SOT-23
R1, R4: 330; R_0603_1608Metric; LCSC C23138
R2: 220; R_0603_1608Metric; LCSC C22962
R3: 100; R_0603_1608Metric; LCSC C22775
R5: 1.5k; R_0603_1608Metric; LCSC C22843
R6, R7: 10k; R_0603_1608Metric; LCSC C25804
R8: 1k; R_0603_1608Metric; LCSC C21190
SB1: TXD→OT_TX; SolderJumper-2_P1.3mm_Bridged_RoundedPad1.0x1.5mm
SB2: RXD→OT_RX; SolderJumper-2_P1.3mm_Bridged_RoundedPad1.0x1.5mm
SW1: EC12E24204A9; RotaryEncoder_Alps_EC12E-Switch_Vertical_H20mm
U1, U2: PC817; SOP-4_7.5x4.1mm_P2.54mm

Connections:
+3V3: J1.1, J3.1, R6.1, R7.2, U2.4
ENC_CLK: J1.7, R6.2, SW1.A
ENC_DT: J1.9, R7.1, SW1.B
ENC_SW: J1.10, SW1.S1
GND: J1.2, J3.2, LED1.1 (K), MH1.1 (1_1), MH2.1 (1_1), MH3.1 (1_1), MH4.1 (1_1), R5.2, SW1.C, SW1.MP, SW1.S2, U1.2
LED_GPIO: J1.8, R8.1
unnamed: D1.1 (K), D2.1 (K), Q1.2 (E), R1.1
unnamed: D3.2 (A), D4.2 (A), D5.2 (A), D6.2 (A), D7.2 (A), R3.2, U2.2
unnamed: D5.1 (K), Q1.3 (C), R2.2
unnamed: D6.1 (K), Q1.1 (B), R1.2, U1.4
unnamed: D7.1 (K), U1.3
unnamed: LED1.2 (A), R8.2
unnamed: R2.1, R3.1, U2.1
unnamed: R4.1, U1.1
OT+: D1.2 (A), D3.1 (K), J2.1
OT-: D2.2 (A), D4.1 (K), J2.2
OT_RX_SIG: R5.1, SB2.2 (B), U2.3
OT_TX_SIG: R4.2, SB1.2 (B)
SCL: J1.5, J3.3
SDA: J1.6, J3.4
UEXT_RXD: J1.4, SB2.1 (A)
UEXT_TXD: J1.3, SB1.1 (A)

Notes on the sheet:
UEXT
OpenTherm
Display / LED
Encoder

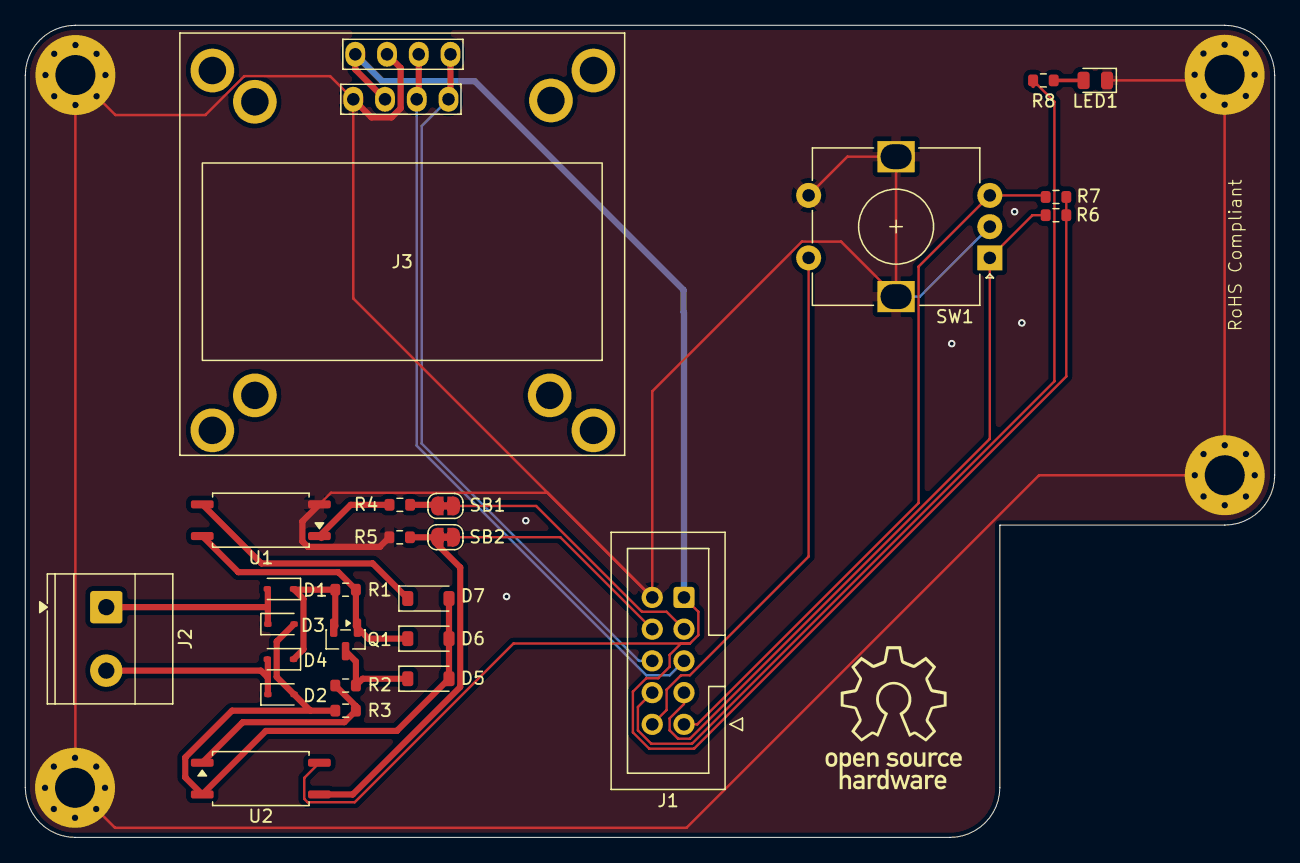
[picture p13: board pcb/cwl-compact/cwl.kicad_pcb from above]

Board: 2 copper layers, 100.0 x 65.0 mm, 29 parts (0 on the bottom side), 22 nets.

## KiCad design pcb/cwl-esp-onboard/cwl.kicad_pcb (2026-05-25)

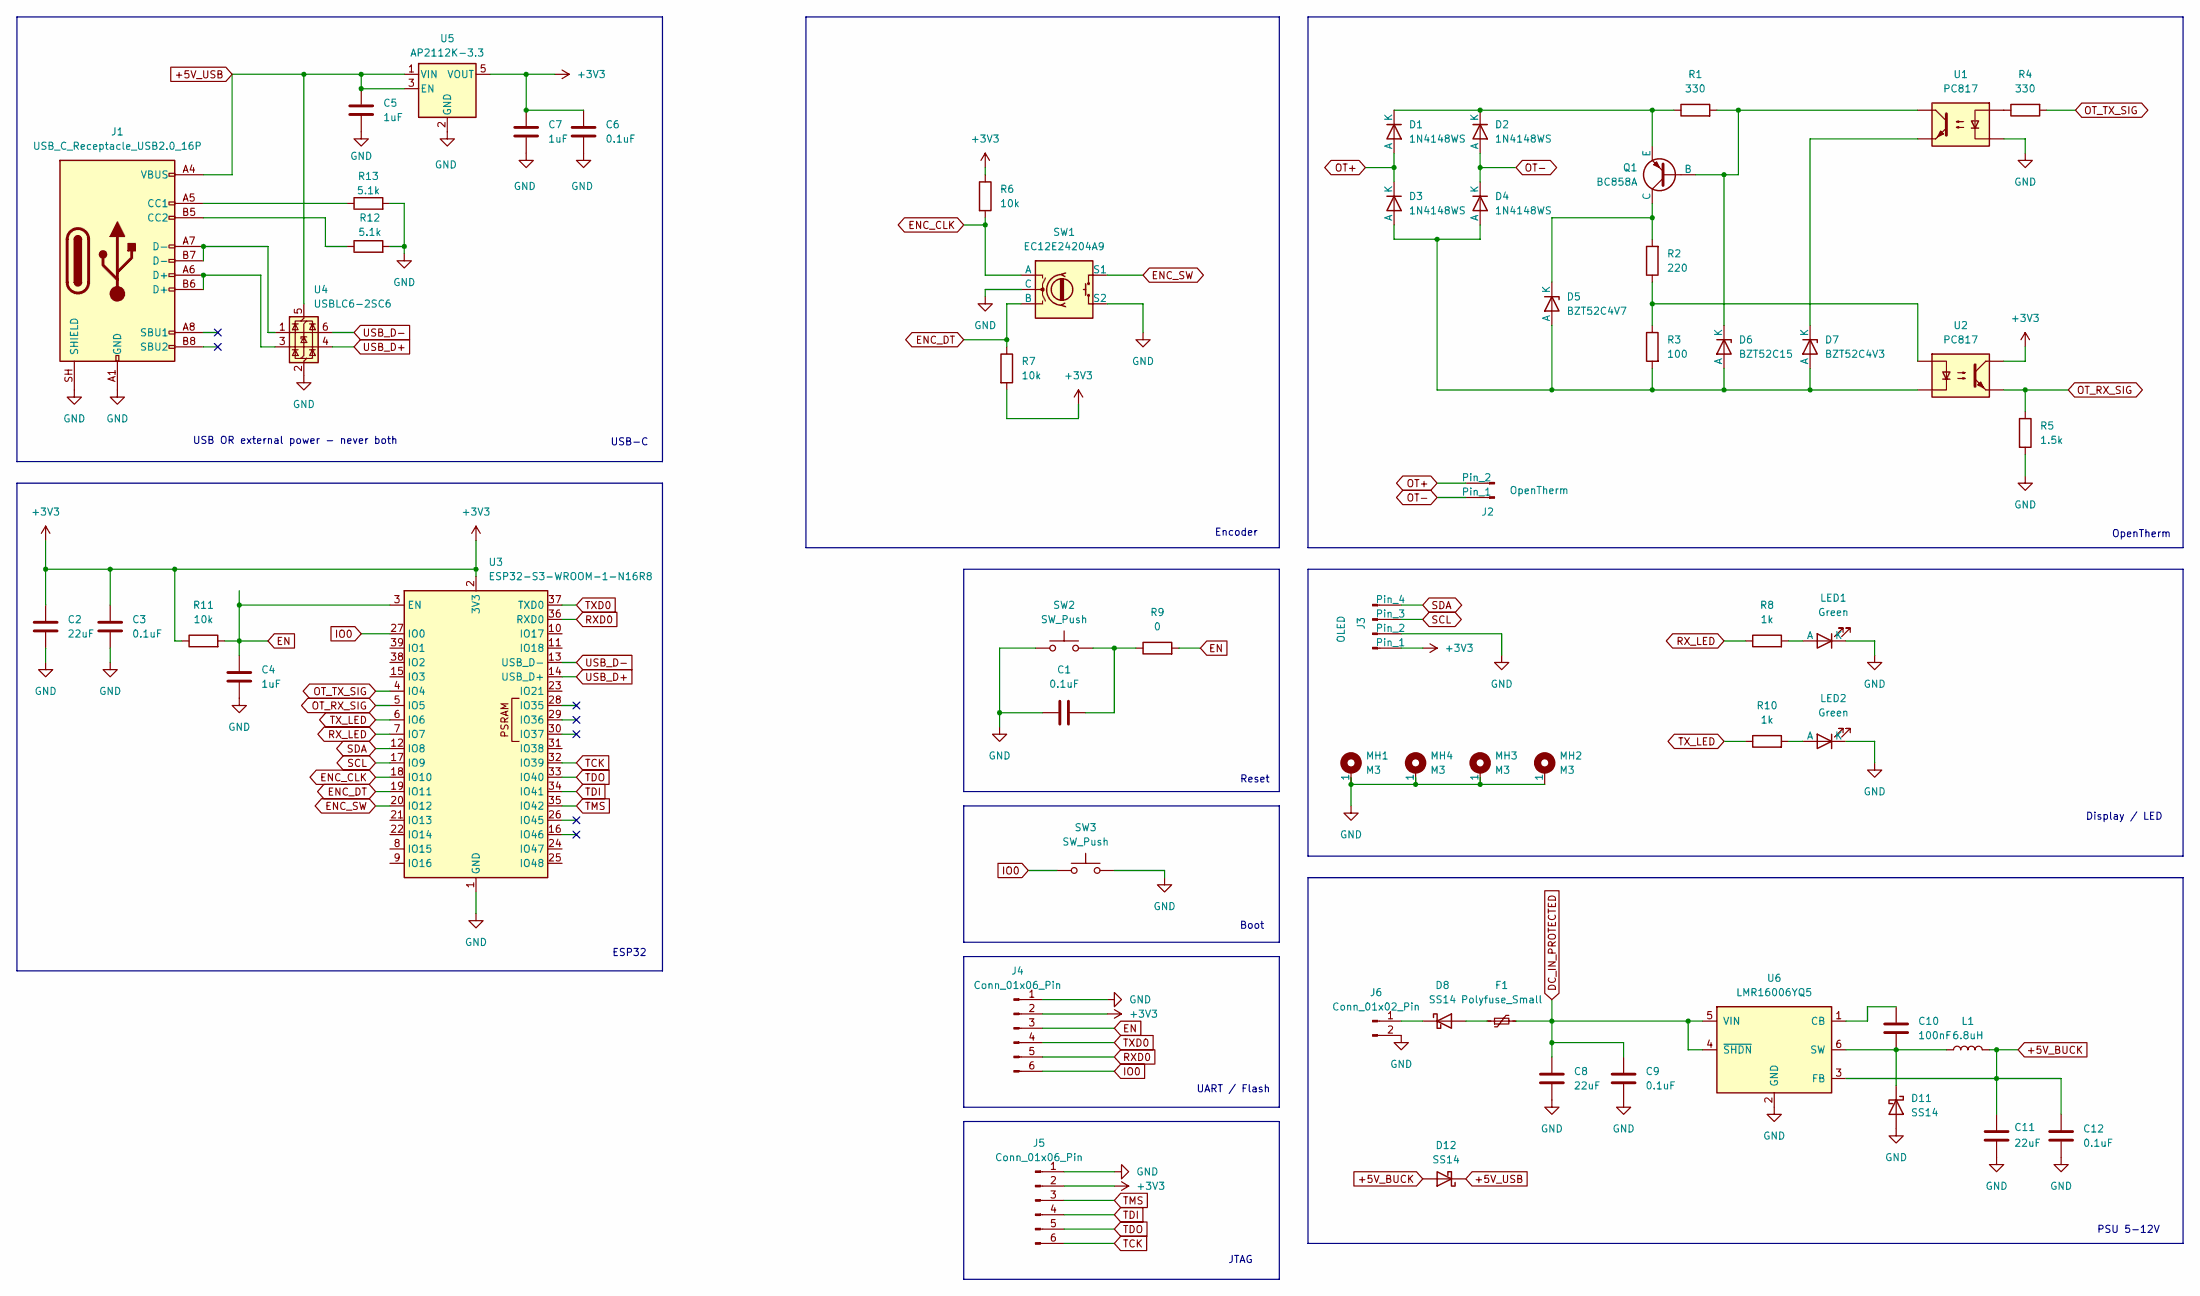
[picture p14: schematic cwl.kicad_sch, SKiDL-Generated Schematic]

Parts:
C1, C3, C6, C9, C12: 0.1uF; C_0402_1005Metric
C2, C8, C11: 22uF; C_1210_3225Metric
C4, C5, C7: 1uF; C_0402_1005Metric
C10: 100nF; C_0402_1005Metric
D1, D2, D3, D4: 1N4148WS; D_SOD-323
D5: BZT52C4V7; D_SOD-123
D6: BZT52C15; D_SOD-123
D7: BZT52C4V3; D_SOD-123
D8, D11, D12: SS14; D_SMA
F1: Polyfuse_Small; Fuse_1812_4532Metric
J1: USB_C_Receptacle_USB2.0_16P; USB_C_Receptacle_HRO_TYPE-C-31-M-12
J2: OpenTherm; TerminalBlock_Phoenix_MKDS-1,5-2-5.08_1x02_P5.08mm_Horizont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
J3: OLED; 128x64OLED-MountingHoles-Combined
J4: Conn_01x06_Pin; PinHeader_1x06_P2.54mm_Vertical
J5: Conn_01x06_Pin; PinHeader_1x06_P1.27mm_Vertical_SMD_Pin1Left
J6: Conn_01x02_Pin; TerminalBlock_Phoenix_MKDS-1,5-2-5.08_1x02_P5.08mm_Horizont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
L1: 6.8uH; L_6.3x6.3_H3
LED1, LED2: Green; LED_0805_2012Metric
MH1, MH2, MH3, MH4: M3; MountingHole_3.2mm_M3_Pad_Via
Q1: BC858A; SOT-23
R1, R4: 330; R_0603_1608Metric
R2: 220; R_0603_1608Metric
R3: 100; R_0603_1608Metric
R5: 1.5k; R_0603_1608Metric
R6, R7: 10k; R_0603_1608Metric
R8, R10: 1k; R_0603_1608Metric
R9: 0; R_0402_1005Metric
R11: 10k; R_0402_1005Metric
R12, R13: 5.1k; R_0402_1005Metric
SW1: EC12E24204A9; RotaryEncoder_Alps_EC12E-Switch_Vertical_H20mm
SW2, SW3: SW_Push; SW_SPST_TL3342
U1, U2: PC817; SOP-4_7.5x4.1mm_P2.54mm
U3: ESP32-S3-WROOM-1-N16R8; ESP32-S3-WROOM-1
U4: USBLC6-2SC6; SOT-23-6
U5: AP2112K-3.3; SOT-23-5
U6: LMR16006YQ5; SOT-23-6

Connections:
+3V3: C2.1, C3.1, C6.1, C7.1, J3.1, J4.2, J5.2, R6.1, R7.2, R11.1, U2.4, U3.2 (3V3), U5.5 (VOUT); also elsewhere on the board
+5V_BUCK: C11.1, C12.1, D12.2 (A), L1.2, U6.3 (FB)
+5V_USB: C5.1, D12.1 (K), J1.A4 (VBUS), J1.A9 (VBUS), J1.B4 (VBUS), J1.B9 (VBUS), U4.5 (VBUS), U5.1 (VIN), U5.3 (EN)
EN: C4.2, J4.3, R9.2, R11.2, U3.3 (EN)
ENC_CLK: R6.2, SW1.A, U3.18 (IO10); also elsewhere on the board
ENC_DT: R7.1, SW1.B, U3.19 (IO11); also elsewhere on the board
ENC_SW: SW1.S1, U3.20 (IO12); also elsewhere on the board
IO0: J4.6, SW3.1, U3.27 (IO0)
unnamed: C1.2, R9.1, SW2.2
unnamed: D1.1 (K), D2.1 (K), Q1.2 (E), R1.1
unnamed: D3.2 (A), D4.2 (A), D5.2 (A), D6.2 (A), D7.2 (A), R3.2, U2.2
unnamed: D5.1 (K), Q1.3 (C), R2.2
unnamed: D6.1 (K), Q1.1 (B), R1.2, U1.4
unnamed: D7.1 (K), U1.3
unnamed: D8.2 (A), F1.1
unnamed: D8.1 (K), J6.1
unnamed: J1.A5 (CC1), R13.1
unnamed: J1.B5 (CC2), R12.1
unnamed: J1.A6 (D+), J1.B6 (D+), U4.3 (I/O2)
unnamed: J1.A7 (D-), J1.B7 (D-), U4.1 (I/O1)
unnamed: LED1.2 (A), R8.2
unnamed: LED2.2 (A), R10.2
unnamed: R2.1, R3.1, U2.1
unnamed: R4.1, U1.1
OT+: D1.2 (A), D3.1 (K), J2.2
OT-: D2.2 (A), D4.1 (K), J2.1
OT_RX_SIG: R5.1, U2.3, U3.5 (IO5); also elsewhere on the board
OT_TX_SIG: R4.2, U3.4 (IO4); also elsewhere on the board
RXD0: J4.5, U3.36 (RXD0)
RX_LED: R8.1, U3.7 (IO7)
SCL: J3.3, U3.17 (IO9); also elsewhere on the board
SDA: J3.4, U3.12 (IO8); also elsewhere on the board
TCK: J5.6, U3.32 (IO39)
TDI: J5.4, U3.34 (IO41)
TDO: J5.5, U3.33 (IO40)
TMS: J5.3, U3.35 (IO42)
TXD0: J4.4, U3.37 (TXD0)
TX_LED: R10.1, U3.6 (IO6)
USB_D+: U3.14 (USB_D+), U4.4 (I/O2)
USB_D-: U3.13 (USB_D-), U4.6 (I/O1)

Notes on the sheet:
Boot
USB-C
Reset
PSU 5-12V
OpenTherm
UART / Flash
ESP32
JTAG
Display / LED
Encoder
USB OR external power - never both

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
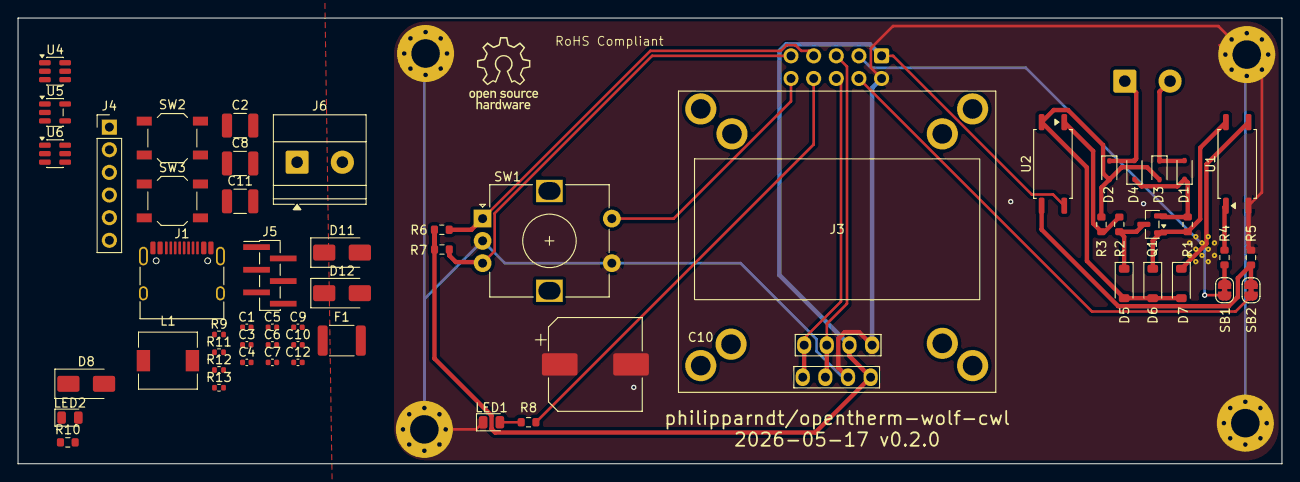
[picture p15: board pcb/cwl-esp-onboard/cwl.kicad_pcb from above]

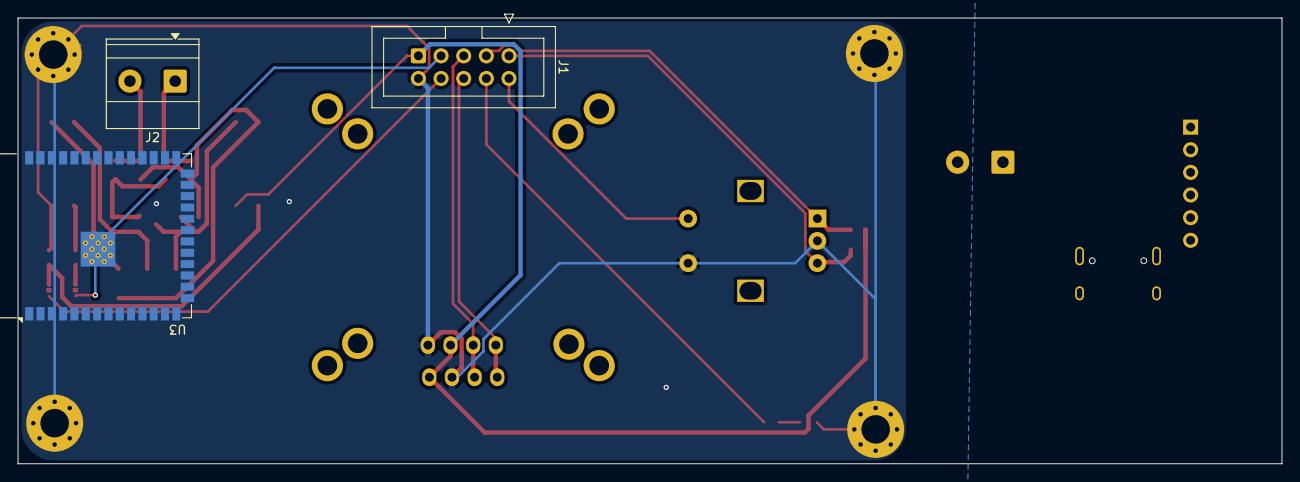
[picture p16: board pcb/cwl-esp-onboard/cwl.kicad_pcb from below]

Board: 2 copper layers, 141.8 x 50.0 mm, 63 parts (3 on the bottom side), 46 nets.

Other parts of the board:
C10#2: 100nF; C_0402_1005Metric
J1#2: UEXT; IDC-Stecker_2x05_P2.54mm_Vertical
SB1: TXD→OT_TX; SolderJumper-2_P1.3mm_Bridged_RoundedPad1.0x1.5mm
SB2: RXD→OT_RX; SolderJumper-2_P1.3mm_Bridged_RoundedPad1.0x1.5mm

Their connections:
+3V3: J1#2.1; also elsewhere on the board
ENC_CLK: J1#2.7; also elsewhere on the board
ENC_DT: J1#2.9; also elsewhere on the board
ENC_SW: J1#2.10; also elsewhere on the board
OT_RX_SIG: SB2.2 (B); also elsewhere on the board
OT_TX_SIG: SB1.2 (B); also elsewhere on the board
SCL: J1#2.5; also elsewhere on the board
SDA: J1#2.6; also elsewhere on the board
UEXT_RXD: J1#2.4, SB2.1 (A)
UEXT_TXD: J1#2.3, SB1.1 (A)

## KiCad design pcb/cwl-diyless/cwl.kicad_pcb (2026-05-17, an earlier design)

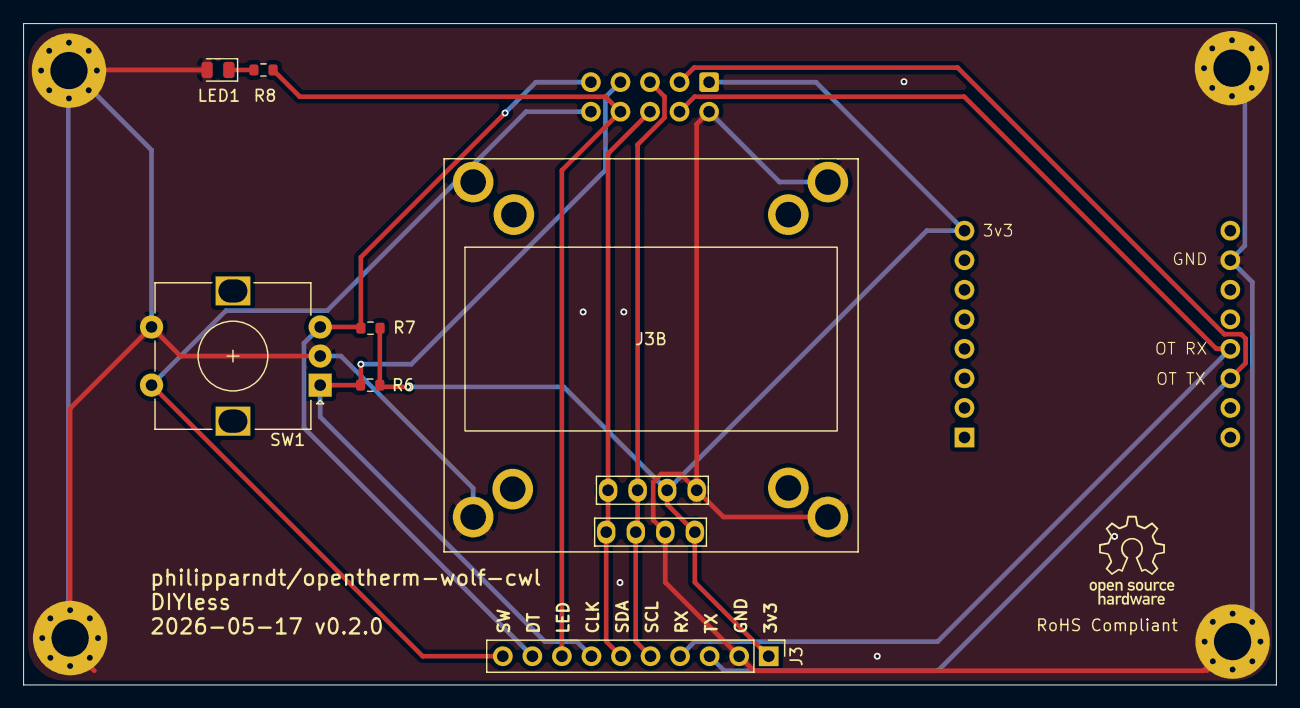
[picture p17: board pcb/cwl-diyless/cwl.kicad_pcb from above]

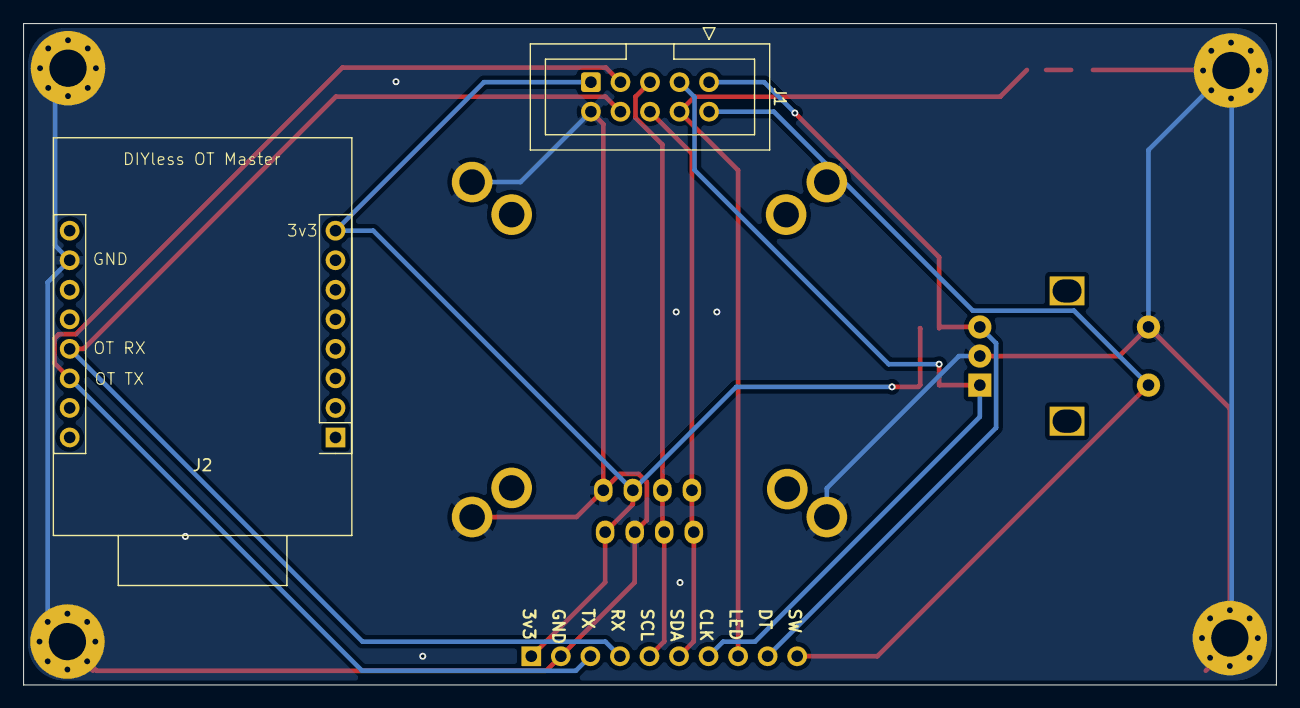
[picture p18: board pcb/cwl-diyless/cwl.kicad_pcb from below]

Board: 2 copper layers, 107.7 x 56.9 mm, 13 parts (2 on the bottom side), 11 nets.

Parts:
J1: UEXT; IDC-Stecker_2x05_P2.54mm_Vertical
J2: D1mini; D1_Mini_2x08_P2.54mm
J3: UEXT_DBG; PinHeader_1x10_P2.54mm_Vertical
J3B: OLED_1.3; 128x64OLED-MountingHoles-Combined
LED1: Green; LED_0805_2012Metric
MH1, MH2, MH3, MH4: M3; MountingHole_3.2mm_M3_Pad_Via
R6, R7: 10k; R_0603_1608Metric
R8: 1k; R_0603_1608Metric
SW1: EC12E24204A9; RotaryEncoder_Alps_EC12E-Switch_Vertical_H20mm

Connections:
+3V3: J1.1, J2.8, J3.1, J3B.1, R6.2, R7.2
ENC_CLK: J1.7, J3.7, R6.1, SW1.A
ENC_DT: J1.9, J3.9, R7.1, SW1.B
ENC_SW: J1.10, J3.10, SW1.S1
GND: J1.2, J2.15, J3.2, J3B.2, LED1.2, MH1.1, MH2.1, MH3.1, MH4.1, SW1.C, SW1.S2
LED_ANODE: LED1.1, R8.2
LED_GPIO: J1.8, J3.8, R8.1
OT_RX_SIG: J1.4, J2.12, J3.4
OT_TX_SIG: J1.3, J2.11, J3.3
SCL: J1.5, J3.5, J3B.3
SDA: J1.6, J3.6, J3B.4

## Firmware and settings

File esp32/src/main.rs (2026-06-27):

mod app_state;
mod config;
mod config_manager;
mod cwl_data;
mod display;
mod encoder;
mod extreme_heat;
mod framebuffer;
mod history;
mod humidity;
pub mod i18n;
mod mqtt;
mod network;
mod opentherm;
mod ot_master;
mod panic_capture;
mod psychro;
mod scheduler;
mod sensor_filter;
mod status_led;
mod watchdog;
mod webserver;

use esp_idf_svc::hal::delay::FreeRtos;
use esp_idf_svc::hal::i2c::{I2cConfig, I2cDriver};
use esp_idf_svc::hal::peripherals::Peripherals;
use esp_idf_svc::hal::prelude::*;
use esp_idf_svc::eventloop::EspSystemEventLoop;
use esp_idf_svc::nvs::EspDefaultNvsPartition;
use log::info;
use std::sync::Arc;
use std::sync::atomic::{AtomicBool, Ordering};

/// Consume any pending encoder events, applying each to the display and
/// rendering between events so a fast spin shows every page. Called both
/// from the body of the main loop and from inside the sleep window so
/// rotation feels responsive without changing the main-loop cadence for
/// the rest of the work.
fn drain_encoder(
    enc: &mut Option<encoder::Encoder>,
    disp: &mut display::Display,
    now_ms: u32,
) {
    let Some(enc) = enc.as_mut() else { return };
    let start_us = unsafe { esp_idf_svc::sys::esp_timer_get_time() };
    let mut count = 0u32;
    while let Some(event) = enc.poll(now_ms) {
        match event {
            encoder::EncoderEvent::Rotate(delta) => {
                if !disp.wake() {
                    if disp.edit_mode {
                        disp.adjust_edit_value(delta);
                    } else if delta > 0 {
                        disp.next_page();
                    } else {
                        disp.prev_page();
                    }
                }
            }
            encoder::EncoderEvent::Press => {
                if !disp.wake() {
                    if disp.edit_mode {
                        disp.exit_edit_mode(true); // apply
                    } else {
                        disp.enter_edit_mode();
                    }
                }
            }
        }
        disp.update(now_ms);
        count += 1;
    }
    if count > 0 {
        let total_us = unsafe { esp_idf_svc::sys::esp_timer_get_time() } - start_us;
        info!("DRAIN events={} total={}us", count, total_us);
    }
}

fn main() {
    esp_idf_svc::log::EspLogger::initialize_default();

    // Capture future panics (message + file:line) across the reboot they cause,
    // then surface any panic from the previous run.
    panic_capture::install_hook();
    if let Some(p) = panic_capture::load() {
        log::error!("Recovered from previous panic: {p}");
    }

    info!("Wolf CWL - Rust Firmware");
    info!("Initializing...");

    let peripherals = Peripherals::take().unwrap();
    let sysloop = EspSystemEventLoop::take().unwrap();
    let nvs_partition = EspDefaultNvsPartition::take().unwrap();

    // Status LED
    let mut led = status_led::StatusLed::new(peripherals.pins.gpio2.into());

    // Wait for peripherals to stabilize after power-on (SH1106 needs ~100ms)
    FreeRtos::delay_ms(200);

    // I2C for display
    // 1 MHz brings the OLED flush down from ~32 ms (400 kHz, spec default) to
    // ~13 ms — the dominant cost of disp.update(). SSD1306 and SH1106 panels
    // routinely tolerate this on short, well-pulled-up buses; if the panel
    // ever shimmers or shows corruption, back this off to 400/800 kHz.
    let i2c_config = I2cConfig::new().baudrate(1.MHz().into());
    let i2c = I2cDriver::new(
        peripherals.i2c0,
        peripherals.pins.gpio13, // SDA
        peripherals.pins.gpio16, // SCL
        &i2c_config,
    ).unwrap();

    // Load config from NVS
    let config_mgr = config_manager::ConfigManager::new(nvs_partition.clone()).unwrap();
    let config = config_mgr.load();
    info!("Config loaded (configured={})", config.configured);

    // OT GPIO selection:
    //   ot-uext: uses UEXT TXD(GPIO1)/RXD(GPIO3) — default, matches SB3+SB4 closed
    //   ot-ext:  uses GPIO4/GPIO36 via J4 — fallback, matches SB1+SB2 closed
    #[cfg(feature = "ot-uext")]
    let (ot_in, ot_out) = {
        info!("OpenTherm: Using UEXT pins (GPIO3 RX, GPIO1 TX)");
        (3i32, 1i32)  // RXD=GPIO3 (OT input), TXD=GPIO1 (OT output)
    };
    #[cfg(feature = "ot-ext")]
    let (ot_in, ot_out) = {
        info!("OpenTherm: Using EXT pins (GPIO36 RX, GPIO4 TX)");
        (config.ot_in_pin as i32, config.ot_out_pin as i32)
    };
    #[cfg(not(any(feature = "ot-uext", feature = "ot-ext")))]
    let (ot_in, ot_out) = {
        info!("OpenTherm: Using config pins (GPIO{} RX, GPIO{} TX)", config.ot_in_pin, config.ot_out_pin);
        (config.ot_in_pin as i32, config.ot_out_pin as i32)
    };

    // Shared application state
    let state = app_state::new_app_state(config.clone());

    // Load schedules and timed-off state into shared state
    let restored_timed_off_end = config_mgr.load_timed_off_end();
    {
        let mut st = state.lock().unwrap();
        st.schedules = config_mgr.load_schedules();
        st.bypass_schedule = config_mgr.load_bypass_schedule();
        st.schedule_override = config_mgr.load_override_state();
        info!("Schedules: {} ventilation, bypass {}", st.schedules.len(),
              if st.bypass_schedule.enabled { "enabled" } else { "disabled" });
        if restored_timed_off_end > 0 {
            st.timed_off_end_epoch = restored_timed_off_end;
            info!("Timed off: restored end epoch {}", restored_timed_off_end);
        }
    }

    // Display + boot screen
    // Shared dirty flag — anything that mutates display-visible state (the
    // Display struct's own setters, plus background threads that touch
    // AppState) bumps it; Display::update() short-circuits when it's clear.
    let display_dirty: display::DisplayDirty = Arc::new(AtomicBool::new(true));
    let mut disp = display::Display::new(i2c, state.clone(), display_dirty.clone());
    disp.boot_screen();

    // Network setup — non-blocking. The driver starts in the background; the
    // main loop polls check_network_connected() and reacts (display, NTP)
    // when (and if) the link comes up. Without this, an unplugged cable
    // would block boot until wait_netif_up() times out.
    #[cfg(feature = "ethernet")]
    {
        match network::eth_impl::start_ethernet(
            peripherals.mac,
            peripherals.pins.gpio0,
            peripherals.pins.gpio12,
            peripherals.pins.gpio17,
            peripherals.pins.gpio18,
            peripherals.pins.gpio19,
            peripherals.pins.gpio21,
            peripherals.pins.gpio22,
            peripherals.pins.gpio23,
            peripherals.pins.gpio25,
            peripherals.pins.gpio26,
            peripherals.pins.gpio27,
            sysloop.clone(),
        ) {
            Ok(_) => info!("Network: ETH driver started (no link yet)"),
            Err(e) => info!("Network: ETH init failed ({}), continuing offline", e),
        }
    }

    #[cfg(all(feature = "wifi", not(feature = "ethernet")))]
    {
        use network::wifi_impl::WifiNetwork;
        // Fall back to credentials baked in at build time (from esp32/.env via
        // build.rs) when NVS is empty — lets a freshly-flashed device join the
        // network without going through the web setup first.
        const BUILD_WIFI_SSID: &str = env!("WIFI_SSID");
        const BUILD_WIFI_PASSWORD: &str = env!("WIFI_PASSWORD");
        let ssid = if !config.wifi_ssid.is_empty() { config.wifi_ssid.as_str() } else { BUILD_WIFI_SSID };
        let password = if !config.wifi_password.is_empty() { config.wifi_password.as_str() } else { BUILD_WIFI_PASSWORD };
        match WifiNetwork::new(peripherals.modem, sysloop.clone(), nvs_partition.clone()) {
            Ok(mut wifi) => {
                wifi.connect(ssid, password).ok();
                let connected = wifi.state.connected;
                if connected {
                    let mut st = state.lock().unwrap();
                    st.network_connected = connected;
                    st.ip_address = wifi.state.ip_address.clone();
                }
                info!("Network: WiFi connected={}, ip={}", connected,
                      wifi.state.ip_address.as_deref().unwrap_or("none"));
                std::mem::forget(wifi);
            }
            Err(e) => info!("Network: WiFi init failed ({}), continuing offline", e),
        }
    }

    // Mount SPIFFS filesystem for web UI
    {
        use esp_idf_svc::sys::*;
        let conf = esp_vfs_spiffs_conf_t {
            base_path: b"/www\0".as_ptr() as *const _,
            partition_label: b"spiffs\0".as_ptr() as *const _,
            max_files: 5,
            format_if_mount_failed: false,
        };
        let ret = unsafe { esp_vfs_spiffs_register(&conf) };
        if ret == ESP_OK {
            info!("SPIFFS: Mounted at /www");
        } else {
            info!("SPIFFS: Mount failed (err={}) — web UI not available", ret);
        }
    }

    // Encoder
    let mut enc = encoder::Encoder::new(
        peripherals.pins.gpio15.into(),
        peripherals.pins.gpio14.into(),
        peripherals.pins.gpio5.into(),
    ).ok();

    // MQTT also runs on its own thread — publish bursts (~25 topics over the
    // network) can take 50–200 ms and we don't want that anywhere near the
    // encoder/display path. Incoming-command callbacks fire on EspMqttClient's
    // internal event-loop thread, independently of this one.
    {
        let state = state.clone();
        std::thread::Builder::new()
            .name("mqtt".into())
            .stack_size(8192)
            .spawn(move || {
                let mut mqtt_mgr = match mqtt::MqttManager::new(state) {
                    Some(m) => m,
                    None => return, // disabled / not configured
                };
                mqtt_mgr.setup_subscriptions();
                loop {
                    let now_ms = unsafe { (esp_idf_svc::sys::esp_timer_get_time() / 1000) as u32 };
                    mqtt_mgr.update(now_ms);
                    FreeRtos::delay_ms(100);
                }
            })
            .expect("Failed to spawn MQTT thread");
    }

    // OpenTherm master
    // OpenTherm runs on its own thread so its blocking I/O (up to ~1 s per
    // request with a real, unresponsive slave) doesn't stall the main loop's
    // UI / encoder / display work.
    {
        let state = state.clone();
        let display_dirty = display_dirty.clone();
        std::thread::Builder::new()
            .name("ot".into())
            .stack_size(16384)
            .spawn(move || {
                let mut ot = ot_master::OtMaster::new(state, ot_in, ot_out)
                    .expect("Failed to init OpenTherm");
                loop {
                    let now_ms = unsafe { (esp_idf_svc::sys::esp_timer_get_time() / 1000) as u32 };
                    // update() returns true when it actually ran a poll step
                    // (~1 Hz). Only then might cwl_data have changed, so we
                    // only flip the dirty flag at that cadence.
                    if ot.update(now_ms) {
                        display_dirty.store(true, Ordering::Relaxed);
                    }
                    // ot.update() throttles itself to POLL_INTERVAL_MS (1 s).
                    // Sleep short enough that timed_off_request / vent level
                    // changes get serviced on the next tick.
                    FreeRtos::delay_ms(100);
                }
            })
            .expect("Failed to spawn OT thread");
    }

    // Scheduler
    let mut sched = scheduler::Scheduler::new(state.clone());
    {
        let st = state.lock().unwrap();
        sched.schedules = st.schedules.clone();
        sched.bypass_schedule = st.bypass_schedule.clone();
        // Restore timed-off from NVS (deferred NTP validation happens in scheduler.update())
        if restored_timed_off_end > 0 {
            sched.timed_off_active = true;
            sched.timed_off_end_epoch = restored_timed_off_end;
            // Set ventilation to off until NTP validates
            // (scheduler.update() will clear if expired)
        }
    }

    // Extreme-heat automatic mode — drives the ventilation level from the
    // supply-vs-exhaust temperature difference when enabled in config.
    let mut extreme_heat = extreme_heat::ExtremeHeat::new(state.clone());

    // Watchdog
    let mut wdt = watchdog::Watchdog::new();

    // Web server
    let _server = webserver::start_server(state.clone()).expect("Failed to start web server");

    info!("Setup complete, entering main loop");
    info!("Reboot reason: {}", watchdog::reboot_reason());

    let mut last_net_connected = state.lock().unwrap().network_connected;
    let mut last_net_check_ms: u32 = 0;
    const NET_CHECK_INTERVAL_MS: u32 = 2000;
    let mut ntp_initialized = false;

    // WiFi init blocks until connected, so by the time we enter the loop the
    // network is already up and the "disconnected → connected" edge that
    // normally triggers setup_ntp() never fires. Kick NTP off explicitly here
    // when we already have a link.
    if last_net_connected {
        ntp_initialized = true;
        network::setup_ntp();
        network::setup_mdns().ok();
    }

    // LED RX activity blink: invert the LED briefly when fresh slave activity
    // is observed (Success or Invalid framing — both bumped by ot_master).
    // Pulse spans several iterations of the 5 ms inner idle loop so a response
    // landing mid-window is still visible.
    let mut last_seen_rx_counter: u32 = 0;
    let mut rx_pulse_start_ms: u32 = 0;
    const RX_PULSE_MS: u32 = 300;

    // One-shot: record a "reboot" history marker once the clock is valid and any
    // retained markers have been restored (so it appends rather than being wiped).
    let mut reboot_marked = false;

    loop {
        let now_ms = unsafe { (esp_idf_svc::sys::esp_timer_get_time() / 1000) as u32 };

        // OpenTherm polling now runs on its own thread (spawned above).

        // Timed off requests from web/MQTT
        {
            let mut st = state.lock().unwrap();
            if let Some(minutes) = st.timed_off_request.take() {
                drop(st);
                sched.activate_timed_off(minutes);
            } else if st.cancel_timed_off {
                st.cancel_timed_off = false;
                drop(st);
                sched.cancel_timed_off();
            } else {
                drop(st);
            }
        }

        // Scheduler
        sched.update(now_ms);

        // Extreme-heat automatic mode (no-op unless enabled in config). Runs
        // after the scheduler, which suppresses its own ventilation level
        // changes while the mode owns requested_vent_level.
        extreme_heat.update(now_ms);

        // Persist timed-off state to NVS when changed
        {
            let mut st = state.lock().unwrap();
            if st.persist_timed_off {
                st.persist_timed_off = false;
                let end_epoch = st.timed_off_end_epoch;
                let override_active = st.schedule_override;
                drop(st);
                let mut mgr = config_manager::ConfigManager::new(nvs_partition.clone()).unwrap();
                mgr.save_timed_off_end(end_epoch).ok();
                mgr.save_override_state(override_active).ok();
            }
        }

        // Persist full config to NVS when requested (e.g. language change)
        {
            let mut st = state.lock().unwrap();
            if st.persist_config {
                st.persist_config = false;
                let config = st.config.clone();
                drop(st);
                let mut mgr = config_manager::ConfigManager::new(nvs_partition.clone()).unwrap();
                mgr.save(&config).ok();
            }
        }

        // Persist ventilation + bypass schedules to NVS when changed via the web UI
        {
            let mut st = state.lock().unwrap();
            if st.persist_schedules {
                st.persist_schedules = false;
                let schedules = st.schedules.clone();
                let bypass_schedule = st.bypass_schedule.clone();
                drop(st);
                let mut mgr = config_manager::ConfigManager::new(nvs_partition.clone()).unwrap();
                mgr.save_schedules(&schedules).ok();
                mgr.save_bypass_schedule(&bypass_schedule).ok();
            }
        }

        // MQTT publishing now runs on its own thread (spawned above).

        // Watchdog (LED state itself is driven from the 5 ms inner loop below
        // so RX pulses arriving mid-iteration are not missed).
        {
            let st = state.lock().unwrap();
            wdt.update(now_ms, st.cwl_data.last_response_ms, st.cwl_data.connected);
        }

        // Temperature history sampler — fold latest readings into 24 h
        // ring buffers. Mark the display dirty only when a bucket rolls
        // over (~once every 11 min) so we don't re-render the chart every
        // second.
        {
            let mut st = state.lock().unwrap();
            let st = &mut *st;
            let rolled = st.temp_history.sample(now_ms, &st.cwl_data);
            if rolled {
                display_dirty.store(true, Ordering::Relaxed);
                // Persist the rolled-over history to the broker (retained).
                st.mqtt_publish_history = true;
            }
            // Coarse humidity history: max fresh indoor RH + max fresh outdoor RH.
            let max_fresh_rh = |sensors: &std::collections::HashMap<String, app_state::HumiditySample>| {
                sensors.values()
                    .filter(|s| humidity::is_fresh(s.updated_ms, now_ms))
                    .filter_map(|s| s.humidity)
                    .fold(None, |acc: Option<f32>, h| Some(acc.map_or(h, |a| a.max(h))))
            };
            let indoor_rh = max_fresh_rh(&st.humidity_inside);
            let outdoor_rh = max_fresh_rh(&st.humidity_outside);
            // Specific enthalpy (kJ/kg) from the same aggregated decision inputs
            // shown on the status page; `None` on a side with no fresh sensor.
            let (indoor_h, outdoor_h) =
                match humidity::inputs(st, now_ms, st.cwl_data.exhaust_temp, st.cwl_data.supply_temp) {
                    Some(inp) => (Some(inp.indoor.h), Some(inp.outdoor.h)),
                    None => (None, None),
                };
            st.temp_history.sample_humidity(now_ms, indoor_rh, outdoor_rh, indoor_h, outdoor_h);
        }

        // Apply any RAM-only state recovered from retained MQTT snapshots. The
        // MQTT callback only stashes raw bytes; the heavier JSON parse happens
        // here on the main loop.
        //
        // Crucially, wait until the wall clock is valid (NTP synced): the history
        // snapshot re-bins each point by its epoch relative to "now", so restoring
        // against a 1970 clock maps every point out of range and silently drops
        // the whole history. MQTT often delivers the retained snapshot before NTP
        // finishes (notably on Ethernet), so we leave the bytes *pending* — not
        // taken — until the clock is good, then restore on a later iteration.
        {
            let now_epoch = unsafe { esp_idf_svc::sys::time(std::ptr::null_mut()) } as i64;
            if now_epoch >= 1_700_000_000 {
                let mut st = state.lock().unwrap();
                if let Some(bytes) = st.pending_history_json.take() {
                    let st = &mut *st;
                    if st.temp_history.restore_from_snapshot(&bytes, now_epoch) {
                        display_dirty.store(true, Ordering::Relaxed);
                        info!("MQTT recovery: temperature history restored");
                    }
                    // Restore bypass transitions for the timeline shading,
                    // independent of whether the temperature points restored.
                    let bypass = crate::history::parse_bypass_events(&bytes);
                    if !bypass.is_empty() {
                        st.bypass_events.clear();
                        for (epoch, open) in bypass {
                            st.bypass_events.push_back(crate::app_state::BypassEvent { epoch, open });
                        }
                    }
                }
                if let Some(bytes) = st.pending_extreme_heat_json.take() {
                    let st = &mut *st;
                    extreme_heat::restore_snapshot(st, &bytes);
                    info!("MQTT recovery: extreme-heat markers restored");
                }
                // Mark the reboot once, after any retained markers were restored
                // (restore replaces the event list, so this must come after it).
                if !reboot_marked {
                    reboot_marked = true;
                    let level = st.requested_vent_level;
                    st.push_history_marker_now(level, crate::app_state::Reason::Reboot);
                }
            }
        }
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

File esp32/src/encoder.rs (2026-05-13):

//! Rotary encoder input — interrupt-driven Gray-code transition counter.
//!
//! Each ISR computes the direction of one Gray-code edge from the previous
//! and current pin states (`+1` = CW, `-1` = CCW, `0` = no/illegal change)
//! via a `(prev, new)`-indexed lookup table. A signed counter accumulates;
//! reaching `±4` emits one clean step. Partial clicks (the encoder physically
//! advanced past the mid-point but the spring snapped back without closing
//! the cycle) are emitted by `poll()` after a ~100 ms quiescence window,
//! based on the peak counter value reached during the gesture. A 50 ms
//! reverse-suppress window swallows opposite-direction emits caused by
//! contact bounce-back right after a clean click.
//!
//! Compared to the previous Buxton state machine, this decoder does *not*
//! assume the encoder rests at any particular pinstate. That matters on
//! cheap mechanical encoders whose rest state varies across detents due
//! to rotor/contact misalignment — we observed a unit where one detent
//! routinely left the encoder physically stuck at pinstate `10` after a
//! click, which caused the state machine to mis-attribute the *next*
//! gesture's direction.
//!
//! NOTE: we deliberately bypass `PinDriver::subscribe`/`enable_interrupt`. The
//! esp-idf-hal ISR trampoline calls `gpio_intr_disable` after every fire (to
//! guard against IWDT triggers on level-triggered pins), which requires
//! re-arming from non-ISR context — fatal for an encoder, since edges between
//! disable and re-arm are lost. We register our own handler via the raw
//! ESP-IDF C API; edge-triggered interrupts then keep re-firing automatically.

use esp_idf_svc::hal::gpio::{
    enable_isr_service, AnyIOPin, Input, InterruptType, Pin, PinDriver, Pull,
};
use esp_idf_svc::sys::{
    esp, esp_timer_get_time, gpio_get_level, gpio_intr_enable, gpio_isr_handler_add,
};
use log::info;
use std::sync::atomic::{AtomicI8, AtomicI32, AtomicU8, AtomicU32, AtomicUsize, Ordering};

/// Flip to `true` to dump every raw CLK/DT transition from the ISR ring.
/// Useful when diagnosing a bouncy encoder but very noisy in normal use.
/// Per-emit `ENC rot EMIT` / `ENC press EMIT` lines are logged unconditionally.
const DEBUG: bool = false;
const DEBUG_RING_LEN: usize = 64;

/// No edges for this long → poll() considers a partial emit. Must be longer
/// than realistic intra-click intervals (a slow but normal click puts ~100–
/// 300 ms between adjacent Gray-code edges); too short and a slow click
/// trips the partial path twice — once mid-stroke and once at the end.
const QUIESCENT_MS: u32 = 500;

/// Peak |count| during a gesture must reach this to qualify for a partial
/// emit. 4 = a full click; 3 means the encoder physically advanced through
/// three of the four Gray-code edges (i.e. one edge short of completing).
/// We deliberately don't honour `2` ("just past the midpoint") because that
/// rounds slow clicks up by one too often.
const HALFWAY_THRESHOLD: i32 = 3;

/// Opposite-direction partial emits within this window of the previous
/// emit are dropped as contact bounce-back rather than a real reversal.
/// Long enough to cover both the bounce itself (~50–200 ms) and the
/// subsequent QUIESCENT_MS wait before poll() makes the partial-emit
/// decision (otherwise the suppress check expires too soon).
const REVERSE_SUPPRESS_MS: u32 = 500;


/// Direction of a single pinstate transition, indexed by `[prev][new]`
/// (each 0..=3 = `(CLK<<1) | DT`).  `+1` = one CW Gray-code edge,
/// `-1` = one CCW edge, `0` = unchanged or an "illegal" diagonal jump
/// (both bits flipped in one sample — happens occasionally with very
/// fast input or coalesced interrupts).
///
/// CW Gray-code cycle:  `11 → 01 → 00 → 10 → 11`
/// CCW Gray-code cycle: `11 → 10 → 00 → 01 → 11`
#[rustfmt::skip]
const TRANS_DIR: [[i8; 4]; 4] = [
    //                  new=00    new=01    new=10    new=11
    /* prev=00 */    [     0,       -1,        1,        0  ],
    /* prev=01 */    [     1,        0,        0,       -1  ],
    /* prev=10 */    [    -1,        0,        0,        1  ],
    /* prev=11 */    [     0,        1,       -1,        0  ],
];

#[derive(Debug, Clone, Copy)]
pub enum EncoderEvent {
    Rotate(i32),   // +1 = clockwise, -1 = counter-clockwise
    Press,
}

/// Shared between the GPIO ISR and the main thread. All ISR-mutated fields
/// are atomic; the gpio numbers are read-only after construction.
struct IsrState {
    // Pin levels at the previous ISR fire. Swapped atomically with the
    // current sample on each fire to compute the direction of one edge.
    last_pinstate: AtomicU8,

    // Signed net transition count since the last gesture reset.  `±4` is
    // one complete physical click and triggers a clean emit.
    count: AtomicI32,

    // Furthest CW (positive) and CCW (negative) values `count` reached
    // since the last reset.  Used by the quiescence-based partial emit
    // so that a click that *almost* completed (e.g. peak `+3` then back
    // to `0`) still registers as one step.
    max_cw_count: AtomicI32,
    min_ccw_count: AtomicI32,

    // Time of the most recent direction-bearing transition. `0` means
    // "no gesture in flight"; poll() uses (now - this) > QUIESCENT_MS
    // to decide a gesture is over.
    last_transition_ms: AtomicU32,

    // Queue of decoded steps drained by `poll()`.
    steps: AtomicI32,

    // Timestamp + direction of the most recent emit (clean or partial).
    // Drives the reverse-suppress window. `last_emit_dir`: 0 = none,
    // 1 = CW, -1 = CCW.
    last_emit_ms: AtomicU32,
    last_emit_dir: AtomicI8,

    clk_gpio: i32,
    dt_gpio: i32,

    // Diagnostic ring. The ISR is the sole writer (GPIO ISRs don't preempt
    // themselves); the main thread is the sole reader. Wrap-overruns are
    // detected via `head - tail > LEN` and reported as dropped entries.
    debug_buf: [AtomicU32; DEBUG_RING_LEN],
    debug_head: AtomicUsize,
    debug_tail: AtomicUsize,
}

pub struct Encoder {
    _clk: PinDriver<'static, AnyIOPin, Input>,
    _dt: PinDriver<'static, AnyIOPin, Input>,
    sw: PinDriver<'static, AnyIOPin, Input>,

    // Leaked so the ISR can hold a stable pointer for the program's lifetime.
    // Encoder is constructed once in main() and never dropped, so this is fine.
    isr: &'static IsrState,

    last_button: bool,
    button_down_since: Option<u32>,
    last_button_event_ms: u32,
    button_debounce_ms: u32,
}
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

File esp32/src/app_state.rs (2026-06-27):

//! Shared application state accessible from HTTP handlers and main loop.

use std::collections::{HashMap, VecDeque};
use std::sync::{Arc, Mutex};

use crate::config::AppConfig;
use crate::cwl_data::CwlData;
use crate::history::TempHistory;
use crate::scheduler::{ScheduleEntry, BypassSchedule};

/// Maximum number of extreme-heat level-change events retained for the web
/// graph markers. Covers more than the ~24 h history window even if the mode
/// changes level on every dwell boundary; oldest dropped when full.
pub const EH_EVENT_CAPACITY: usize = 64;

/// Why the ventilation mode settled on its current level — surfaced in the UI so
/// the (multi-factor) decision is legible, and attached to each change event.
#[derive(Debug, Clone, Copy, PartialEq, Eq, Default)]
pub enum Reason {
    #[default]
    TempDelta,        // supply-vs-exhaust temperature bands (fallback)
    CoolingAssist,    // outdoor air is lower-energy (enthalpy) → ventilate to cool
    Dehumidify,       // moisture protection: indoor too humid, outdoor drier
    MuggySuppression, // outdoor air is higher-energy (humid) → hold ventilation down
    Manual,           // user set the level (web / encoder / MQTT)
    Schedule,         // a ventilation schedule changed the level
    Reboot,           // device (re)started — a marker only, not a level decision
}

impl Reason {
    pub fn as_str(self) -> &'static str {
        match self {
            Reason::TempDelta => "temp",
            Reason::CoolingAssist => "cooling",
            Reason::Dehumidify => "dehumidify",
            Reason::MuggySuppression => "muggy",
            Reason::Manual => "manual",
            Reason::Schedule => "schedule",
            Reason::Reboot => "reboot",
        }
    }
    pub fn from_str(s: &str) -> Self {
        match s {
            "cooling" => Reason::CoolingAssist,
            "dehumidify" => Reason::Dehumidify,
            "muggy" => Reason::MuggySuppression,
            "manual" => Reason::Manual,
            "schedule" => Reason::Schedule,
            "reboot" => Reason::Reboot,
            _ => Reason::TempDelta,
        }
    }
}

/// Why the mode is *holding* the current level instead of switching to the one
/// it just decided — surfaced so the UI can tell a deliberate hold apart from a
/// stuck controller.
#[derive(Debug, Clone, Copy, PartialEq, Eq, Default)]
pub enum HoldReason {
    #[default]
    None,     // current level == decided level, nothing withheld
    Deadband, // held in the neutral energy band (hysteresis), bare rule would switch
    Dwell,    // a different level was decided but the 15-min dwell hasn't elapsed
}

impl HoldReason {
    pub fn as_str(self) -> &'static str {
        match self {
            HoldReason::None => "none",
            HoldReason::Deadband => "deadband",
            HoldReason::Dwell => "dwell",
        }
    }
}

/// A ventilation level change made by the mode, kept so the web UI can draw a
/// reason-annotated marker at the time it happened.
#[derive(Debug, Clone, Copy)]
pub struct EhEvent {
    pub epoch: i64,
    pub level: u8,
    pub reason: Reason,
}

/// Maximum retained bypass transitions. Bypass toggles only a handful of times
/// per day, so this covers far more than the ~24 h history window; oldest dropped
/// when full.
pub const BYPASS_EVENT_CAPACITY: usize = 64;

/// A bypass-damper state transition, kept so the timeline can shade its
/// background by when the bypass was open. `open` is the state the damper moved
/// *to* at `epoch`.
#[derive(Debug, Clone, Copy)]
pub struct BypassEvent {
    pub epoch: i64,
    pub open: bool,
}

/// Latest reading from one MQTT climate sensor. Each field is optional so a
/// sensor may report only humidity (a hygrometer), only temperature (an outdoor
/// thermometer), or both. At least one of `humidity`/`temperature` is present.
///
/// `humidity`/`temperature` are the *filtered* (trusted) values — see
/// [`crate::sensor_filter`]. The per-field filter state is carried in
/// `hum_filter`/`temp_filter` so the spike guard can compare each new reading
/// against this sensor's recent history.
#[derive(Debug, Clone, Copy)]
pub struct HumiditySample {
    pub humidity: Option<f32>,
    pub temperature: Option<f32>,
    pub pressure: Option<f32>,
    pub updated_ms: u32,
    pub hum_filter: crate::sensor_filter::FieldFilter,
    pub temp_filter: crate::sensor_filter::FieldFilter,
}
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

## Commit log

2026-04-28 feat: improve mode switching
2026-04-30 update display
    [IDC-Socket_2x05_P2.54mm_Vertical.step, OLED_SH1106_1.3inch.step, cwl-assembly.3mf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]
2026-05-01 generate gerber files
    [cwl.kicad_pcb]
2026-05-01 add printable idc connector
    [IDC-Socket_2x05_P2.54mm_Vertical.step, IDC-Socket_2x05_P2.54mm_Vertical_printable.step, OLED_SH1106_1.3inch.step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]
2026-05-13 chore: archive completed changes, add cwl-1.3 PCB variant
    - Archive completed OpenSpec changes under 2026-05-01:
    bypass-default, timed-off-cancel, home-header-mode,
    pending-mode-indicator, main-screen-schedule-indicator,
    rust-rewrite, ventilation-select-schedule-return
    - Add new cwl-1.3 PCB variant with KiCad project files
    - Add OLED SH1106 0.96" 3D model and large mounting-hole
    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
    [IDC-Socket_2x05_P2.54mm_Vertical.step, IDC-Socket_2x05_P2.54mm_Vertical_printable.step, OLED_SH1106_0.96inch.step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]
2026-05-13 add partitions
    [partitions.csv]
2026-05-17 manual schematic
    [.kicad_sch, .kicad_sch.kicad_sch, cwl-assembly-print.stl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]
2026-05-17 new pcb
    [IDC-Socket_2x05_P2.54mm_Vertical.step, IDC-Socket_2x05_P2.54mm_Vertical_printable.step, OLED_SH1106_0.96inch.step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]
2026-05-23 fix: connection stability
    Filter detection via OEM LO bit, off-timer overhaul
    CWL filter signal:
    - Decode filter status from Status ID 70 LO byte bit 5 (Wolf/Brink/
    Viessmann OEM extension), confirmed in FIL_CLEAN.sal — the spec
    HI bit 4 is never set on this hardware and the HI fault bit is
    permanently latched, so neither is usable as a service signal.
    - Keep HI bit 4 and OEM fault code 6 as secondary fallbacks.
    - Blink "Filter" in the level slot on the Home page when service is
    due (1 s on / 1 s off, edit-mode unaffected).
    - README rewritten to document the OEM LO byte and the unreliable
    HI fault/filter bits.
    Off-timer:
    - Replace u8 hours (1..99) with a discrete u16-minute tab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
    [app_state.rs, display.rs, main.rs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]
2026-05-23 add 3d case
    [back.scad, button.scad, cwl.kicad_pcb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]
2026-05-23 Squashed commit of the following:
    commit 481deb4d1ac36ea8330ec88192de51c7a3cb352c
    Author: Philipp Arndt <2f.mail@gmx.de>
    Date: Sat May 23 19:26:29 2026 +0200
    fix: ot rust driver
    commit bb2b8b5b12621ffa75fe9bfb667a38aa0396d298
    Author: Philipp Arndt <2f.mail@gmx.de>
    Date: Sat May 23 17:15:30 2026 +0200
    feat: rust ot driver
    [display.rs, main.rs, opentherm.rs]
2026-05-25 update pcbs
    [.kicad_sch, .kicad_sch.kicad_sch, cwl.kicad_pcb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]
2026-06-25 history page + tz
    [cwl.kicad_pcb, cwl.kicad_sch]
2026-06-25 feat: extreme heat mode
2026-06-25 feat: extreme heat humidity handling
2026-06-25 chore: clean up temperatures
2026-06-27 feat: actual vent level, boot-safe climate state, MQTT docs
    Show the unit's actual running level (derived from relative
    ventilation ID 77) instead of the commanded level (ID 71), since
    the two can differ. The status display and pending-spinner clear
    now track actualLevel; exposed as ventilation.actualLevel on
    /api/status via the new VentLevel::from_relative_pct (also reused
    for initial-level inference in ot_master).
    Boot robustness: don't fabricate an aggregated air state from an
    implausible inlet fallback temperature, and gate the derived
    humidity/enthalpy block on cwl_data.connected — removes the
    boot-transient indoor h glitch. Show a "waiting for the unit"
    notice while disconnected ins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
    [mqtt.rs, webserver.rs]
2026-06-27 case (interm)
    [front.scad]
2026-06-27 feat: add sensor plausibility check
    [front.scad, utils.scad]
2026-06-27 slim variant
    [front.scad]
2026-06-27 clean up
    [front.scad]
2026-07-05 fix: filter warning from ID 70 LO bit 5 only, not OEM fault code 6
    The ESP showed "filter needs check" while the CWL display showed no FIL.
    Live debugging (new /api/status debug block) showed the real filter bit
    (Status ID 70 LO bit 5, confirmed in FIL_CLEAN.sal) was clear; the alert
    came from the oem_fault_code == 6 fallback. The unit was reporting a
    diagnostic indication (LO bit 6) with OEM status code 6 — not the filter
    message, so the old FIL2 hypothesis mapped code 6 to the wrong meaning.
    - filter_dirty now derives from LO bit 5 alone; drop the OEM code 6
    fallback (OR term + latch in the ID 72 handler) and the HI bit 4
    source — the response HI byte is just an echo of our master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
    [webserver.rs]
2026-07-05 case: extract shared config, rework back plate
    Move the shared dimensions and the derived slim boundary from front.scad
    into case_config.scad, included by both parts so the back plate stays in
    sync with the front shell. Rewrite back.scad as a flat plate with a
    locating lip and per-part mounting-ear thickness; regenerate front.stl.
    [back.scad, case_config.scad, front.scad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]
2026-07-05 docs: add web UI temperature-history screenshot to README
2026-07-27 feat: make the web UI login optional
    Adds a "Require login" toggle under Settings -> Web UI, persisted in NVS
    as `web_auth`. With it off, `is_authenticated()` short-circuits and the
    UI plus the whole REST API are reachable without a cookie -- meant for a
    trusted LAN, where the prompt is only friction.
    The flag is read from the live config on every request, so the toggle
    applies immediately without a reboot. It defaults to on, so existing
    devices keep requiring a login after the update.
    `/api/login` accepts any credentials while auth is off, which keeps the
    `make ota*` targets (they log in first) working unchanged.
    Also fixes /api/ota/fs, which was the one handler without its own state
    clo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
    [config.rs, webserver.rs]
2026-07-27 feat(mqtt): publish change-only, add optimistic command state
    Three related changes to the MQTT layer.
    1. Change-only publishing. Every state topic went out on its interval
    regardless of content -- ~34 retained topics every 11 s plus 6 health
    topics every 60 s, a constant ~3.2 msg/s. `pub_state()` now caches the
    last payload per topic and only publishes on an actual change. Payloads
    are formatted before the compare, so the printed precision doubles as
    the deadband. A full unconditional republish runs every 15 min and on
    every broker reconnect (cache cleared), which restores the retained set
    if the broker restarted without persistence. Health interval 60 s ->
    300 s.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
    [mqtt.rs]
2026-10-18 feat(web): Home OS v2 design, German UI, dependency update (v0.3.0)
    - Restyle the web UI in the Home OS v2 design: tokens copied from
    home-portal, light/dark following the system, system font stack (no web
    fonts on the ESP32), sticky header with status line and tabs, 44px
    touch targets, safe areas.
    - German by default, English switchable (DE/EN in the header, stored in
    localStorage "home.lang"); all hard-coded English strings translated,
    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
2026-10-18 feat(web): Wall Display embed mode
    On the iPad wall panel (html[data-embed="wall-display"], set by the app or
    for the "WallDisplay/" user agent in index.html) the page is always dark and
    transparent over the panel's gradient: cards and dialogs in its translucent
    glass (--wd-* tokens with home-portal's fallback literals), figures, level
    picker, fields and buttons on its raised surface, hairline strokes, no
    shadows, the panel's accent, font and radii, 44pt controls, color-scheme
    dark. The level colours stay. Normal browsers are unchanged.
    Web UI only; on the device it needs `make ota-fs` followed by a firmware OTA
    (or a reboot) to mount the new SPIFFS image.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
2026-10-24 feat(web): build on @mqtt-home/ui v0.1.0 (tokens, embed mode, prepaint)
    The Home OS tokens and the Wall Display embed mode come from @mqtt-home/ui
    (tokens.css + embed.css only: no web fonts on the ESP32's SPIFFS, the page
    keeps its system font stack and its own components). The prepaint script
    comes from the package's vite plugin; index.html and main.tsx no longer
    carry a copy. Overrides keep the look unchanged (the single-radial canvas
    mesh, header padding and seg width in embed mode).
    Dependency update: preact 11, jsdom 30.1.3, vitest 5.0.5.
    Needs a SPIFFS + firmware OTA (make ota-all-prod) to go live.

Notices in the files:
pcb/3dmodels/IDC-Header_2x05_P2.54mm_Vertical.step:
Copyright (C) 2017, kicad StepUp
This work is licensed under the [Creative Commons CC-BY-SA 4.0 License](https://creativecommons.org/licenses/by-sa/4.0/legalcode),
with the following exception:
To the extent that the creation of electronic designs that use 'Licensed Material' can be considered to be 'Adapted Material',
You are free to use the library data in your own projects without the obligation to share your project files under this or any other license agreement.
